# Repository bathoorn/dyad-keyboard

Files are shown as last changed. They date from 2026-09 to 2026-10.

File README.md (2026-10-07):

# Dyad

A split keyboard with a rotary encoder ring on each half — a round display
inside the left ring, a circular trackpad inside the right. Custom PCBs in
KiCad, a 3D-printed case, running QMK.

*Dyad: a pair. Two halves, two dials, two boards.*

Layout

69 keys, 32 left and 37 right, row-staggered. Bare RP2040 on each side.

---

## The idea that makes it work

"A display on top of a knob" normally means the display rotates, which needs a
slip ring or a wire loom that survives unlimited rotation.

Dyad inverts it. **The display and trackpad are static; the ring rotates around
them.** A fixed centre post rises through the bearing bore and cantilevers the
sensor above the moving parts, so no wire ever moves. Visually and
ergonomically it reads as a knob with a screen on top — electrically it's a
static part with a ring turning beneath it.

Both rings are 50 mm outside diameter, so the halves are a matched pair.

## Hardware

| | |
|---|---|
| MCU | Bare RP2040, one **shared controller module** used by both halves |
| Left pod | GC9A01 1.28" round LCD, 240×240, SPI |
| Right pod | Cirque Pinnacle TM040040, 40 mm |
| Encoders | EC11, driven by a ring gear from the rotating ring |
| Switches | MX hot-swap, Kailh sockets |
| Per-key RGB | SK6812MINI-E — footprints fitted, populated only if wanted |
| Split link | USB-C to USB-C, half-duplex serial |

Four board designs: one controller module (the only board needing an assembly
service), two asymmetric main PCBs, and two knob-module variants.

## Status

| Phase | State |
|---|---|
| 0 — Layout | **Done.** Validated against printed 1:1 mock-ups. |
| 1 — Bench bring-up | **Partial.** Toolchain, flashing, encoder and Cirque all pass. Display, ribbon-SPI, split and current tests await parts. |
| 2 — Knob mechanism | Not started. |
| 3 — KiCad | Main PCBs generated and placed; controller pin assignment and BOM settled. |
| 4 — Case | Not started. Board outlines and plate cutouts exported for it. |

The main PCBs are a **placement scaffold**, not a finished layout. DRC reports
195 violations on the left and 253 on the right, **none** electrical (shorts,
clearance, mask bridges). The 32 and 37 errors are all diode/switch courtyard
overlaps from the deliberate diode-under-switch placement; the rest is
silkscreen. Routing is incomplete, notably the angled thumb keys.

## Repository

```
docs/          PLAN.md, WORKFLOW.md, CONTROLLER.md, PHASE1.md, TOOLS.md,
               GIT.md, plus printable 1:1 mock-ups
hardware/
  interface.yaml   the contract between the PCB and case designs
  layout/          KLE source of truth, parser, pod-placement solver
  pcb-main-*/      the two main PCBs (generated)
  pcb-controller/  controller module, and the vendored RP2040 reference
  outlines/        board outlines, plate cutouts and STEP, for the case
firmware/      QMK external userspace
```

Nearly everything under `hardware/` is **generated** from the KLE layout.
Regenerate with `hardware/generate_main_pcbs.py`, `export_outlines.py` and
`export_plate.py` — see `docs/TOOLS.md` for the environment they need.

## Building the firmware

```bash
qmk config user.qmk_home=~/qmk_firmware
qmk config user.overlay_dir=$PWD/firmware
ln -sfn $PWD/firmware/keyboards/dyad ~/qmk_firmware/keyboards/dyad
qmk compile -kb dyad/split -km default
```

The symlink is required: QMK's external userspace holds keymaps and build
targets, but **not keyboards**.

`dyad/proto` and `dyad/split` are Phase 1 bring-up targets for dev boards, not
the shipping keyboard definition.

## Documentation

- **[PLAN.md](docs/PLAN.md)** — the full design, decisions and rationale
- **[WORKFLOW.md](docs/WORKFLOW.md)** — how the case and PCBs are co-designed
  without deadlocking
- **[CONTROLLER.md](docs/CONTROLLER.md)** — controller pin assignment, BOM and
  build steps
- **[PHASE1.md](docs/PHASE1.md)** — bench bring-up, with results
- **[TOOLS.md](docs/TOOLS.md)** — toolchain, and the traps found in it
- **[GIT.md](docs/GIT.md)** — feature branches, and why KiCad files change how
  git is used here

## Licence

MIT — see [LICENSE](LICENSE).

`hardware/pcb-controller/upstream/` vendors
[RP2040-designguide](https://github.com/calliah333/RP2040-designguide)
(MIT, © 2021 Sleepdealer) as a read-only reference. The key layout originates
from the *Hasukey* KLE layout.

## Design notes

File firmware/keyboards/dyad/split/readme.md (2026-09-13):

# Dyad — split proto

Phase 1 steps 7 and 8: two Pico_Mini boards over a TRS cable, Cirque on the
**slave** half.

```bash
qmk compile -kb dyad/split -km default
qmk flash   -kb dyad/split -km default   # flash BOTH boards with this same binary
```

One binary for both halves — `SPLIT_HAND_PIN` decides which is which.

## Wiring

| Pin | Left board | Right board |
|---|---|---|
| GP0 | TRS **tip** — serial data | TRS **tip** |
| GP12 | → **3V3** (this makes it the left/master) | → **GND** |
| GP2–GP5 | *(nothing)* | Cirque SPI0: SCK / SDI / SDO / CS |
| GP6–GP9 | 2×2 matrix | 2×2 matrix |
| GP10, GP11 | EC11 A / B | EC11 A / B |

**TRS cable:** tip = DATA (GP0 ↔ GP0), ring = **5V** (5V pin ↔ 5V pin),
sleeve = GND.

### Plug USB into the LEFT board only

Both halves are powered through the cable's 5 V conductor. QMK decides
master/slave by which side sees USB, so if you plug both in, **both believe
they are master** and the split will not work.

It also means the two USB 5 V rails would be tied together through the cable.
Not usually destructive, but there is no reason to risk it.

### If the link is flaky

Half-duplex serial wants the data line idling high. Add a **4.7 kΩ pull-up
from GP0 to 3V3** on one side. QMK's internal pull-up is often enough on a
short cable and often is not on a long one.

## What to check

| | Expect |
|---|---|
| Left matrix | `A` `B` `C` `D` |
| Right matrix | mouse 1, mouse 2, `E`, `F` |
| Left encoder | volume |
| Right encoder | page up/down |
| **Trackpad on the right half** | cursor moves — this is step 8, the real test |

The trackpad is the point. It proves pointing-device data crosses the split
from the slave, which is what PLAN.md §5 assumed when it put USB in the left
half and the display on the master.

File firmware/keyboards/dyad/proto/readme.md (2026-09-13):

# Dyad — proto

Phase 1 bring-up target. **Not** the shipping keyboard definition.

```bash
qmk compile -kb dyad/proto -km default
qmk flash   -kb dyad/proto -km default   # hold BOOTSEL while plugging in
```

## Wiring — WinWin Pico_Mini RP2040

| Pins | Peripheral | Notes |
|---|---|---|
| GP2 / GP3 / GP4 / GP5 | Cirque TM040040 | SPI0 SCK / SDI / SDO / CS. DR unwired, so the driver polls. |
| GP6, GP7 / GP8, GP9 | 2×2 matrix | cols / rows, COL2ROW. Nothing need be wired. |
| GP10, GP11 | EC11 A / B | Encoder common (middle pin) → GND. QMK enables internal pull-ups. |

### EC11

Three pins on one side: **A — common — B**. Wire A to GP10, B to GP11, and the
middle pin to GND. The two pins on the opposite side are the push switch.

**Knock off step 2 for free:** the push switch is just a normally-open switch,
so wire it into the matrix as position `[0][0]` — one leg to col `GP6`, the
other through a 1N4148 (band toward the row) to row `GP8`. Pressing the knob
then sends `MS_BTN1` and proves the matrix scan at the same time.

## What it does

| Input | Result |
|---|---|
| Trackpad | Cursor movement |
| Encoder rotation | Volume down / up |
| Matrix `[0][0]` / `[0][1]` | Mouse button 1 / 2 |
| Matrix `[1][0]` / `[1][1]` | `A` / `B` |

## If the encoder misbehaves

Two detents per click, or one click per two detents, is a **resolution**
mismatch, not a wiring fault. Add `"resolution": 2` (or `4`) to the rotary
entry in `keyboard.json`. Direction reversed: swap `pin_a` and `pin_b`.

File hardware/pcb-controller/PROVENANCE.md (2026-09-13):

# Upstream reference: RP2040-designguide

Vendored from **https://github.com/calliah333/RP2040-designguide**
at commit `2023-02-13` ("Merge branch 'main'"), MIT licensed,
**Copyright (c) 2021 Sleepdealer** — see `LICENSE`, retained unmodified as MIT
requires.

This is a **read-only reference**, not the Dyad controller. Do not edit it in
place; the Dyad board is `../dyad-controller.kicad_pcb`.

## Why this one

- MIT, so it can be used and adapted in an MIT project with attribution.
- **2-layer**, independently confirming the layer-count decision in PLAN.md §4.
- Carries a vetted RP2040 QFN-56 footprint *and* a STEP model, which the stock
  KiCad libraries do not provide together.
- Decoupling matches what the minimal design example calls for: 10 × 100 nF,
  1 µF and 10 µF bulk, 2 × 22 pF crystal loads.

## What was left behind

`Pico-Resources/` (41 MB) — the RP2040 datasheet, the Pico schematic and
*Hardware design with RP2040*. Freely available from Raspberry Pi, and too
large to justify vendoring. Download them directly when running the §4
schematic diff.

## Age

Last real commit February 2023, KiCad 6 file format (`version 20211014`).
KiCad 10.0.6 loads it without complaint — verified: 36 footprints, 59 nets,
2 copper layers. Expect a format-upgrade prompt on first save.

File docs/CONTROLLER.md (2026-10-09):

# Controller module

One design, used on **both** halves. The only board in the project that needs
an assembly service, and the one Phase 4.5 orders first and alone.

Envelope: **50 × 35 mm, ≤10 mm above the PCB**, 2-layer, 1.6 mm.
Tallest parts are now the tactile buttons (~5 mm); the USB-C receptacles are ~3.2 mm. Dropping the 3.5 mm jack freed real height.
Fixed by decree (`interface.yaml`) — the case guarantees the volume, the board
fits inside it, neither renegotiates. See `docs/WORKFLOW.md` §2.

---

## 1. Pin assignment

30 GPIO available (GP0–GP29). USB and QSPI are on dedicated pins and cost
nothing from this budget.

| GPIO | Function | Constrained? |
|---|---|---|
| GP0 | HANDEDNESS — from the main PCB | no |
| GP1–GP8 | MATRIX_COL7–0 (GP1 = COL7 … GP8 = COL0) | no |
| GP9–GP13 | MATRIX_ROW0–4 | no |
| GP14 | RGB_DATA — WS2812/SK6812, PIO | no |
| GP15 | SPLIT_SERIAL — half-duplex, PIO | no |
| GP16 | **KNOB_D0** — SPI0 RX *or* I²C0 SDA | **yes** |
| GP17 | **KNOB_D1** — SPI0 CSn *or* I²C0 SCL | **yes** |
| GP18 | KNOB_SCK — SPI0 SCK | **yes** |
| GP19 | KNOB_MOSI — SPI0 TX | **yes** |
| GP20 | KNOB_CS — display chip select (software CS) | no |
| GP21 | KNOB_DC — display data/command | no |
| GP22 | KNOB_RST — display reset | no |
| GP23 | KNOB_BL — display backlight (PWM) | no |
| GP24 | KNOB_DR — Cirque data-ready | no |
| GP25 | ENC_A | no |
| GP26 | ENC_B | no |
| GP27, GP28, GP29 | **spare** | all three ADC-capable |

**Reassigned 2026-10-07** for routing -- see *Why this assignment* below. The
first assignment (knob on GP0–10, matrix on GP12–26) predates any placement
and is in git history. The schematic carries this table: U3's labels name the
physical pin, and only the connector-side labels moved.

**27 used, 3 spare.**

Only four pins are actually pinned down by silicon. Everything else — chip
selects, DC/RST/BL, the encoder, the matrix, the split link, RGB — is free
choice, because RP2040 drives software CS on any pin and PIO reaches any pin.

### GP16/GP17 settle the Cirque bus question by not answering it

`docs/PHASE1.md` §5a left one decision open: the plan puts the Cirque on I²C,
but the bench module is SPI-strapped and works. That decision does **not** need
making before this board is laid out.

RP2040's function map overlaps exactly where it helps:

| Pin | As SPI | As I²C |
|---|---|---|
| GP16 | SPI0 RX (MISO) | I²C0 SDA |
| GP17 | SPI0 CSn | I²C0 SCL |

So both lines go to the knob connector as **KNOB_D0/KNOB_D1**, and the choice
is made in firmware plus how the *knob module* wires its two pads. The
controller is identical either way, and the same 14-pin connector serves both
knob variants. Neither costs an extra pin.

### Why this assignment: routing (2026-10-07)

The first assignment was chosen before any placement existed, and it put the
knob bus on the side of the RP2040 that faces *away* from the knob FFC. The
table above replaces it, derived from geometry as §2 asks. **Applied to the
schematic 2026-10-07.**

**Placement it assumes** (decided 2026-10-07): parts on **B.Cu**, as upstream;
board **35 wide x 50 deep** (lengthened to **57 mm** on 2026-10-09 -- see §6
results), so the side edges are the long ones. U3 keeps
its upstream orientation (B, 180 deg), which is the only one that points its
USB/QSPI face at the rear edge and J1. All directions below are KiCad's top
view, front = +y.

| RP2040 face | Pins | Faces | Carries |
|---|---|---|---|
| USB/QSPI | 43-56 | rear | J1, flash -- unchanged |
| GP12-17, XIN/XOUT, SWD, RUN | 15-28 | front | crystal, SWD, RUN; knob from GP16 leftward |
| GP18-29 | 29-42 | left | knob (GP18-26), spares |
| GP0-11 | 1-14 | right | matrix bus |

**Connector pin 1, on B.Cu** (measured on main-right's J1, which uses the same
footprint family: the cable enters on the mounting-pad side):

- J8, front edge, opens +y: pin 1 on the **right**, pins run right to left.
- J7, right edge, opens +x: pad 1 at the **rear**, pad 20 at the front.
- J6, left edge, opens -x: pad 1 at the **front**, pad 20 at the rear.

**The knob keeps the dual-function trick.** GP16/GP17 overlap exactly as
GP0/GP1 do -- SPI0 RX/CSn *and* I²C0 SDA/SCL -- with SPI0 SCK/TX on GP18/GP19.
The whole knob group is now one contiguous run of 11 pins wrapping the
front-left corner, fanning straight into J8 with no crossings.

**J8 changes in one place.** Arriving right to left, the chip presents
D0, D1, SCK, MOSI, CS, DC, RST, BL, DR, ENC_A, ENC_B. So the §2 table's
pins 3-6 were reordered to **3 D0, 4 D1, 5 SCK, 6 MOSI** (they were SCK,
MOSI, D0, D1); pins 7-13 are unchanged. The knob module does not exist yet,
so this cost nothing.

**The matrix leaves the chip as one ordered bundle to the right.** GP0-15,
read rear to front around the front-right corner, run HAND, COL7..COL0,
ROW0..ROW4, LEDIN, SPLIT. That is J7's pad order exactly (rear to front:
1 HAND, 3-10 COL7..COL0, 11-15 ROW0..ROW4, 17 LEDIN), so J7 is crossing-free,
with SPLIT outermost, toward J9 if J9 sits in front of J7.

**J6 is reached by wrapping the rear of the chip, and that wrap is free.** J6
presents the same nets in the *opposite* front-to-rear order, because it is
J7 rotated 180 degrees. A bundle that turns three corners around the rear of the
chip reverses its order once on the way, which is exactly the reversal J6
needs. So the §2 worry that an identical assignment "must cross all 20 nets"
does not hold here, and J6/J7 can keep the same net-to-pad table.

**What it still costs:** one layer change per net. On a single layer, at most
two nets can each reach both side edges past a chip in the middle, so this is
inherent, not a pin-order problem. Where each net splits into its J7 branch
and its J6 branch, one branch has to hop under its neighbours. Keep the long
wrap bundle on **B.Cu** (component side, in a part-free band behind the chip
and flash) and make only the short hops on F.Cu, so the F.Cu ground plane is
slotted briefly, not cut across. USB D+/D- also cross that band, as a short
F.Cu hop of their own. The power pads interleaved with the signals (3V3 at
pad 2, GND at 16/18) take a via each.

**Placement this implies:** J1, ESD, F1 and D1 along the rear; a component-free
band of ~7 mm behind U3+U1 for the wrap; J6/J7 on the side edges level with
U3, J9/J10 in front of them; crystal and SWD in front of U3, to the right of
the knob bundle, with J8 at front-left.

**As built (2026-10-09), the side edges are the other way round:** split
USB-C J10/J9 on top (y 29 from the rear edge), main FFC J6/J7 below them
(y 41.8), on the 57 mm board. The 20-pin FFCs need far more routing room
than the three-net USB-C ports, and the lower half of the board has it --
moving them there is what finally kept the matrix bundle from crossing
under the USB and QSPI routing (§6 results). The SWD header no longer
exists (§4).

**Open before applying:**

- `interface.yaml` has no `positions_controller` yet, and the cable type A/B
  question in §2 still stands. Everything here assumes a straight, unfolded
  ribbon.
- The ground-pour layer moves with the parts. With parts on B.Cu, **F.Cu** is
  the continuous plane that PLAN.md asks for, not B.Cu as §2 says.
- Firmware is unaffected for now: `dyad/proto` and `dyad/split` use the
  bench rig's wiring, not the controller's.

---

## 2. Connector pinouts

**Knob FFC, 14-pin 0.5 mm** — 11 signals + power. **In the schematic as J8
since 2026-09-18.**

**The `#` column below is the CONTROLLER's pin numbering**, which is how J8
is wired. The knob module does not exist yet, so it will be designed to
match: for a facing, straight, unfolded ribbon its pads are the reverse,
`knob pad m = controller pin (15 - m)` — the same relation as the main FFC,
for the same reason. Do not wire the knob module off this table directly.

| # | Signal | Display variant | Cirque variant |
|---|---|---|---|
| 1 | 3V3 | ✓ | ✓ |
| 2 | GND | ✓ | ✓ |
| 3 | KNOB_D0 | — | MISO *or* SDA |
| 4 | KNOB_D1 | — | CS *or* SCL |
| 5 | KNOB_SCK | SCK | SCK *(SPI mode)* |
| 6 | KNOB_MOSI | SDI | SDI *(SPI mode)* |
| 7 | KNOB_CS | display CS | — |
| 8 | KNOB_DC | D/C | — |
| 9 | KNOB_RST | RST | — |
| 10 | KNOB_BL | backlight | — |
| 11 | KNOB_DR | — | data-ready |
| 12 | ENC_A | ✓ | ✓ |
| 13 | ENC_B | ✓ | ✓ |
| 14 | GND | ✓ | ✓ |

**Main FFC, 20-pin 0.5 mm:** 13 matrix + handedness + RGB_DATA + 3V3 + 2× 5V
+ 2× GND. The doubled 5 V and GND are the per-key RGB return path; a 0.5 mm
FFC conductor is good for roughly half an amp. See PLAN.md §5.

**This table is the MAIN PCB's pin numbering, not the controller's.** The
controller's pads are the reverse of it -- see *Facing connectors reverse*
below. Wiring the controller straight off this table is the single easiest
way to get the whole link backwards.

Pin assignment on **both main PCBs**, fixed by main-right and matched by
main-left:

| Pin | Net | | Pin | Net |
|---|---|---|---|---|
| 1 | VCC (5 V) | | 11 | COL0 |
| 2 | VCC (5 V) | | 12 | COL1 |
| 3 | GND | | 13 | COL2 |
| 4 | LEDIN | | 14 | COL3 |
| 5 | GND | | 15 | COL4 |
| 6 | ROW4 | | 16 | COL5 |
| 7 | ROW3 | | 17 | COL6 |
| 8 | ROW2 | | 18 | COL7 *(idle on left)* |
| 9 | ROW1 | | 19 | +3V3 |
| 10 | ROW0 | | 20 | HAND |

Rows descend where columns ascend -- ascending rows made the five row traces
cross on their way to the connector. LEDIN sits between the two GNDs because
it is the only fast edge on the cable.

### Facing connectors reverse: controller pad n carries main pin 21-n

The main PCB's connector and the controller's face each other across the
ribbon. Two identical right-angle parts opening toward one another are
rotated 180 degrees about z relative to each other, so the topmost conductor
in the ribbon lands on pin 1 at one end and pin 20 at the other:

    main pin n  <->  controller pad (21 - n)

**This reversal is identical on both halves, which is why it costs nothing.**
Right half: main-right opens inward (-x), the controller's right-edge part
opens +x -- 180 degrees apart. Left half: main-left opens inward (+x), the
controller's left-edge part opens -x -- also 180 degrees apart. Check it on
the topmost conductor: on the right it joins controller pad 20 to main pin 1;
on the left it joins controller pad 1 to main pin 20. Same `21-n` relation.

So **both controller footprints take the same net-to-pad assignment**, and
both mains keep the same pinout. The reversal is absorbed once, here.

Written out -- **corrected 2026-09-18**, the first transcription of this
table was wrong and is why it carried a "not verified" warning. It repeated
COL0-6 in both halves and omitted ROW3, ROW4, both GNDs, LEDIN and both
VCCs. Derived here pad by pad as `pad m = main pin (21 - m)`, and the
right-hand column gives the controller's own net name:

| Pad | Signal | Net | | Pad | Signal | Net |
|---|---|---|---|---|---|---|
| 1 | HAND | GPIO0 | | 11 | ROW0 | GPIO9 |
| 2 | +3V3 | +3V3 | | 12 | ROW1 | GPIO10 |
| 3 | COL7 | GPIO1 | | 13 | ROW2 | GPIO11 |
| 4 | COL6 | GPIO2 | | 14 | ROW3 | GPIO12 |
| 5 | COL5 | GPIO3 | | 15 | ROW4 | GPIO13 |
| 6 | COL4 | GPIO4 | | 16 | GND | GND |
| 7 | COL3 | GPIO5 | | 17 | LEDIN | GPIO14 |
| 8 | COL2 | GPIO6 | | 18 | GND | GND |
| 9 | COL1 | GPIO7 | | 19 | VCC 5 V | **+5V** |
| 10 | COL0 | GPIO8 | | 20 | VCC 5 V | **+5V** |

Count check: HAND 1, +3V3 1, COL0-7 8, ROW0-4 5, GND 2, LEDIN 1, VCC 2 = 20.

**The 5 V pins land on `+5V`, not `VBUS`.** `VBUS -> F1 -> +5V`, so `+5V` is
the *fused* rail, and §3 already notes the fuse is deliberately in the LED
path -- which is the whole reason it needs upsizing if RGB is populated.
Taking the FFC's 5 V from VBUS instead would put the LED current outside the
fuse and quietly defeat that.

### The two footprints need not share an assignment -- and probably should not

The footprints are separate copper. Nothing forces them to carry the same
net-to-pad order, and **that is the mechanism for reversing one half's
pinout without touching the other.** If main-left wants its pins reversed to
ease routing, the controller's left-edge footprint absorbs it and the MCU
never knows. No firmware asymmetry: this **supersedes** the
`MATRIX_ROW_PINS_RIGHT` escape hatch named in MANUAL_TASKS.md, which cost a
permanent left/right difference in the build.

There is a second, independent reason to expect the reversal, and it is
about the *controller's own* routing. Number pad positions by height `y`,
with both footprints opening outward on opposite edges so they sit 180
degrees apart:

    identical assignment   net j at y = 21-j  (right)   y = K-j  (left)
                           -> the two run in OPPOSITE directions, so a
                              centre-mounted MCU must cross all 20 nets to
                              reach the left connector

    reversed on the left   left pad m = net m, right pad m = net 21-m
                           -> net j at y = 21-j and y = K-j, both falling
                              at the same rate: a PARALLEL fan-out, no
                              crossings

The controller is **2 layers**, and B.Cu is the ground pour that PLAN.md
requires to stay continuous under the MCU. Twenty crossings would be twenty
via pairs punched through exactly that copper. So the reversal plausibly
buys clean routing here as well as on main-left.

**Not proven.** This is a topology argument about a layout that does not
exist -- the controller outline is still the 45.31 x 93.52 mm reference
shape, not the 50 x 35 envelope. It assumes both footprints sit on the same
side of the board, on opposite edges, opening outward. Put one on the
opposite copper layer and they are mirrored rather than rotated, and the
ordering changes. Confirm it against the real placement before relying on
it, and **derive both pad tables from geometry at schematic time rather than
transcribing them.**

**Caveat, and it is the live one.** All of the above assumes the boards are
effectively coplanar and the ribbon runs **straight and unfolded**. If the
controller ends up stacked under the main PCB with a folded ribbon, the
mapping changes -- a fold reverses conductor order *and* flips the contact
face.

So treat **(controller pad assignment, cable type A/B)** as a pair with one
degree of freedom: a type-B cable flips the reversal straight back. Fix one
and the other follows. Neither can be finalised until
`positions_controller` and the ribbon path are settled -- both still TODO in
`interface.yaml`. The main pinout is the only part that is genuinely frozen.

### The 5 V OR-ing network (added 2026-09-18)

PLAN.md §5 rule 3 asks for a fused split VBUS and an OR-ing Schottky. Where
the Schottky goes is not free choice — it is what decides whether one half
can power the other:

```
  host VBUS ──F1──► VBUS_FUSED ──►|D1──┬──► +5V  (LDO, ESD, LED rail via J6/J7)
                                        │
                     split VBUS ──F2────┘        (J9/J10, to the other half)
```

`+5V` is the **shared node**: it feeds this half and reaches the other half
through F2 and the cable. Each half's own VBUS enters through its own D1,
so two hosts can never be connected VBUS-to-VBUS — which is the actual
hazard rule 3 names. One port still powers both halves, because the shared
node crosses the link.

**Why not the obvious alternatives.** A diode on *each* input into +5V
(host and split) blocks cross-half power entirely — neither half can feed
the other. A diode only on the split *input* is worse: the receiving half
gets power but no half can ever send it. The Schottky has to sit in the
**host** path for the shared node to work.

**Consequence worth pricing in: `+5V` is now ~4.6 V, not 5.0 V.** SS34 drops
about 0.4 V at 1 A. Everything downstream still has margin — XC6206 needs
~3.55 V in for 3.3 V out, and SK6812MINI-E is specified from 3.7 V — but
**PLAN.md §5's per-key RGB brightness budget assumes a 5 V rail** and should
be re-checked against 4.6 V before the LED ceiling is treated as final.

SS34 was chosen over the 1 A B5819W (C8598, also Basic) for headroom: with
one port feeding both halves at capped RGB brightness the diode carries the
whole board, and 3 A leaves room. F2 reuses F1's part and footprint.

### Port placement: host to the rear, split duplicated on the side edges

**Decided 2026-09-18.** The host USB-C (J1) stays a **single** footprint on
the **rear** edge. The split USB-C is **duplicated** on the left and right
edges as J9/J10, one populated per half — whichever faces the other half.

The single controller orientation that the two-FFC decision buys means a
rear-edge port lands identically in both halves, so the host needs no
duplicating. The split port is duplicated for **usability, not geometry**:
§5 of PLAN.md warns that "two identical USB-C ports per half invite the
wrong cable. Distinguish them by case position and labelling." Two ports
side by side on the rear are *not* distinguishable by position — and on the
slave half, where no host cable is plugged in, there is nothing to compare
against. Putting the split port on the inboard edge makes it structurally
unmistakable: the cable that goes to the other half comes out of the side
that faces it.

Each side edge therefore carries one main FFC and one split USB-C, and
exactly one of each pair is populated, on **opposite** edges:

| Edge | Left half populates | Right half populates |
|---|---|---|
| left | J6 main FFC | J10 split USB-C |
| right | J9 split USB-C | J7 main FFC |
| rear | J1 host USB-C (always) | J1 host USB-C (always) |
| front | J8 knob FFC (always) | J8 knob FFC (always) |

Edge budget: each side edge carries 13 mm of FFC + ~9 mm of USB-C = 22 mm,
against 35 mm if the board is oriented 50 wide by 35 deep. Tight but
workable; if it binds, orienting the board the other way gives the side
edges 50 mm. **As built:** turned (2026-10-07) and lengthened to 57 mm
(2026-10-09), so each side edge is 57 mm, carrying the split USB-C
(courtyard 10.7 mm) above the main FFC (14.5 mm), with the BOOTSEL / RESET
button and a corner mounting hole above them.

**Stubs are not a concern here.** RP2040 is USB 1.1 **Full Speed, 12 Mbps**
(PLAN.md §Routing), so the unpopulated footprint's stub is electrically
irrelevant. That is why duplicating a USB-C costs only board area.

**D+/D- is deliberately left unconnected on the split ports.** The split
link is not USB — it carries half-duplex serial on SBU. Wiring D+/D- there
would mean a C-to-C split cable shorting the two halves' RP2040 USB data
lines together, with both device PHYs driving. CC1/CC2 and both D pairs
carry explicit no-connect flags on J9 and J10.

### Two main-FFC footprints, one populated (decided 2026-09-18)

**The controller carries the 20-pin footprint on two edges, wired to the
same nets, and only the one facing that half's main PCB is fitted.**

Each half's J1 sits on its *inner* board edge, so the two cable approaches
are mirror images. A mirror is not a rotation: turning the controller 180
degrees swaps left/right *and* top/bottom, putting the main FFC on the right
edge but USB-C on the wrong one. Only flipping the board over truly mirrors
it, and that faces every component at the case floor and inverts the USB-C.

With two footprints, each one's orientation is chosen independently, so the
mirror is absorbed here in copper -- on the board WORKFLOW.md §2 names as
having "enormous slack" and costing ~$15 to respin, rather than on the mains
which have none and one of which is already routed. Both halves then share
one cable type, one logical pinout and one firmware build.

Consequences for layout:

- Budget about **13 mm of edge twice** for the 20-pin parts, plus ~9 mm for
  the knob FFC and ~9 mm each for the two USB-C -- roughly **53 mm of the
  ~170 mm perimeter**.
- The unpopulated footprint leaves a **stub on all 20 nets**. Irrelevant for
  matrix and power; keep the LEDIN stub short, since it is the only line
  with fast edges.
- `interface.yaml` must eventually say **which** edge is populated per half,
  since the case has to admit the ribbon from the correct side.
- Cable type A vs B is now settleable: both connector orientations are fixed
  by this decision plus main-left's placement.

---

## 3. BOM

**Inherited from the reference, LCSC codes already populated** (31 parts, 14
distinct codes — nothing to look up):

| Ref | Part | LCSC | |
|---|---|---|---|
| U3 | RP2040, QFN-56 | **C2040** |
| U1 | W25Q128JVS, 16 MB SOIC-8 | **C131025** |
| Y1 | Abracon ABM8-272-T3, 12 MHz, CL 10 pF, 3225 4-pin | **C20625731** | ← **swapped 2026-10-07**, see below |
| U2 | USBLC6-2SC6 ESD, SOT-23-6 | **C2827654** |
| U4 | XC6206 LDO 3.3 V / 200 mA, SOT-23 | **C5446** |
| J1 | USB-C receptacle, HRO TYPE-C-31-M-12 | **C165948** |
| F1 | 500 mA fuse, 1206 | **C70076** | ← **upsize if RGB is populated**: it is in the LED path
| C1–C17 | 10× 100 nF, 4× 1 µF, 1× 10 µF, 2× 15 pF (C2/C3), all 0402 | C1525 / C52923 / C15525 / **C1548** |
| R1,R2,R7 | 1 kΩ 0402 | C11702 |
| R3,R4 | 5k1 CC 0402 | C25905 |
| R5,R6 | 27 Ω 0603 | C25190 |

**The inherited crystal did not match its load caps.** The reference design
carried LCSC C9002 (YXC X322512MSB4SI): CL **20 pF**, ESR **80 Ω**, with
22 pF load caps. Those give ~11 + 3 pF stray = ~14 pF against the 20 pF it
needs, so it would run fast -- and its 80 Ω ESR is above the 50 Ω that
*Hardware design with RP2040* §2.3 relies on when sizing the 1 kΩ XOUT
series resistor, so start-up margin was unknown. The guide says any other
crystal circuit "will require extensive testing". Swapped to the guide's own
circuit unchanged: ABM8-272-T3 (CL 10 pF, ESR ≤ 50 Ω), two 15 pF caps
(7.5 pF + ~3 pF stray = 10.5 pF), 1 kΩ (R7). Same 3.2 × 2.5 mm 4-pad
package and pin-out, so the footprint and routing are unchanged. Found by
the §6 checklist, item 3.

Passives are 0402. That is finer than the "0805, hand-solderable" assumption in
PLAN.md §10, but these are on the *assembly* BOM — JLCPCB places them, so it
does not matter.

**Still to add — none of these exist on a bare dev board.** Now **in the
schematic** and footprinted: J6 (main FFC, left), J7 (main FFC, right),
J8 (knob FFC), J9/J10 (split USB-C, one per side edge), F2 (split-VBUS
fuse), D1 (OR-ing Schottky), and SW1/SW2 (BOOTSEL and RESET). Still absent:
the DNP 74AHCT125 level shifter, and conditionally the LDO swap — which is
the only remaining item from §4, and is gated on a Phase 1 measurement.

| Block | Part | LCSC | Note |
|---|---|---|---|
| Split | **USB-C receptacle** (**two** placements) | **C165948** | Same part as J1 — no new line on the BOM. CC1/CC2 **unconnected**; serial on SBU1+SBU2 tied; fuse its VBUS. **In the schematic as J9 and J10 since 2026-09-18**, one per side edge, **one populated per half**. |
| Knob FFC | HC-FPC-0.5-**14P**-FH20 | **C19273929** | 0.5 mm, flip-top, right-angle, bottom contact. **In the schematic as J8 since 2026-09-18**, footprint `dyad:FPC-SMD_14P-P0.50_HC-FPC-0.5-14P-FH20`. |
| Main FFC | HC-FPC-0.5-**20P**-FH20 | **C19273932** | 20-position sibling. Confirmed 2026-09-18: JLCPCB Extended, 1,893 in stock, $0.076/1-99. **Two footprints** -- see §2. **In the schematic as J6 (left) and J7 (right) since 2026-09-18**; population per board still open. |
| Level shift | 74AHCT125 | *verify* | **DNP**, 0 Ω bypass. RGB only. |
| Power OR | **SS34** Schottky, SMA | **C8678** | Stops one half back-feeding the other. JLCPCB **Basic**, 3 A / 40 V. **In the schematic as D1 since 2026-09-18.** |
| Buttons | **TS-1187A-B-A-B**, 5.1×5.1 mm SMD | **C318884** | SW1 (BOOTSEL) + SW2 (RESET). JLCPCB **Basic**, 679k stock. KiCad ships the matching footprint, `Button_Switch_SMD:SW_Push_1P1T_XKB_TS-1187A`, whose pads are numbered 1,1,2,2 so the 2-pin `SW_Push` symbol fits directly. **In the schematic since 2026-09-18.** |
| LDO *(conditional)* | AP2112K-3.3, SOT-23-**5** | *verify* | Only if Phase 1 measures above ~120 mA. Not a drop-in — see §4. |

LCSC codes marked *verify* should be pulled with `easyeda2kicad` at schematic
time so the design-side footprint matches the assembly-side part exactly
(see `docs/TOOLS.md`).

### FFC connector choice

Staying at **0.5 mm pitch**. 1.0 mm parts (e.g. Amphenol F516) are easier to
hand-solder and carry more current, but neither helps here: JLCPCB places
these, and the doubled 5 V/GND conductors already give ~1 A against ~0.4 A per
half for RGB at capped brightness. What 1.0 mm does cost is board edge — a
20-position part is ~23 mm wide instead of ~13 mm, on a 50 mm board whose other
long edge already carries USB-C and the jack.

**Right-angle, not vertical.** The same family's `LH20` variant (C49166895) is
a vertical slide-lock part: the ribbon exits perpendicular to the board and
must then bend, which wants headroom the 10 mm envelope does not have to spare.
`FH20` is right-angle, so the ribbon lies flat.

**Cable type is a real trap.** These are *bottom contact*. FFC cables come as
type A (contacts the same side at both ends) and type B (opposite sides). Which
one is correct depends on how both connectors end up oriented in layout, and
the wrong type silently reverses the pinout end to end. Settle it once the
layout fixes the orientations, not before.

---

## 4. Starting point: the RP2040 design guide

The MCU subsystem is not being drawn from scratch. `hardware/pcb-controller/upstream/`
vendors **calliah333/RP2040-designguide** (MIT, © 2021 Sleepdealer) as a
read-only reference — see its `PROVENANCE.md`. It is 2-layer, carries a vetted
QFN-56 footprint with a STEP model, and its decoupling already matches the
minimal design example.

Verified to load in KiCad 10.0.6 despite being KiCad 6 format: 36 footprints,
59 nets, 2 copper layers.

### What transfers unchanged

RP2040 + QFN-56 footprint, W25Q128JVS (exactly our 16 MB flash), the 12 MHz
crystal's footprint and 1 kΩ series resistor (the crystal itself and its load
caps did **not** transfer -- see §3), USBLC6-2SC6 ESD, USB-C with 27 Ω series and 5k1 CC resistors,
the full decoupling network, and a 500 mA VBUS fuse. Its SWD header (J2) was
carried over and then **removed 2026-10-07**: the 13.8 x 3.6 mm through-hole
socket was the largest single part on the board, and dropping it let the
RP2040 block move 4 mm forward so USB could be routed cleanly (see §6
results). Flashing is over USB with BOOTSEL; SWCLK/SWDIO (U3 pins 24/25) are
left unconnected. If SWD is ever wanted back, three small SMD test pads
(SWCLK, SWDIO, GND) would cost almost no board area.

### What must change

Item 1 is conditional on a measurement; 2–6 are unconditional.

| # | Change | Why |
|---|---|---|
| 1 | **LDO: XC6206 → AP2112K-3.3** *(only if measured >~120 mA)* | XC6206 is **200 mA**. Load is ~70–130 mA — RP2040 ~30, flash ~5, Cirque ~3, and the GC9A01 backlight 20–60. At the top of that range there is no margin left. **Not a drop-in:** SOT-23 3-pin → SOT-23-**5**, and EN must be tied to Vin or the rail never comes up. LEDs do **not** load this rail. Confirm against the Phase 1 measurement. |
| 2 | ~~**Add a RESET button**~~ **DONE 2026-09-18** | The guide has none. PLAN.md §4 treats it as non-optional. Added as SW2, `~{RESET}` to GND. |
| 3 | ~~**Replace SW1**~~ **DONE 2026-09-18** | Its BOOTSEL "switch" was a `PinSocket_1x02` header, not a button. Now a real tactile switch, same part as SW2. |
| 4 | ~~**Delete J3/J4/J5**~~ **DONE 2026-09-18** | Three 1×11 pin sockets — it is a Pico-style breakout. We want FFC connectors instead. Removed with their 33 stubs, 30 labels and 3 now-orphaned GND symbols. |
| 5 | **Add** a 2nd USB-C (split link), 20-pin + 14-pin FFC, 74AHCT125 (DNP), power OR-ing diode, split-VBUS fuse | None are in a bare dev board. The 2nd USB-C reuses J1's part and footprint. |
| 6 | **Reshape to 50 × 35 mm** | The guide's board is 45.3 × 93.5 mm. |

Items 1–3 are the ones that would ship a broken or unflashable board if missed.

## 5. Step by step

### Before you start

`upstream/` is a **read-only reference**. Nothing below edits it — after step 1,
`git status` should show no changes under `hardware/pcb-controller/upstream/`.
If it does, you saved into the wrong place.

Close KiCad before running any generator script in this repo. KiCad writes on
exit and will happily undo a regeneration.

### 1. Make the working copy

The upstream project carries its own project-local `fp-lib-table` and
`sym-lib-table`, and they point at `Libraries/` by **relative** path. Save-As
does not bring those along, so copy them first or the RP2040 symbol and
footprint go missing:

```bash
cd hardware/pcb-controller
cp -r upstream/Libraries upstream/fp-lib-table upstream/sym-lib-table .
```

Then in KiCad: open `upstream/RP2040-Guide.kicad_pro` → **File → Save As** →
into `hardware/pcb-controller/`, filename **`dyad-controller`**. Accept the
KiCad 6 → 10 format upgrade when prompted.

Commit at this point, before editing anything. It gives you a clean "unmodified
upstream, renamed" baseline to diff every later change against.

### 2. Schematic (Eeschema) — always before the PCB

Work the deltas from §4 in this order; it minimises rework.

1. ~~**Delete J3, J4, J5**~~ — **done 2026-09-18**, along with the 33 wire
   stubs, 30 labels and 3 GND symbols that fed only them.

   This left 15 ERC errors, which were the map of what was still missing:
   each removed header had been the second connection on its GPIO net.
   **The knob FFC (J8) cleared 11 of them**, leaving **4**: `GPIO11`, which
   clears with the second USB-C, and `GPIO27-29`, the three genuine spares,
   which want no-connect flags once that is confirmed final.
   Nothing else regressed: `endpoint_off_grid` fell 136 -> 94 and
   `lib_symbol_mismatch` 52 -> 49, because the headers took their own
   off-grid pins with them.
2. **Swap the LDO.** Replace U4 (XC6206) with AP2112K-3.3. This is a footprint
   change, not a value change: **SOT-23 3-pin → SOT-23-5**. Tie **EN to Vin** —
   left floating, the regulator never turns on and the board has no 3V3, which
   presents as a dead board rather than as a missing jumper. Dropout is not a
   factor either way: from 5 V there is 1.7 V of headroom.
3. ~~**Fix the buttons.**~~ **done 2026-09-18.** SW1's footprint was a
   `PinSocket_1x02`; it is now `Button_Switch_SMD:SW_Push_1P1T_XKB_TS-1187A`.
   SW2 added from `~{RESET}` (the RP2040's `RUN`, U3 pin 26) to `GND`, same
   part.

   Note when wiring to `~{RESET}`: it is a **global** label on this sheet, and
   `batch_connect_to_net` only writes local ones — which raises
   `same_local_global_label`. Use a global label there.
4. **Add the new parts:** PJ-320A jack, 20-pin and 14-pin FFC connectors,
   74AHCT125 (mark **DNP**, with a 0 Ω bypass), and the Schottky between VBUS
   and the jack's 5 V.
5. **Wire to the pin assignment in §1.** GP18/GP19 must be SPI0 SCK/MOSI and
   GP16/GP17 the dual-function pair — those four are fixed by silicon. The rest
   is free.
6. **Annotate**, then run **ERC** and get it clean.

### 3. PCB (Pcbnew)

7. **Tools → Update PCB from Schematic** (F8). Everything new lands in a heap
   off-board; that is expected.
8. **Replace the outline.** Delete all existing `Edge.Cuts` — the guide's board
   is 45.3 × 93.5 mm. Then **File → Import → Graphics**, choose
   `../outlines/dyad-controller-outline.dxf`, place it on **Edge.Cuts** at
   **scale 1.0**. It is 50 × 35 mm, normalised to the origin.
9. **Place the edge parts first**, because they are the real constraint:
   **both** USB-C receptacles on one long edge, both FFC connectors on the other.
   Separate the two USB-C ports as far as the edge allows and silkscreen them
   clearly — they are physically identical.
   Everything else fits around them.
10. **Then the MCU block** — keep RP2040, crystal and decoupling together and
    as the guide has them. Do not redistribute the decoupling.
11. **Route**, pour ground both sides, stitch the RP2040 centre pad with ~9
    vias, and run **DRC**.

### 4. Before ordering

12. Run the §6 checklist below, diffing block by block against *Hardware design
    with RP2040* Chapter 2.
13. **Add LCSC part numbers** to a symbol field named `LCSC` for every
    assembled part — that is what JLCPCB reads. Pull footprints with
    `easyeda2kicad` so the design-side part matches the assembly-side one.
14. Export gerbers, BOM and CPL (`kicad-cli pcb export gerbers` / `drill`, and
    the BOM/position files from Eeschema and Pcbnew).

## 6. Before ordering

Run the §4 checklist in `PLAN.md` — schematic diffed block-by-block against
Raspberry Pi's *Hardware design with RP2040* Chapter 2 minimal design example.
Boards that fail to enumerate are almost always boards that deviated from it.

The two that bite hardest:

- **BOOTSEL button is not optional.** Without it an unflashed board is a brick
  until you short pads with tweezers.
- **Ground pour continuity.** Easier here than it would have been on the main
  PCBs, because no matrix crosses this board. Stitch the centre pad with ~9
  vias and check the *poured* result, not the schematic intent.

**Correction to the last point:** the matrix *does* cross this board. J6 and
J7 carry the same 15 nets on opposite side edges, so the bundle has to get
past the RP2040's USB connections or its knob bus, and it does so on F.Cu --
the layer that would otherwise be the continuous ground. That is the root of
the ground-coverage numbers below.

### Checklist results (2026-10-07)

Run against *Hardware design with RP2040* (RP-008279-DS-2), Chapter 2.

| # | Item | Result |
|---|---|---|
| 1 | Schematic vs minimal design | ✅ after the crystal swap. Small deviations: one fewer 100 nF than 3V3 pins (the guide shares one between pins 48/49 too); no footprint for the guide's optional DNF 10 kΩ QSPI_SS pull-up, which it says the W25Q128JVS does not need. |
| 2 | Flash on QSPI pins; BOOTSEL 1 kΩ | ✅ R1 1 kΩ, near the flash's CS pin as the guide asks. |
| 3 | Crystal load from the part's CL | ❌ → ✅ Was CL 20 pF / ESR 80 Ω on 22 pF caps; now the guide's ABM8-272-T3 with 15 pF (§3). |
| 4 | Decoupling, centre-pad vias, ground under the MCU | ⚠️ Every supply pin decoupled; centre pad 9 vias, solid zone connection. The F.Cu ground fill now covers 65% of the board in one 1,149 mm^2 main piece, but is still not unbroken directly under U3's body. |
| 5 | USB short, coupled, matched, over ground | ✅ (mostly) D+ 15.9 mm / D- 16.1 mm, entirely on B.Cu, no vias (was 18 / 26 mm with 6 vias); 82% of its length over GND fill on F.Cu (was 9%, then 28%). Full-speed USB tolerates the rest; the guide's 90 Ω target needs a 1 mm board anyway. R5/R6 sit ~7 mm from the chip. |
| 6 | LDO rated above Phase 1 peak | ⏳ Open -- the Phase 1 current measurement is still pending. |
| 7 | BOOTSEL/RESET reachable in the case | ⏳ Open -- no case yet; which face mounts up is undecided. |
| 8 | Power OR-ing, either half plugged in | ✅ Each half's VBUS enters the shared +5V through its own D1, so two hosts never meet. F2 (500 mA) caps what one half can send the other. |

Measured ground share under the fast nets (GND fill on the opposite layer,
along each track), across the three routings:

| | 35 x 50, hand reroute | 35 x 57, FFCs above USB-C | **35 x 57, FFCs below USB-C (as built)** |
|---|---|---|---|
| USB | 28% | 35% | **82%** |
| QSPI | 1% | 0% | **65%** |
| Crystal | 50% | 81% | 54% (46% before a hand pass) |
| F.Cu fill | 58%, main piece 987 mm^2 | 56%, 1,091 mm^2 | **65%, 1,146 mm^2** |
| B.Cu fill | 51%, 9 pieces | 53%, 7 pieces | **54%, 6 pieces, main piece 1,018 mm^2** |
| Routed | yes | GPIO3 unroutable | **yes** |

What moved the numbers was where the main FFCs sit, not the board length on
its own: with J6/J7 on the lower half of the side edges the matrix bundle
no longer has to cross under the USB and QSPI routing on F.Cu. A hand pass
in KiCad afterwards (2026-10-09; GPIO2/4/5/7/9/12/15, +3V3, XTAL_IN) lifted
the crystal from 46% to 54% and joined the B.Cu fill into fewer pieces;
the crystal is still the weakest of the three -- short, and on the
oscillator's own pins, so a lower priority than QSPI was. The routing
workflow and its traps are recorded in docs/TOOLS.md and
hardware/route_tools.py.

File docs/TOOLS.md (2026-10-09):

# Tools

## KiCad

- KiCad **10.0.6** (installed) — schematic + PCB, per PLAN.md §3/§5

- AI tooling

  **Where each one installs, and when.** Two of these go into Claude and two go into KiCad. None are needed before Phase 3 — Phase 1 is a breadboard and QMK, which needs no tooling beyond a shell.

  | Tool | Installs into | Install at |
  |---|---|---|
  | kicad-happy | **Claude Code** (plugin) | Phase 3, before the first review |
  | kicad-mcp | **Claude Code** (MCP server) | Phase 3, and only once a board exists — it bridges a *running* KiCad session, so it is inert before then |
  | marbastlib | KiCad (PCM) | Phase 3 |
  | kicad-kbplacer | KiCad (plugin) | Phase 3 |

  Hold the MCP server until it is actually useful: an MCP server's tool schemas sit in context permanently, whereas a plugin costs nothing until invoked.

  - **kicad-happy** skill — file-based review/audit: DRC/ERC cross-checks, schematic-vs-PCB net tracing, BOM extraction, EMC pre-compliance. No running KiCad session needed. Verified: it is packaged as a Claude Code plugin — `/plugin marketplace add aklofas/kicad-happy` then `/plugin install kicad-happy@kicad-happy`, both from an interactive terminal session. (Also ships as standalone zero-dependency Python 3.10+ scripts and a GitHub Action, if a non-agent path is ever wanted.) Use it as the automated pass for the §4 "MCU-section review checklist" (schematic diff against the minimal design example, decoupling coverage, ground-pour continuity) before ordering the controller module in Phase 4.5. https://github.com/aklofas/kicad-happy
  - **kicad-mcp** (Seeed-Studio) — live MCP bridge into an open KiCad 9+ session: inspect schematics/PCBs, trace nets, drive edits interactively. Complements kicad-happy rather than replacing it — this is for hands-on layout sessions, kicad-happy is the checklist gate. https://github.com/Seeed-Studio/kicad-mcp-server

- Placement/routing
  - **kicad-kbplacer** — KLE → footprint placement + routing. Actively maintained, CLI mode, and `schematic_builder` now handles stabilizers and rotary encoders directly (relevant: one EC11 per half). Confirmed pick in PLAN.md §0. **Gap:** it only understands KLE key units, so it won't place the solved knob-pod geometry in `hardware/layout/pods.json` — plan a small custom placement script layered on top for those. https://github.com/adamws/kicad-kbplacer
  - **kle2netlist** — netlist generation from the KLE source, paired with kbplacer per PLAN.md §0.
  - **Freerouting** 2.4.1 — autorouter, installed as the KiCad PCM plugin `app.freerouting.kicad-plugin`, which brings the jar at `~/.local/share/kicad/10.0/3rdparty/plugins/app_freerouting_kicad-plugin/jar/`. Routed the controller (2026-10-07). Needs Java 25+; see the routing traps below.

- Component libraries
  - **marbastlib** (ebastler) — the keyboard parts library. Replaces kicad-keyboard-parts.pretty, which was the same author's older, narrower library. 13 `.pretty` footprint libs and 6 `.kicad_sym` symbol libs. https://github.com/ebastler/marbastlib
    - Install via **KiCad PCM**, not a manual clone — it ships version-matched packages and this machine runs KiCad 10.0.6. Add this repository under PCM → Manage, then install marbastlib from it: `https://raw.githubusercontent.com/ebastler/ebastler-KiCad-repository/main/repository.json`. There is no `kicad-cli pcm` subcommand, so this step is GUI-only.
    - **Verified present:** MX/Choc hotswap sockets (`SW_MX_HS_CPG151101S11_*`, Kailh CPG151101S11), stabilizers (`STAB_MX_*`), USB-C receptacles (GCT USB4505/USB4510, HRO TYPE-C-31-M-*), WS2812_2020 both standalone and switch-integrated (`LED_MX_WS2812_2020`, which places the LED in the switch cutout for you).
    - **Gap — rotary encoder.** Has only the switch-integrated `ROT_Alps_EC11E-Switch.kicad_mod` + 3D model, and **no schematic symbol** for it in any of the 6 symbol libs. The no-switch `EC11N` variant — the one PLAN.md §2 actually wants — is a 3D STEP model only, no footprint. See open questions.
    - **Gap — per-key RGB.** Same shape of problem: `LED_SK6812MINI-E.step` exists as a 3D model, but there is **no SK6812MINI-E footprint** — only WS2812_2020, which is a 2.0 × 2.0 mm part against SK6812MINI-E's 3.5 × 3.5 mm reverse-mount. PLAN.md §3 currently specs SK6812MINI-E. Either source that footprint elsewhere, or switch the plan to WS2812_2020 and get the switch-integrated footprint for free. Decide before the Phase 3 main-PCB layout, since this is the reservation that cannot be retrofitted.
    - **Gap — no GC9A01 coverage** (see below).
  - Official Raspberry Pi Pico KiCad files, or **ncarandini/KiCad-RP-Pico** — RP2040 symbol/footprint reference, per PLAN.md §4.
  - **easyeda2kicad.py** / **JLC2KiCad_lib** — pull footprint + 3D model straight from the LCSC part number for the JLCPCB-PCBA'd parts (W25Q128JVSIQ, AP2112K-3.3, USBLC6-2SC6, the RP2040 itself) so the design-side footprint matches the assembly-side part exactly, rather than trusting a hand-picked generic footprint.
  - Install marbastlib and kicad-kbplacer through **KiCad PCM** rather than manual vendoring, where possible (marbastlib repository URL above).

### Environment gotchas found in practice (2026-09-13, 2026-09-14)

- **`pcbnew` imports only under `/usr/bin/python3`.** `python3` is mise-shimmed and cannot see it. The project venv is created with `--system-site-packages` from the system interpreter for this reason. (2026-10-07: mise is not installed on the current machine and `python3` is the system interpreter, so the trap is dormant -- keep using `/usr/bin/python3` explicitly anyway.)
- **`requirements.txt` at the repo root pins the venv's contents** (kbplacer, kicad-skip, easyeda2kicad, sexpdata). `.venv-kicad/` is gitignored, so that file is the only record of what belongs in it. Recreate with `/usr/bin/python3 -m venv --system-site-packages .venv-kicad && .venv-kicad/bin/pip install -r requirements.txt` — the `--system-site-packages` flag is not optional, per the point above.
- **KiCad 10.0.6's own `pcbnew.py` is broken on Python 3.14.** Container `__iter__` methods call `it.next()`, a Python-2 idiom, while this SWIG build exposes only `__next__`. Any `GetTracks()` / `GetDrawings()` / `GetFootprints()` iteration raises `AttributeError`. `hardware/kicad_compat.py` patches it; import that before `pcbnew` in every script.
- **kbplacer needs the `[schematic]` extra** (`kicad-skip`) or `--create-sch-file` fails with "Requires optional schematic dependencies".
- **kbplacer takes absolute `.pretty` paths**, not library nicknames, so no fp-lib-table registration is needed *to run it* — but the board it writes references the library by bare nickname (`marbastlib-mx`), and that nickname has to resolve afterwards or every switch footprint reports `lib_footprint_issues` in DRC and `footprint_link_issues` in ERC. Corrected 2026-09-14: PCM **did** register marbastlib globally, under the prefixed nicknames `PCM_marbastlib-mx`, `PCM_marbastlib-xp-mx` and so on in `~/.config/kicad/10.0/fp-lib-table` — so this was never a missing library, only a nickname mismatch. Fixed by giving each main project its own `fp-lib-table` mapping the bare `marbastlib-mx` to `${KICAD10_3RD_PARTY}/footprints/com_github_ebastler_marbastlib/marbastlib-mx.pretty`, matching the global table's own path convention so the entry stays portable. That cleared 140 warnings across the two main boards.
- **Width templates must match the library's own spelling.** marbastlib names widths `1u`, `1.25u`; a plain `{}` renders 1.0 as `1.0u` and fails to load. Use `{:g}`.
- **`--additional-elements` REPLACES the default** rather than adding to it. Omitting `ST{}` silently leaves stabilizers stranded at the origin.
- **`--create-led-pcb-elements` does not position anything.** It creates and nets the LEDs and capacitors but leaves every one stacked at (0,0) unless they are also named in `--additional-elements`.
- **marbastlib hotswap switch footprints must be placed on the BACK.** Their socket pads are on `F.Cu` and the pin holes are drawn mirrored, i.e. the footprint is drawn as seen from underneath. Placed on the front (kbplacer's default) the socket ends up on the same side as the switch. Pass `-s "SW{} 0 BACK"`. Verify by the pin1->pin2 vector, which must be `(-6.35, 2.54)` to match KiCad's stock `SW_Cherry_MX_1.00u_PCB` — absolute pad coordinates are not comparable between libraries because the origins differ (marbastlib uses the switch centre, KiCad stock uses pin 1).
- **Switch orientation must be checked against the centre post, not the pin vector.** A 180 deg rotation with swapped pin numbering leaves the pin1->pin2 vector unchanged, so that test passes on a board that is rotated wrong. KiCad's stock `SW_Cherry_MX_1.00u_PCB` puts pins NORTH of the switch centre: `(+2.54,-5.08)` and `(-3.81,-2.54)`. Compare absolute positions relative to the centre-post NPTH.
- **`--additional-elements` / `-d` offsets are in the switch's ROTATED frame.** With `SW{} 180 BACK`, an offset of `+5.08` lands at `-5.08` on the board. Invert the signs.
- **kbplacer leaves duplicate-numbered pads unnetted.** marbastlib's hotswap footprint has pad "1" three times (one PTH, two SMD); only one gets a net, and DRC then reports the switch shorting itself. `generate_main_pcbs.py` post-processes this.
- **Saving a board rewrites its project file.** Any `.kicad_pro` rule change must be applied *after* the last `board.Save()`, or it is silently reverted.
- **`GetBoardEdgesBoundingBox()` counts footprint-internal `Edge.Cuts`.** The reverse-mount SK6812MINI-E footprint cuts its own hole, so 640 of them inflate the reported board size. Measure the outline from board-level drawings only.
- **A KiCad 6 schematic keeps per-instance value and footprint in the sheet-level `symbol_instances` block**, not in each symbol's own property fields, which sit empty. Anything reading symbol properties — Konnect's `bom_health` audit included — then reports those parts as having no value and no footprint. `dyad-controller.kicad_sch` was `version 20211123`, inherited wholesale from `upstream/RP2040-Guide.kicad_sch` (same sheet UUID), and R2 looked valueless for exactly this reason while `symbol_instances` carried `1k` all along. The same gap blocks writes: Konnect refuses `add_schematic_component` with `stale_target`, because there are no per-symbol `(instances)` blocks for it to preserve. **`kicad-cli sch upgrade` does not fix it** — it converts the format but *drops* the instance data instead of migrating it. The only thing that works is opening the schematic in KiCad once and saving; that also writes the project name and real sheet UUID into `.kicad_pro`, which were empty and all-zeros. Upgrade before trusting any BOM or library audit on a vendored schematic. Checked across the repo 2026-09-14: only the controller was affected. Both main PCBs are `version 20250114` with per-symbol instances intact (65/65, 74/74, plus the LED-chain sheets), so they need no upgrade — though their schematics report generator `9.0` against boards at `10.0`, which is why `get_project_info` returns a null compatibility `kicad_version` for them.
- **Konnect's live-IPC tools split on whether they call `GetOpenDocuments`, which KiCad 10 does not implement.** `query_traces` uses it as a board-identity pre-check, so it fails *permanently* on this build with `KiCad IPC error: no handler available for request of type kiapi.common.commands.GetOpenDocuments (AS_UNHANDLED)` — even with the board open and IPC perfectly healthy. The tell is `AS_UNHANDLED` rather than a connection error: at the same moment `check_kicad_ui` reports `ipc_responsive: true` and `get_nets_list` reads all 91 nets off the live board. Tools that take a UUID or raw coordinates instead (`modify_trace`, `route_trace`) work fine, which is how the COL6 clearance fix was applied. Do not read the failure as "the board is not open", and do not fall back to editing the `.kicad_pcb` behind a running KiCad — Konnect's own PreToolUse guard forbids it. Note also that IPC edits live in KiCad's memory only: the file on disk is unchanged until you save in the GUI, so verify with `kicad-cli` *after* Ctrl+S, not before. (2026-10-07: on Konnect 0.13.0, `open_project` listed the open board without error, so this may be fixed; `query_traces` was not retested.)
- **kbplacer bundles multi-sheet projects `flat` on KiCad 10**, tying the sheets together only through the `sheets` list in `.kicad_pro` rather than with hierarchical sheet symbols — so a root `.kicad_sch` with zero `(sheet` blocks is correct here, not broken. The catch is that the tooling around it disagrees: `kicad-cli pcb drc --schematic-parity` reads a single `.kicad_sch` and reports every *other* sheet's footprints as `Extra footprint` (64 phantom findings on main-left, 74 on main-right), and Konnect's `--schematic-scope hierarchy` audits follow hierarchical sheet symbols, of which a flat project has none, so `check_bom_health` counted 65 of ~195 components. Verify the real structure by matching each `.kicad_sch`'s own `(uuid …)` against the `.kicad_pro` `sheets` entries before believing an orphan report. `generate_main_pcbs.py` now passes `--bundle-strategy hierarchical` to opt out, so those checks mean something; the cost is diverging from kbplacer's KiCad 10 default.
- **marbastlib's hotswap switch footprints stop at 1.75u**, so kbplacer falls back to 1.0u for anything wider and logs `Requested width 2.25u not available for SW_MX_HS_CPG151101S11, using 1.0u fallback`. That warning is harmless. Diffing `SW_MX_HS_CPG151101S11_1u` against `_1.75u` leaves exactly one substantive difference: the keycap rectangle on **`Dwgs.User`**, a documentation layer that is neither fabricated nor DRC-checked. Pads, drills, silkscreen, `F.Fab` and both courtyards are identical — the courtyard is a fixed +/-7 mm modelling the switch body, not the cap — so the fallback costs a drawing-layer outline and nothing electrical or mechanical. The part that does matter is correct: stabilisers go up to 10u, and the 2.25u key on the left half carries `STAB_MX_2.25u` centred on its switch. Measured 2026-09-14: D21 clears ST21's nearest hole by 1.53 mm.
- **kbplacer never links the board to the schematic**, so every footprint lands with an empty `(path)`. KiCad matches symbols to footprints by that path, so with it blank *Update PCB from Schematic* treats every symbol as new and re-adds the whole board — which makes any schematic-side edit impossible to push through. `generate_main_pcbs.py` now writes the link itself, in KiCad's format `<sheet path without the root uuid>/<symbol uuid>`; a root-level symbol on a flat sheet carries `/<symbol uuid>` alone. Beware when parsing these sheets: **kbplacer writes them unindented and KiCad rewrites them tab-indented on first save**, so a whitespace-keyed parser silently works on one and finds nothing in the other. Match brackets instead. Recovery note: `<project>/.history/` is a real git repo KiCad maintains, gitignored but fully usable — `git log` and `git show` in it recovered a hand-laid LED chain that a regeneration had overwritten, from its `SCH Save` commit.
- **A root `.kicad_sch` whose own uuid disagrees with the project makes `kicad-cli --schematic-parity` useless.** `kicad-cli` resolves each footprint's `(path)` through the root sheet uuid; the KiCad GUI resolves through the project structure instead. When the two disagree the CLI cannot match a single footprint to its symbol and reports every pad on an unlabelled net as `net_conflict` / "No corresponding pin found in schematic" — 199 of them on main-right, covering every diode, every switch and LED1-LED26 — while the GUI sees nothing wrong and rewrites the board byte-identically. Three places must agree: the root `.kicad_sch`'s own `(uuid ...)`, the first component of every child sheet's symbol instance paths, and the Root entry in the `.kicad_pro` `sheets` list. Introduced here by restoring a root sheet from `.history` while the project had moved to a new root uuid. **Diagnostic:** compare against the other half. main-left has identical footprints, symbols and libraries and showed zero such findings, which ruled out the footprints long before the cause was found — reach for that control early when one board looks structurally wrong and the other does not.

### Controller layout and routing traps (2026-10-07)

Found while syncing, placing and routing the controller board. Grouped by tool.

**Setup**

- **A fresh machine is missing more than KiCad.** On top of the KiCad package itself: `kicad-library` and `kicad-library-3d` (stock footprints, symbols, 3D models -- the boards use `Capacitor_SMD`, `Diode_SMD`, `Connector_USB` and so on, and `generate_main_pcbs.py` reads `/usr/share/kicad/footprints` directly), marbastlib through PCM, the `.venv-kicad` venv, the `qmk` CLI plus `qmk setup`, a git identity, and Java for Freerouting. Install `qmk` with `pipx`, **not** into `.venv-kicad` -- it then only works with that venv activated and its dependencies fall outside `requirements.txt`.
- **Freerouting 2.4.1 needs Java 25 or newer.** On Java 21 it dies with `UnsupportedClassVersionError ... class file version 69.0`. On Arch, `jre-openjdk-headless` (the unversioned package) is current; make it the default with `sudo archlinux-java set java-<n>-openjdk`.
- **Konnect needs the KiCad API socket configured, not just enabled.** Enable *Preferences → Plugins → Enable KiCad API*, then put `ipc:///tmp/kicad/api.sock` into `ipc_socket_path` in the Konnect plugin's `settings.json`. A running Konnect server reads that file only at startup; its own `reload_server` tool picks it up without restarting the AI client.

**KiCad: closed or open**

- **Check for a running KiCad immediately before writing any board or project file, and stop if one is there.** Look for `~<name>.kicad_pcb.lck` beside the board. KiCad holds its own copy in memory and writes it back on save, silently undoing file-level edits -- and the project file is rewritten on every board save (see above), which also reverts netclass edits made to `.kicad_pro`. Read the check's result *before* the write, not in the same command.
- **File-based work therefore needs KiCad closed; live work goes through the API.** `kicad-python` (`pip install kicad-python`, imported as `kipy`) talks to the same socket as Konnect and does bulk edits in one undo step (`begin_commit` / `push_commit`), which Konnect's one-item tools cannot -- e.g. deleting 465 tracks and vias at once. `board.revert()` reloads the board from disk, and `board.save()` saves.
- **`kipy`: never update the same footprint twice inside one commit.** It produced a *second* copy of each such footprint with the *same* KIID -- one moved, one left behind -- and saving wrote both to the file. Same-ID duplicates cannot be removed by ID; the only recovery was restoring the board from git and reloading. Set position and rotation in a single `update_items` call per footprint.
- **A footprint's position is its origin, which is not always its centre.** A pin header's origin is pin 1, so "centring" a 1x05 at a point put pin 5 past the board edge. Place from pad positions, not from the origin.

**Konnect**

- **`update_pcb_from_schematic` treats bare pads as routed copper.** It refused three pad net changes (`routed_pad_net_change`) on a board with no tracks at all, because it reads routing from the *saved* file rather than the live board. Saving did not help; pre-assigning the three pad nets live, to exactly what the sync would set, did.
- **`update_pcb_from_schematic` does not swap footprints that changed in the schematic.** A footprint whose library ID changed is either a `footprint_id_changed` conflict or, as with SW1 (pin header → tactile switch), silently left as the old part. It also never deletes board-only footprints. Use KiCad's own *Update PCB from Schematic* with "replace footprints" for those.
- **`place_component` drops the library footprint's attributes.** Mounting holes placed with it lost `exclude_from_bom` and `exclude_from_pos_files` and would have gone onto the JLCPCB BOM as parts. Re-check attributes after placing.
- **`export_specctra_dsn` accepts only front-side parts and a straight-line outline.** The controller has every part on B.Cu and rounded corners, so it is out. Use KiCad's own `pcbnew.ExportSpecctraDSN(board, path)` and `pcbnew.ImportSpecctraSES(board, path)` on the file, with KiCad closed.

**KiCad itself**

- **The stock USB-C symbol and footprint disagree on the shield pin.** `Connector:USB_C_Receptacle_USB2.0` names it `S1`; KiCad 10's `USB_C_Receptacle_HRO_TYPE-C-31-M-12` names the four shell pads `SH`. A KiCad 6 copy of the footprint still says `S1`, which hides the mismatch until a fresh one is placed. Fixed with `dyad:USB_C_Receptacle_HRO_TYPE-C-31-M-12`, shell pads renumbered `S1`.
- **Change Footprint nets only one pad of each duplicate-numbered pair.** The TS-1187A button has pads 1,1,2,2; after the swap two of the four had no net. It also carried the old part's value and BOM exclusion over. Same family as kbplacer's duplicate-pad trap above.
- **`min_copper_edge_clearance` defaulted to 0** in the controller project, so DRC never flagged a pad hanging off the board. It is now 0.3 mm. Check this setting on any new or vendored project.
- **Thermal-relief spokes do not fit on fine-pitch GND pads.** DRC reports `starved_thermal` on the RP2040 exposed pad, 0.5 mm-pitch FFC GND pins, SOIC GND and USB-C shell pads. These are already connected by tracks; give those pads a solid zone connection (`pad.SetLocalZoneConnection(ZONE_CONNECTION_FULL)`) -- for the QFN exposed pad that is the right choice anyway.
- **`pcbnew` from Python is fragile for bulk edits.** Removing all tracks from a loaded board in a loop crashed the interpreter before it saved; on a scratch copy it was simpler to strip the top-level `(segment` / `(via` / `(zone` blocks by bracket matching. A freshly created `ZONE` also reported the wrong layer through `GetLayerName()` -- trust the saved file. And `PCB_TRACK` objects are unhashable: key sets on `m_Uuid.AsString()`.

**Freerouting**

- **The optimizer can take longer than the routing, and the output is written only at the very end.** On the controller, routing took ~5 minutes and one optimizer pass 14; a 25-minute timeout then killed the run and saved nothing. Pass `--router.optimizer.enabled=false` and tidy by hand in KiCad. Headless: `java -jar freerouting-2.4.1.jar -de in.dsn -do out.ses -mp 100 --gui.enabled=false`.
- **Per-layer costs go in an `(autoroute_settings ...)` block inside the DSN's `(structure ...)`, after both `(layer ...)` definitions.** Placed before them, Freerouting reports "layer not found" and crashes with a `NullPointerException`. Syntax: `(layer_rule F.Cu (active on) (preferred_direction vertical) (preferred_direction_trace_costs 4.0) (against_preferred_direction_trace_costs 6.0))`, plus `(via_costs n)`. The command line has no per-layer option.
- **Freerouting ignores KiCad's hole-to-hole rule and its custom `.kicad_dru` rules, and necks tracks down where it is tight.** Expect 6-24 vias 0.44-0.496 mm apart against a 0.5 mm rule, tracks at 0.15 mm, and clearance misses at fine-pitch connectors after every run. Fix vias with a search for the smallest move that clears every hole and all other-net copper on both layers (moving straight away from the neighbour pushed five vias into tracks).
- **Prevent the hole-to-hole misses instead (2026-10-09): add a via-to-via clearance to the DSN.** With 0.6 mm vias on 0.3 mm drills, Freerouting's general 0.15 mm clearance puts holes ~0.45 mm apart. Adding `(clearance 250 (type via_via))` next to the `smd_smd` clearance in the DSN's structure `(rule ...)` keeps holes >= 0.55 mm apart; every run with it came back with zero via-to-via misses. Connector peg holes (NPTH pads) are not covered -- expect the odd one there. `hardware/route_tools.py dsn` exports with the rule already in.
- **Don't try to fix a stuck via by removing it if it is a junction.** A matrix line's via can join three branches (U3, J6, J7); removing it and reconnecting one branch left the net split. Rip only the segments *between* a pad and its first via.
- **The scratchpad is not durable.** A new session day wiped every helper script mid-reroute, and a pipeline that silently skipped the missing USB step then deleted Freerouting's USB tracks. The helpers now live in `hardware/route_tools.py`, and its `usb` and `restoreusb` steps stop with an error rather than carry on.
- **Do not rerun Freerouting to finish one unrouted net.** On an already-routed DSN its fanout stage tore up existing routing: it started from 40 unrouted nets and ended at 14. Rerun the whole board with a different strategy instead -- `-is random` routed 100% where the default order left one net.
- **Layer costs move copper between layers more than they improve the board.** Making F.Cu 4x-15x as expensive mostly swapped which layer kept a continuous GND fill. Measure what matters -- the share of each fast net's length with GND fill on the opposite layer -- rather than whole-board coverage. On the controller, moving the flash next to the RP2040 halved the QSPI wiring, which no cost setting achieved.

## Case CAD

Parametric, driven by the same key-position data as the PCB (`hardware/layout/`), per PLAN.md §4/§6 Phase 4.

- **build123d** (pick) — Python, OCCT kernel (same as FreeCAD). Fillets/lofts/booleans handle the bearing race, ring-gear teeth (mechanism Option A, PLAN.md §2), and pod pockets much better than pure CSG.
- **FreeCAD** — same OCCT kernel, full GUI + sketcher + assembly workbench. Better for hand-iterating dimensions and consuming the STEP files KiCad exports (PLAN.md §3). Heavier than scripting alone; worth having installed regardless for STEP inspection.
- **OpenSCAD** — simplest scripting model, but CSG-only — the round bearing seat and ring-gear geometry get awkward without OCCT-style fillets. Probably not the pick here.

## Firmware (QMK)

- **QMK CLI** + **external userspace** — keymap lives outside the `qmk_firmware` tree, per PLAN.md §6 Phase 6.
- **Vial** (pick over VIA for this board) — the layout JSON compiles into firmware itself; no need to merge a keyboard definition into VIA's upstream repo or side-load unsigned JSON each session. Better fit while this board isn't upstreamed.
- **VIA** — reconsider only if the QMK keyboard definition actually gets upstreamed (PLAN.md §6 Phase 7 holds this as optional).
- **keymap-drawer** (+ `vial-to-keymap-drawer`) — renders the keymap for the build guide, Phase 7.

## Open questions

- GC9A01 breakout: no footprint in marbastlib (checked the library contents directly, not just the README). It's a generic round-LCD module with no standard KiCad library entry anywhere — plan to hand-draw a pin-header footprint once you've picked the exact module you're buying (pitch/pin-count vary by vendor).
- EC11 no-switch variant (EC11N — what PLAN.md §2 actually calls for, since the encoder's own click is deliberately unused): no footprint in either library, only an orphaned 3D model. Simplest path is probably to reuse the EC11E-Switch footprint body and just leave its switch pads unpopulated, rather than drawing a separate footprint — same mechanical part either way. Confirm that assumption once a specific supplier/datasheet is picked, since "E"/"N" suffixes aren't a reliably-documented standard across vendors.
- Pick one of the kicad-mcp implementations after a short hands-on trial (Seeed-Studio vs. mixelpixx vs. lamaalrajih) rather than committing from descriptions alone.
- Design the custom pod-placement script (kbplacer gap, above) before Phase 3 layout starts.

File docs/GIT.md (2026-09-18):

# Working on features with git

Most of this repository is KiCad files, and **KiCad files cannot be merged.**
That single fact sets the whole workflow. Everything below follows from it.

---

## 1. The rule: one feature, one branch, off `main`

```bash
git switch main
git pull
git switch -c feature/ffc-connector
```

**Naming: `feature/<description>`**, description in lower-case kebab-case —
what the feature *is*, not which files it touches.

| Good | Poor | |
|---|---|---|
| `feature/ffc-connector` | `feature/J1` | a reference designator means nothing in six months |
| `feature/led-serpentine` | `feature/fix-leds` | "fix" says nothing about what changed |
| `feature/knob-pcb` | `feature/kicad-changes` | every branch here changes KiCad |
| `feature/split-usb-power` | `feature/new-stuff` | |

Keep it to two or three words. The branch is a label on a conversation, not a
summary of the diff.

The same discipline applies whatever prefix a branch carries — nothing below
is specific to `feature/`.

---

## 2. Why branches matter more here than in a software repo

A `.kicad_pcb` or `.kicad_sch` is a serialized object graph: UUIDs,
cross-references, and order-sensitive structure that happens to be stored as
text. Git will cheerfully three-way-merge it. The result frequently still
*parses*, which is the dangerous part — you get duplicate UUIDs, orphaned
references and silently detached nets rather than an error.

**So never let two branches touch the same board.** Not "try to avoid" —
never. If two pieces of work both need `pcb-main-right`, they are one branch
or they are sequential.

Two safe consequences of the same rule:

- **Rebase onto `main`, never merge `main` in.** Rebasing replays your
  commits one at a time, so a conflict is between one of your commits and
  `main` — a small, comprehensible thing.
- **If a KiCad file ever conflicts, do not resolve it by hand.** Take one
  side whole (`git checkout --ours` / `--theirs`) and redo the other side's
  work in KiCad. Hand-editing conflict markers in an s-expression graph is
  how you lose an afternoon of routing and not notice for a week.

`.gitattributes` enforces this rather than leaving it to discipline: the
KiCad file types are marked `-merge`, so git refuses to invent a result. On
conflict it leaves your version in the worktree and marks the path
conflicted, without writing markers into the file. You still have to resolve
it — but the failure is now loud instead of silent.

Library tables (`fp-lib-table`, `sym-lib-table`) are deliberately *not*
marked: they are line-oriented and merge sanely.

---

## 3. Close KiCad before switching branches

KiCad holds the whole board in memory. Switch branches underneath it and the
next save writes the *old* board over the new branch's file, with no warning
and no conflict.

```bash
# close KiCad first, then:
git switch feature/whatever
```

Leftover `~*.kicad_*.lck` files mean an editor is still open or died badly.
They are gitignored, but a stale one makes KiCad claim the project is already
open — delete it once you are sure nothing is running.

`.history/` inside each project is KiCad's own version-history repo. It is
gitignored but real, and `git log` / `git show` work inside it. It is the
reason a hand-laid LED chain was recoverable once after being regenerated
away. It is a safety net, not a substitute for committing.

---

## 4. Commit as you go

Small, logical commits, each one a thing you could explain on its own. The
existing history is the reference: a descriptive sentence as the subject, then
a body that says **why**, not what the diff already shows.

Split by intent rather than by file. A typical feature here lands as
something like:

```
Add a project footprint library carrying the main FFC connector
Add the 20-pin FFC connector to the right half's schematic
Route the FFC connector on the right main PCB
Confirm the FFC part number and record the J1 pinout
```

Order them so each builds on the last — a library before the schematic that
references it, a schematic before the board updated from it.

End with the co-author trailer when Claude did the work:

```
Co-Authored-By: Claude Opus 5 <noreply@anthropic.com>
```

---

## 5. Hardware commits carry their numbers

A hardware change is not self-evident from its diff — 2,800 changed lines in a
`.kicad_sch` can be one connector. **Put the measurements in the message**, as
a before → after:

| Check | Command |
|---|---|
| ERC | `kicad-cli sch erc <root>.kicad_sch` |
| DRC, unconnected and parity | `kicad-cli pcb drc --schematic-parity <board>.kicad_pcb` |

Report the delta against `MANUAL_TASKS.md` §Current state, and **say plainly
which findings are expected.** A commit that moves parity from 0 to 1 is fine
if the message explains that it is a field-text mismatch clearing on the next
Update PCB from Schematic; it is alarming if the message is silent.

Never commit a board with unconnected items without saying so. That number is
the one everything else is checked against.

---

## 6. Finishing a feature

```bash
git switch main
git pull
git switch feature/ffc-connector
git rebase main          # resolve per §2 if KiCad files conflict
git switch main
git merge --ff-only feature/ffc-connector
git push
git branch -d feature/ffc-connector
```

`--ff-only` is deliberate: after a rebase it should fast-forward, and if it
refuses, something moved on `main` that you have not rebased onto. Find out
what before forcing it.

Update `MANUAL_TASKS.md` before merging, not after. It is the file the next
session reads first, and a stale baseline there is worse than no baseline —
it makes a real anomaly look like the expected state.

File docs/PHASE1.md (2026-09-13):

# Phase 1 — electrical bring-up on dev boards

No custom PCB. The goal is to prove every peripheral works *before* any of it
is committed to copper, and to produce the handful of measured numbers that
later phases depend on.

This phase de-risks most of the project for about $40 of parts.

---

## Gate status

| | |
|---|---|
| **G0 — key layout** | Passed. Paper mockup checked by hand. |
| **G1 — mechanism** | Not required. Phase 1 is electrical; Phase 2 runs in parallel. |
| **G2 — contract** | Not required, but Phase 1 *closes one of its TODOs* (see §4). |

**One caveat.** The mockup you validated had the left pod at (8.70, 4.20) with
a 45 mm ring. It is now (8.85, 4.20) with a 50 mm ring. Key positions did not
change, so G0 stands — but reprint the left sheet and re-check the pod when
convenient. It does not block anything here.

---

## 1. Kit

| Item | Qty | Notes |
|---|---|---|
| **Raspberry Pi Pico** | 2 | **Not Pico 2.** That is RP2350, which QMK does not support. Original RP2040 Pico only. 26 GPIO, and it is the reference design we are cloning anyway. |
| GC9A01 1.28" round display | 1 | **Measure its outside diameter when it arrives** — see §4. |
| Cirque TM040040 | 1 | Owned. Check which bus it is strapped for — §5. |
| Cirque FPC breakout / pigtail | 1 | The 12-pin 0.5 mm flex cannot be soldered directly. |
| EC11 encoder, detented | 2 | |
| TRRS jacks + cable | 2 + 1 | Use a real cable, not jumpers. The cable *is* part of what's being tested. |
| 0.5 mm FFC, 14-pin + 2 breakouts | 1 | For §3 step 5. Qualifying SPI on breadboard jumpers proves nothing about a ribbon. |
| MX switches + 1N4148 diodes | 4 + 4 | 2×2 matrix. |
| Breadboard, jumpers | — | |
| **USB inline power meter** | 1 | ~$10. This phase's single most important output is a current number; a meter in series with a multimeter is far more painful. |
| WS2812 strip, 32 + 37 LEDs | 1 | Current proxy for per-key RGB — see §4a. |
| 5 V bench supply or powered hub | 1 | For the LED strip. Do not pull 2 A through the dev board. |

### Still to order, highest value first

1. **14-pin 0.5 mm FFC + 2 breakouts.** Gates step 5, the one remaining test that can change the design. Cheap and slow to ship — order first.
2. ~~GC9A01~~ **ordered** — Waveshare SKU 19192. 37.5 mm round PCB, 40.4 mm with the header tab, 32.4 mm active glass, BL pin present, 4-wire SPI. Verify with calipers on arrival, but the datasheet was enough to close `module_od`.
3. **Second WinWin Pico_Mini RP2040**, same model. Plus 2× TRRS jacks and a cable.
4. WS2812 strips, 5 V supply, USB power meter.

---

## 1a. Bench rig on hand

**Board: WinWin Pico_Mini RP2040** (`hardware/devboard/rp2040-mini.avif`). Exposes GP0–GP23 and GP25–GP29 — 29 GPIO, comfortably more than the 27 the final design needs, so the pin budget can be confirmed for real on this board.

Note the flash-size variants silkscreened on it (2M/4M/8M/16M). **Check which you have** — Quantum Painter assets live in flash, and the final design specs 16 MB.

**Cirque, already wired — and it is on SPI, not I²C:**

| Pad | RP2040 function | Cirque |
|---|---|---|
| GP2 | SPI0 SCK | SCK |
| GP3 | SPI0 TX | SDI / MOSI |
| GP4 | SPI0 RX | SDO / MISO |
| GP5 | SPI0 CSn | CS |
| GND, 3V3 | — | power |

Four signals plus power is an SPI Cirque. I²C would be two signals; the only I²C reading of GP2–GP5 puts them on *two different buses*, which nobody wires on purpose. **DR is not connected**, so QMK polls rather than using the interrupt — acceptable on the bench.

Build step 6 to match the wiring:

```make
# rules.mk
POINTING_DEVICE_ENABLE = yes
POINTING_DEVICE_DRIVER = cirque_pinnacle_spi
```
```c
// config.h
#define SPI_DRIVER  SPID0
#define SPI_SCK_PIN  GP2
#define SPI_MOSI_PIN GP3
#define SPI_MISO_PIN GP4
#define CIRQUE_PINNACLE_SPI_CS_PIN GP5
#define CIRQUE_PINNACLE_SPI_DIVISOR 8
#define CIRQUE_PINNACLE_DIAMETER_MM 40   // NOT the default 35
```

**This has a design consequence — see §5a.**

---

## 2. Toolchain — done

Working as of 2026-09-13. Recorded here because three things were not obvious.

```bash
qmk config user.qmk_home=~/qmk_firmware
qmk config user.overlay_dir=/home/b/workspace/dyad-keyboard/firmware
qmk compile -kb dyad/proto -km default
```

State on this machine: `qmk` 1.2.0 (uv-installed), and `arm-none-eabi-gcc`
15.2.0 with newlib already present under `~/.local/share/qmk` from qmk's own
toolchain build — not on `PATH`, which is fine because the CLI prepends it at
build time. `qmk_firmware` is a shallow clone at `~/qmk_firmware`, 1.4 GB.

**Gotcha 1 — external userspace does not hold keyboards.** It holds keymaps,
modules and build targets only. `qmk.path.is_keyboard()` checks exactly one
place:

```python
keyboard_json = QMK_FIRMWARE / 'keyboards' / keyboard_name / 'keyboard.json'
```

So `qmk compile -kb dyad/proto` fails with "invalid keyboard_folder_or_all"
however valid the userspace is. Fix: symlink, keeping this repo as the source
of truth.

```bash
ln -sfn ~/workspace/dyad-keyboard/firmware/keyboards/dyad ~/qmk_firmware/keyboards/dyad
```

**Gotcha 2 — SPI needs enabling at the ChibiOS HAL level**, or the build dies
with `"SPI driver activated but no SPI peripheral assigned"`. Setting the pins
in `config.h` is not enough. Needs `halconf.h` (`HAL_USE_SPI TRUE`) and
`mcuconf.h` (`RP_SPI_USE_SPI0 TRUE`), both using `#include_next`.

**Gotcha 3 — mouse keycodes are `MS_BTN1`, not `KC_BTN1`.** Renamed in current
QMK; older guides and forum posts still show the old names.

---

## 3. Bring-up order

Each step is independent and fails cheaply. Do not skip ahead — the point of
the ordering is that when something breaks you know what caused it.

| # | Step | Pass criterion |
|---|---|---|
| 0 | Toolchain | **PASS** 2026-09-13 — `dyad/proto` compiles to UF2 |
| 1 | Pico enumerates, QMK flashes | **PASS** 2026-09-13 |
| 2 | 2×2 matrix on one board | Four distinct keycodes |
| 3 | EC11 in `encoder_map` | **PASS** 2026-09-13 |
| 4 | GC9A01 under Quantum Painter, **direct wiring** | Renders text and an image |
| 5 | GC9A01 **over the 14-pin FFC** | Renders stably. **Record the highest stable SPI clock.** |
| 6 | Cirque standalone (SPI, per the bench wiring) | **PASS** 2026-09-13 — cursor tracks |
| 7 | Split over TRRS, both halves | Both matrices work, `SPLIT_HAND_PIN` distinguishes them |
| 8 | Cirque on the **slave** half | `SPLIT_POINTING_ENABLE` + `POINTING_DEVICE_RIGHT`, USB in the left, cursor still moves |
| 9 | Everything simultaneously | One binary, both halves, all peripherals live |
| 10 | Current measurement | See §4 |

Step 5 and step 8 are the two that can actually change the design. Step 5
tests the known ribbon-SPI risk. Step 8 tests the master/slave choice that
put the display on the left.

---

## 4. Numbers to record

These are the deliverable, as much as the working firmware is. Each one feeds
a decision that is expensive to revisit.

| Measurement | Feeds |
|---|---|
| Peak current, display backlight at full | **LDO sizing** (PLAN.md §4). Do not size the regulator from a datasheet guess. |
| Idle current | Sanity baseline |
| Max stable SPI clock over the FFC | Quantum Painter config, and whether the ribbon risk is real |
| ~~GC9A01 module outside diameter~~ | **CLOSED** from the Waveshare datasheet: 37.5 mm round, 40.4 mm with the tab. Confirm with calipers on arrival. |
| GPIO actually consumed | Confirms the 27-of-30 budget before layout |
| Current per WS2812 at your chosen brightness | The real per-key RGB ceiling |

Write them into `hardware/interface.yaml`, bump its version, and note them in
the changelog.

---

## 5. Gotchas

- **Do not buy a Pico 2.** RP2350 has no QMK support. This is the single
  easiest way to lose a week.
- **Check the Cirque's bus strapping.** Pinnacle modules select I²C or SPI
  with a solder jumper on the module. Ours needs **I²C**. Verify before
  concluding the trackpad is dead.
- **`CIRQUE_PINNACLE_DIAMETER_MM 40`.** QMK defaults to 35. Wrong value does
  not fail loudly — it silently mis-scales every cursor delta.
- **Test the Cirque through its real overlay thickness.** Capacitive
  sensitivity depends on it; a bare sensor on a bench behaves differently
  from one under 1.5 mm of plastic.
- **The Pico has no reset button.** Add one to `RUN`, or plan on unplugging.
- **Test the display on the FFC, not on jumpers.** Jumpers will pass and tell
  you nothing.

---

## 4a. The two current measurements are not the same measurement

They size different things and must not be combined.

| Measure | Sizes | Notes |
|---|---|---|
| RP2040 + display at full backlight + Cirque | The **3V3 LDO** | The only load the regulator actually carries |
| LED strips, 32 and 37 | The **USB / TRRS budget** and the firmware brightness cap | LEDs hang off VBUS, never the LDO (PLAN.md §4) |

Combining them oversizes the regulator for current it never sees.

**On using strips as the proxy.** Valid, with caveats. A 5050 WS2812B is ~60 mA at full white; SK6812MINI-E is smaller-die and draws less, WS2812_2020 less again — so a strip **overestimates**, which is the safe direction for budgeting but not an exact figure. Do not run 69 LEDs at full white from the dev board: that is ~2 A and will brown out USB. Power the strip from 5 V with a common ground, and measure at **the brightness you intend to ship**, because the cap is the number that matters.

**Free bonus test.** The strip answers the `74AHCT125` question from PLAN.md §4 — whether RP2040's 3.3 V data reliably drives 5 V LEDs. Try it *without* a level shifter first. If it is solid over a representative run length, the shifter footprint stays unpopulated.

## 7a. Half-duplex is the shipping choice, not just a bench compromise

The jack on hand (LCSC C26230, PJ325) has **5 pins — a 4-pole TRRS jack plus a
switched insertion contact** — so the jack never limited anything. Only the
cable did, and a TRS cable has three conductors: VCC, GND, and one data line.

**Nothing is lost.** Every split sync feature works half-duplex — pointing
device, layer state, mods, WPM, display state, RGB. QMK's split transport is
request/response, so it is logically half-duplex even over a full-duplex link;
the second wire buys signal margin, not capability.

**And there is a positive reason to keep it.** In a 4-pole jack a TRS plug's
sleeve bridges the ring-2 and sleeve contacts. Leave ring-2 unused and *either*
cable works. Put full-duplex RX there and the wrong cable from the drawer ties
RX to ground. Cable tolerance is worth more here than headroom we do not need.

So: no need to hunt for a TRRS cable. PLAN.md §3 and §5 now specify a 4-pole
jack, half-duplex, ring-2 unconnected.

If the bench link is flaky, the usual cause is the data line not idling high:
4.7 kΩ pull-up from the serial pin to 3V3 on one side.

## 5a. Decision: does the shipping design follow the bench rig?

PLAN.md §5 puts the Cirque on **I²C**, which is what let us drop MISO from the knob connector. Step 6 passing over **SPI** settles the factual half: the module is genuinely SPI-strapped, not merely SPI-wired.

| | Consequence |
|---|---|
| Reflow the module's jumper to I²C | Design unchanged. 14-pin knob FFC, 27 GPIO, no MISO. Costs a fiddly rework on a flex module, and re-tests something already proven working. |
| **Keep SPI — recommended** | MISO returns and takes the knob FFC's **already-specced spare pin**. Still 14 pins, no connector change. GPIO 27 → 28 of 30, two spare. |

**Recommendation: keep SPI.** It is working on real hardware, it costs a pin we had already reserved, and it avoids reworking a flex module to re-reach a state we are already in. The original reason for choosing I²C — fewer wires, and open-drain edges surviving a ribbon better — still holds in the abstract, but not enough to pay rework for.

Still to confirm at step 5/9: that SPI stays reliable **over the 14-pin FFC**, since the bench rig is currently short jumpers. If the ribbon degrades it, revisit.

## 6. Exit criteria

One firmware binary driving a two-board split with the display on the master,
the Cirque on the slave, an encoder on each half, and both matrices scanning —
with the §4 numbers recorded in `interface.yaml`.

That unlocks Phase 3 layout with the pin budget and the LDO sizing confirmed
by measurement rather than assumption.

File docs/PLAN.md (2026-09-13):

# Dyad — split keyboard project plan

**Started:** 2026-09-05
**Deliverables:** KiCad PCB design · 3D-printed case · QMK firmware
**Name:** Dyad — a pair. Two halves, two dials, two boards. QMK keyboard directory `dyad`.
**Headline feature:** each half has a rotary encoder ring; the left ring surrounds a round display, the right ring surrounds a round Cirque trackpad.

---

## 0. Layout of record

**[Hasukey both](https://www.keyboard-layout-editor.com/#/gists/79b213f0ee5e06abae0b7c78ffe1bd76)**, KLE gist `79b213f0ee5e06abae0b7c78ffe1bd76`. Sources vendored in `hardware/layout/`; rendered to scale in `docs/layout.svg`.

| | |
|---|---|
| Total keys | 69 — **32 left, 37 right** |
| Style | Row-staggered, 60%-derived, with arrow cluster on the right |
| Matrix | 5×7 left (35 positions for 32 keys), 5×8 right (40 for 37) |
| Thumb keys | 4 angled: Del +15°, Space −45° (1.5u), Enter +45° (1.5u), Bspc −15° |
| Unlabeled keys | 3, at (7.00, 1.50), (10.50, 3.50), (1.75, 4.50) — **real switches**, legends assigned later in the keymap |
| Knob pods | Inner edge of each half, in the alpha/thumb pocket — see below |

Two consequences ripple through the rest of this plan:

- **No reversible PCB** (§5). The halves are asymmetric; nothing mirrors. Silver lining: two distinct boards let handedness be hardwired rather than jumpered.
- **Ergogen is the wrong tool.** It targets column-staggered ergo boards. With a KLE file as the source of truth, the toolchain is KLE → `adamws/kicad-kbplacer` to place switch footprints from the layout, with `kle2netlist` for the netlist. Evaluate both in Phase 0.

### Knob pods

The stock layout reserves no circular area, so each half grows a pod on its **inner edge**, tucked into the pocket between the last alpha key and the angled thumb key. All 69 keys survive. Positions were solved rather than eyeballed — point-to-rotated-rect clearance against that half's own keys only, minimum 5 mm, closest valid centre to the pocket:

| | Centre (u) | Sensor | Ring OD | Clearances |
|---|---|---|---|---|
| Left — GC9A01 display | **(8.85, 4.20)** | 33 mm | **50 mm** (2.6u) | Space 5.2 mm · B 5.7 mm |
| Right — Cirque TM040040 | **(8.40, 4.20)** | 40 mm | **50 mm** (2.6u) | thumb Enter 5.2 mm · unlabeled key 5.7 mm |

Both pods share a 50 mm outside diameter so the two halves look like a matched pair. The left grew from 45 mm to match, which cost it 2.5 mm of radius and pushed its clearance under the 5 mm floor — so it moved **2.9 mm outboard**, from (8.70, 4.20). The right did not move; it was already a 50 mm ring. The two halves now come out identically spaced from their neighbours.

Both land against exactly the keys they were meant to: B and Space on the left, thumb Enter and the unlabeled key left of N on the right.

### The sensor sits above the mechanism, not inside it

This is the geometry that makes the whole pod work, so it is worth stating explicitly.

The bearing does **not** encircle the sensor. It sits in a plane *below* it. A static centre post rises through the bearing bore and cantilevers the display or trackpad above the moving parts; the ring rotates on the bearing's outer race, underneath. So the bore only has to pass the post and its cable — roughly 12 mm — and never has to clear 40 mm of Cirque.

That leaves a wide choice of ordinary bearings. With a 50 mm ring and a ~2.25 mm wall, anything up to **45.5 mm OD** fits:

| Bearing | Bore × OD × W | |
|---|---|---|
| **6806-2RS** | 30 × 42 × 7 | **pick** — generous bore for post and FFC, 3.5 mm of radial room for the carrier |
| 6805-2RS | 25 × 37 × 7 | more ring wall, smaller bore |
| 6905-2RS | 25 × 42 × 9 | taller section |

The 5.0 mm annulus is therefore a **grip** dimension, not a bearing one. It reads as a 5 mm halo of ring visible around the sensor cap, with the full cylindrical outer wall exposed below it — which is what your fingers actually turn.

Three consequences to carry into Phase 2:

- **Z grows.** Stacking the sensor above the bearing is taller than a coplanar arrangement. The knob stack, not the switches, sets case height — see `hardware/interface.yaml`.
- **The post is a cantilever.** You press on the Cirque with a thumb; deflection there means poor tracking and a cheap feel. Make the post stiff and seat it in a wide boss through the bore, rather than a thin pillar.
- **The bearing is now steel directly beneath the Cirque.** This is *worse* than the coplanar arrangement for capacitive keep-out, not better. Bench-measure it in Phase 2 before committing; a POM or full-complement plastic bearing is the fallback if it detunes.

Two notes on reading the drawing. The two centres have almost the same x, which would be a collision on one board — but these are **two separate PCBs** (§5) that sit apart in use, so each pod extends into space the other never occupies. That inboard freedom is the whole reason the pods aren't outboard where they'd be a pinky reach. And 5 mm is deliberately tight: you grip the ring from its **open outer side**, so the key-side gap only has to clear the keycap, not a fingertip. Confirm that on the Phase 0 mockup before it goes into copper.

Reproduce with `hardware/layout/place.py` (solver) and `hardware/layout/svg2.py` (drawing). Note `docs/layout.svg` is a **diagram, not to scale** — for anything you measure against, use the 1:1 sheets below.

---

## 1. The one idea that makes this buildable

The requirement says "display/trackpad **on top of** the rotary encoder knob." Taken literally that means the display rotates with the knob, which needs a slip ring or a hollow shaft plus a wire loom that survives infinite rotation. Don't do that.

**Invert it: the centre is static, the *ring* rotates around it.**

The display and trackpad are fixed to the case. A knurled ring on the outside spins around them. Visually and ergonomically identical to a knob with a screen on top; electrically trivial, because no wire ever moves.

Every mechanism option below is a way of sensing that ring's rotation.

```
        ┌──── rotating ring (finger contact) ────┐
        │   ┌──── static bezel / keep-out ────┐  │
        │   │   ┌──── display or Cirque ───┐  │  │
        │   │   │      (never moves)       │  │  │
        │   │   └──────────────────────────┘  │  │
        │   └─────────────────────────────────┘  │
        └────────────────────────────────────────┘
```

---

## 2. Ring-encoder mechanism — options and the pick

| | Mechanism | Sensor | QMK support | Cost | Risk |
|---|---|---|---|---|---|
| **A ✅** | Printed internal ring gear drives a pinion on a standard EC11 mounted off-axis | EC11 | Stock quadrature driver | ~$1 | Print tolerance / backlash |
| B | Multipole ring magnet on the rotating ring, sensor read off-axis | AS5304/AS5306 (outputs A/B quadrature) | Stock quadrature driver | ~$25/side | Custom ring magnet sourcing |
| C | COTS hollow-shaft / bore encoder, ring bonded to the shaft | Encoder | Stock quadrature driver | $30–90 | Finding a bore wide enough for the FFC, in budget |
| D | Fallback: static bezel, no encoder on the right; use Cirque circular-scroll gesture | — | `CIRQUE_PINNACLE_CIRCULAR_SCROLL_ENABLE` | $0 | Loses a stated requirement |

**Pick: Option A for v1**, with D held as the right-half escape hatch. Rationale: it needs no exotic BOM, no new firmware driver, and the EC11 supplies real mechanical detents so the ring *feels* like a knob. Gear ratio is a tuning knob — a 3:1 ring:pinion ratio turns the EC11's 20 detents/rev into 60 detents per ring revolution.

An on-axis magnetic sensor (AS5600, MT6701) is the obvious-looking choice and is **wrong here** — it needs a diametric magnet centred on the axis, which is exactly where the display is.

Ring rides on a thin-section ball bearing (6806-2RS class) or a printed race. **Cirque caveat:** the Pinnacle is capacitive. Keep the steel bearing and any metal outside Cirque's keep-out, and verify sensitivity on the bench (Phase 2) before committing the case geometry.

---

## 3. Component decisions

| Slot | Part | Notes |
|---|---|---|
| MCU | **Bare RP2040 (QFN-56) on a shared controller module** | One module design, used on *both* halves — see §4 and §5. 30 GPIO, one assembled design, one board to respin. |
| Round display | **GC9A01 1.28" 240×240 SPI** | Confirmed in QMK Quantum Painter (`qp_gc9a01_make_spi_device`). Note: it's a round *LCD*, not an OLED — genuine round OLEDs have no QMK driver. If you insist on OLED, that becomes a driver-writing subproject. |
| Trackpad | **Cirque Pinnacle TM040040** (40 mm) | Owned already. QMK **`cirque_pinnacle_i2c`** — 3 wires, and open-drain edges tolerate a ribbon better than fast SPI. Set `#define CIRQUE_PINNACLE_DIAMETER_MM 40`; QMK's default is 35 and getting this wrong scales every cursor delta. |
| Encoder | EC11 with detents, off-axis | Plus a separate ring push? Deferred — pressing a ring is mechanically awkward; put the encoder switch on a dedicated key instead. |
| Switches | MX-compatible, Kailh hot-swap sockets | |
| Diodes | 1N4148W SOD-123, one per key, column→row | |
| Per-key RGB | **SK6812MINI-E, reserved not committed** | Footprints on the mains from day one, populated later or never. Data pin, 5 V rail and ground return reserved on the main FFC — see §5. |
| Split link | **USB-C to USB-C, half-duplex** | 3 A instead of the 0.5 A a 3.5 mm jack allows — the jack, not the source, was capping per-key RGB. Hazards are handled by three specific rules in §5. |
| USB | **Two USB-C per half**: host and split link | Same receptacle part for both placements |

**Firmware stack:** QMK, data-driven `keyboard.json`, RP2040 split over PIO full-duplex serial (`SERIAL_DRIVER = vendor`), Quantum Painter for the display, Pointing Device + split pointing sync for the Cirque.

---

## 4. RP2040 subsystem (the controller module)

**RP2040, not RP2350.** QMK's compatible-microcontrollers list still names RP2040 as the only supported Raspberry Pi part. RP2350 would mean pioneering a platform port inside a keyboard project — a bad trade.

**Copy, don't invent.** Raspberry Pi's *Hardware design with RP2040*, Chapter 2 "Minimal Design Example", is the reference schematic. Boards that fail to enumerate are almost always boards that deviated from it.

| Block | Part | Notes |
|---|---|---|
| MCU | RP2040, QFN-56, 0.4 mm pitch, 7×7 mm, centre ground pad | Not hand-solderable without stencil + hot air |
| Flash | W25Q128JVSIQ (16 MB) SOIC-8 | Headroom for Quantum Painter assets. QMK's default flash driver assumes W25Q-compatible; the `RP2040_FLASH_*` defines (`W25X10CL`, `IS25LP080`, `GD25Q64CS`, `AT25SF128A`, `GENERIC_03H`) exist only if you substitute something else. |
| Crystal | 12 MHz fundamental, ≤30 ppm | Load caps per the crystal's own CL spec, 1 kΩ series resistor on XOUT, as on the Pico |
| 3V3 rail | AP2112K-3.3 (600 mA), or a 1 A part | Size it from the **Phase 1 current measurement** — the GC9A01 backlight is the swing factor. Copper pour for thermals: dissipation is (5 − 3.3) × I. |
| Decoupling | Per the minimal design example | ~10× 100 nF plus bulk. Don't economise here. |
| USB | 27 Ω series on D+/D−, tightly coupled and length-matched pair | RP2040 is USB 1.1 **Full Speed, 12 Mbps**. Strict 90 Ω impedance control is not required at that rate. Keep the pair short and symmetric and it will work. |
| ESD | USBLC6-2SC6 on D+/D−, and again on the TRRS lines | |
| BOOTSEL | Momentary to QSPI_SS through 1 kΩ | **Non-optional.** Without it an unflashed board is a brick until you short pads with tweezers. |
| RESET | Momentary shorting RUN to GND | Pair with `RP2040_BOOTLOADER_DOUBLE_TAP_RESET` |
| Power OR-ing | Schottky or ideal-diode between USB VBUS and the TRRS 5 V line | Both halves have USB-C; stop one half back-feeding the other |
| Connectors | 16-pin FFC to the main PCB, 14-pin FFC to the knob module | See §5 for the pinouts |
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

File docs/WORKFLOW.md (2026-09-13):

# Case / PCB co-design workflow

The case and the boards constrain each other, so neither can simply be
"designed first". This is how the two proceed without deadlocking or
silently drifting apart.

---

## 1. It is not one loop — it is three couplings, and only one is circular

| Coupling | Direction | Why |
|---|---|---|
| Layout → main PCB outline, **and** layout → plate/case outline | **one-way, layout wins** | Key positions are frozen (PLAN.md §0). The main PCB edge and the case plate are both offsets of the *same* polygon. Neither can push back on the other. |
| Knob mechanism → knob PCB **and** → pod cavity | **one-way, mechanism wins** | Bearing, ring and sensor stack are physical facts discovered in Phase 2. Board and cavity are both consequences of them. |
| Controller PCB ↔ case cavity | **genuinely two-way** | The only real loop in the project. |

Two of the three apparent circular dependencies dissolve once you notice the
arrows point the same way. Resolve those by *ordering*, and spend the real
effort on the one loop that remains.

---

## 2. The rule: push the uncertainty into the part with the most slack

- **Main PCBs: zero slack.** Key positions fix the outline completely.
- **Knob modules: little slack.** The mechanism fixes them.
- **Controller: enormous slack.** Small, singular, nearly any rectangle will
  do, and ~$15 to respin.

So the controller absorbs the coupling. **Fix its envelope by decree, early
and generously, and design inward.** Do not let the case negotiate with it.

Current envelope: **50 × 35 mm, ≤ 10 mm above the PCB** (`interface.yaml`).
The case guarantees that volume; the controller fits inside it. Neither side
may reshape it without a version bump and a re-fit.

---
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

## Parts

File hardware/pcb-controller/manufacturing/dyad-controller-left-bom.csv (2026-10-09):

Comment | Designator | Footprint | LCSC Part #
100nF | C1,C5,C6,C9,C10,C11,C12,C13,C14,C15 | C_0402_1005Metric | C1525
15pF | C2,C3 | C_0402_1005Metric | C1548
1uF | C4,C8,C16,C17 | C_0402_1005Metric | C52923
10uF | C7 | C_0402_1005Metric | C15525
SS34 | D1 | D_SMA | C8678
500mA | F1,F2 | Fuse_1206_3216Metric | C70076
USB_C_Receptacle_USB2.0 | J1 | USB_C_Receptacle_HRO_TYPE-C-31-M-12 | C165948
HC-FPC-0.5-20P-FH20 | J6 | FPC-SMD_20P-P0.50_HC-FPC-0.5-20P-FH20 | C19273932
HC-FPC-0.5-14P-FH20 | J8 | FPC-SMD_14P-P0.50_HC-FPC-0.5-14P-FH20 | C19273929
USB-C split link | J9 | USB_C_Receptacle_HRO_TYPE-C-31-M-12 | C165948
1k | R1,R2,R7 | R_0402_1005Metric | C11702
5k1 | R3,R4 | R_0402_1005Metric | C25905
27R | R5,R6 | R_0603_1608Metric | C25190
BOOTSEL | SW1 | SW_Push_1P1T_XKB_TS-1187A | C318884
RESET | SW2 | SW_Push_1P1T_XKB_TS-1187A | C318884
W25Q128JVS | U1 | SOIC-8_5.23x5.23mm_P1.27mm | C131025
USBLC6-2SC6 | U2 | SOT-23-6 | C2827654
RP2040 | U3 | RP2040-QFN-56 | C2040
XC6206PxxxMR-Regulator_Linear | U4 | SOT-23 | C5446
12MHz | Y1 | Crystal_SMD_3225-4Pin_3.2x2.5mm | C20625731

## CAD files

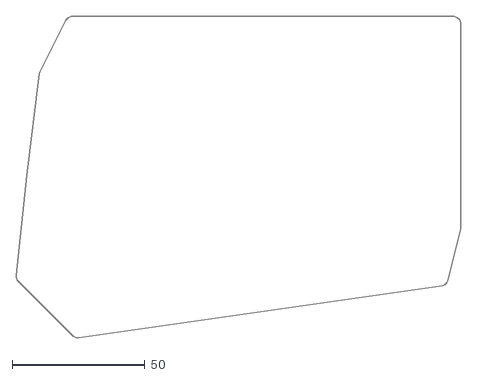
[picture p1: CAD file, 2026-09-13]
hardware/outlines/dyad-main-right-outline.dxf
167.2 x 120.7

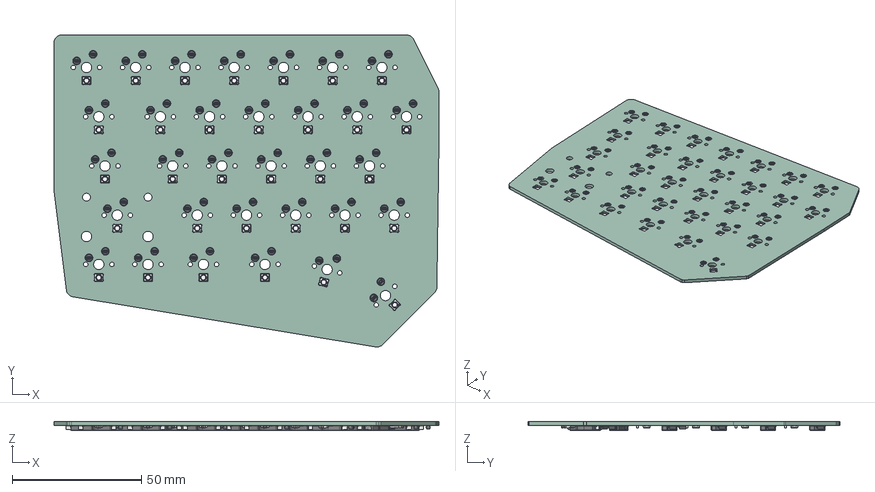
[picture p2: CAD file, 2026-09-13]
hardware/outlines/dyad-main-left.step
149.0 x 120.7 x 3.42 mm
C_0603_1608Metric x 32
Pin1 x 32
Pin2 x 32
Pin3 x 32
Pin4 x 32
D_SOD-123 x 32
Contact x 64
dyad-main-left_PCB

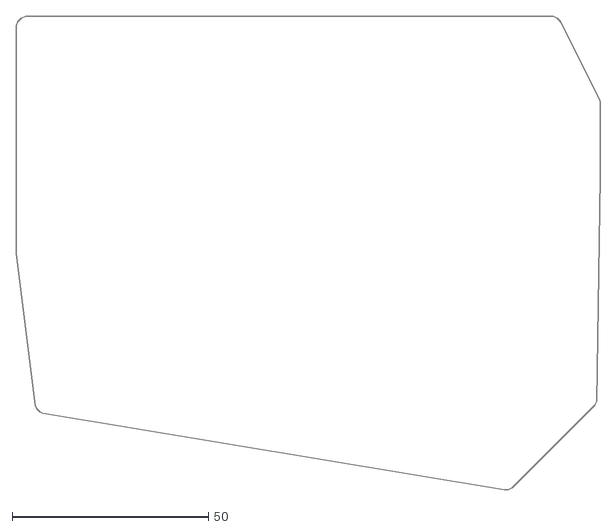
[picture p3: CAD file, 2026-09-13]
hardware/outlines/dyad-main-left-outline.dxf
149.0 x 120.7

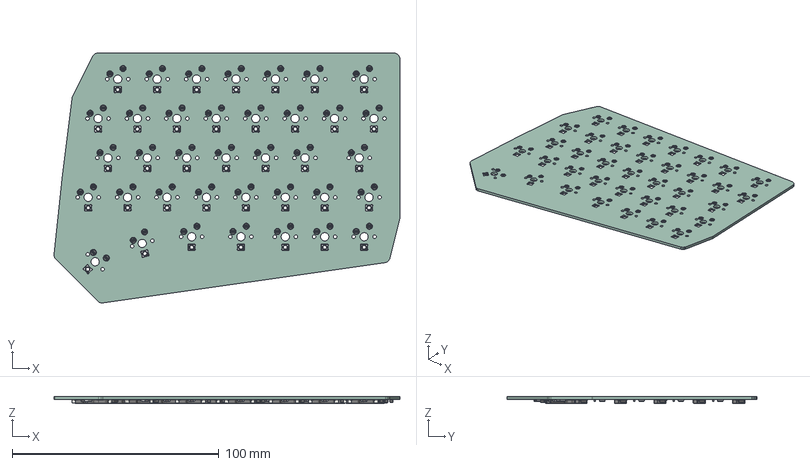
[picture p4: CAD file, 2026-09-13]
hardware/outlines/dyad-main-right.step
167.2 x 120.7 x 3.42 mm
C_0603_1608Metric x 37
Pin1 x 37
Pin2 x 37
Pin3 x 37
Pin4 x 37
Contact x 74
D_SOD-123 x 37
dyad-main-right_PCB

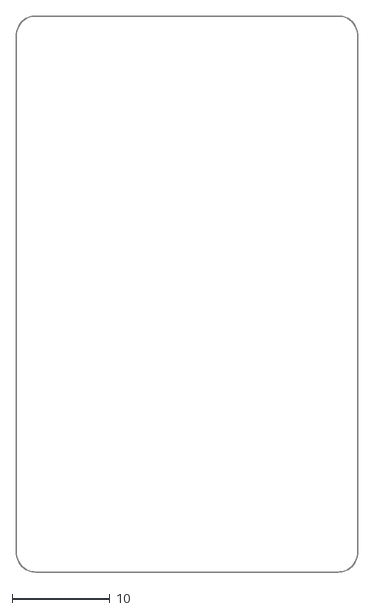
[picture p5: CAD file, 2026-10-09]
hardware/outlines/dyad-controller-outline.dxf
35.0 x 57.0

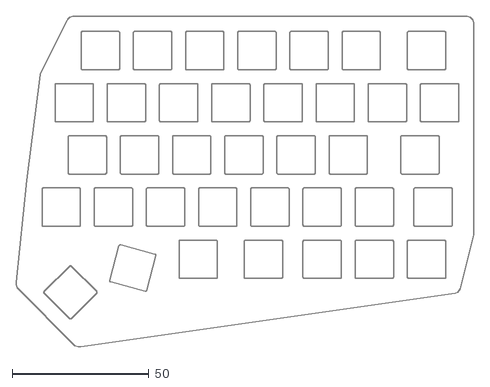
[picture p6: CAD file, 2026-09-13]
hardware/outlines/dyad-plate-right.dxf
167.2 x 120.7

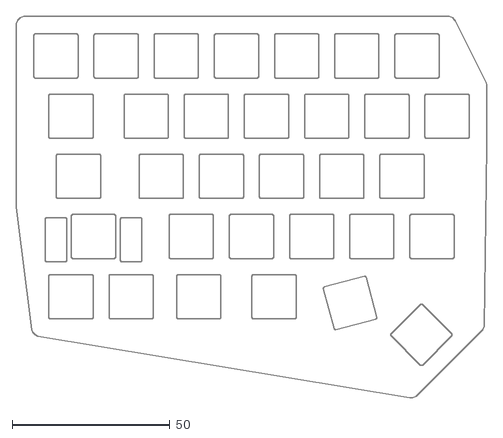
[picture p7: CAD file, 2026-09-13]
hardware/outlines/dyad-plate-left.dxf
149.0 x 120.7

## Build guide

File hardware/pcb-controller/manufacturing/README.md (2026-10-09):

# Controller module — manufacturing files

Exported from `dyad-controller.kicad_pcb` / `.kicad_sch` at commit **89c11e8**
(35 × 57 mm, 2-layer, 1.6 mm). At export: DRC 0 errors, 0 unconnected;
schematic parity 14 field-copy differences only; ERC 145 (inherited baseline).

These are generated files. Regenerate them after any board or schematic
change rather than editing them — the commands are at the end.

## Files

| File | For |
|---|---|
| `dyad-controller-gerbers.zip` | PCB order — upload this. Shared by both halves. |
| `fab/` | The same Gerber and drill files unzipped, so changes show up in diffs. |
| `dyad-controller-left-bom.csv` / `-left-cpl.csv` | Assembly, **left** half |
| `dyad-controller-right-bom.csv` / `-right-cpl.csv` | Assembly, **right** half |

**Two assembly variants, one bare board.** Each half fits a different main
FFC and split USB-C (`docs/CONTROLLER.md` §2):

| | Main FFC | Split USB-C |
|---|---|---|
| Left half | J6 | J9 |
| Right half | J7 | J10 |

Each BOM/CPL pair leaves out the other half's two connectors. Everything
else (38 parts per half) is common. All parts are on the **bottom** side.

## Ordering notes (JLCPCB)

- **Check part rotations in the placement preview.** KiCad's bottom-side
  rotations and JLCPCB's often disagree for some packages — diodes, SOT-23,
  the USB-C receptacles and the FFC connectors are the usual suspects.
- **Extended parts** carry a one-time loading fee each; expect the RP2040,
  flash, ABM8-272-T3 crystal, FFC connectors and TS-1187A buttons among them.
- Still open before ordering (`docs/CONTROLLER.md` §6): the LDO rating
  against the Phase 1 current measurement, button reachability in the case,
  and the FFC cable type (A or B).

## Regenerating

From the repository root, with KiCad 10:

```bash
cd hardware/pcb-controller
kicad-cli pcb export gerbers --layers F.Cu,B.Cu,F.Paste,B.Paste,F.Silkscreen,B.Silkscreen,F.Mask,B.Mask,Edge.Cuts --subtract-soldermask --check-zones -o manufacturing/fab/ dyad-controller.kicad_pcb
kicad-cli pcb export drill --format excellon --excellon-separate-th -o manufacturing/fab/ dyad-controller.kicad_pcb
(cd manufacturing/fab && zip -q -X ../dyad-controller-gerbers.zip *)
kicad-cli sch export bom --fields 'Value,Reference,Footprint,LCSC,${DNP}' --labels 'Comment,Designator,Footprint,LCSC Part #,DNP' --group-by 'Value,Footprint,LCSC' --ref-range-delimiter '' --exclude-dnp -o bom-all.csv dyad-controller.kicad_sch
kicad-cli pcb export pos --format csv --units mm --side both -o pos-all.csv dyad-controller.kicad_pcb
```

Then split `bom-all.csv` / `pos-all.csv` per half: drop J7 and J10 for the
left, J6 and J9 for the right; BOM columns Comment, Designator, Footprint,
LCSC Part #; CPL columns Designator, Mid X, Mid Y, Layer, Rotation.

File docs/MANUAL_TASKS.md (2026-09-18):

# Manual tasks

> **Do not run `hardware/generate_main_pcbs.py` against these boards.**
> It is retired as of 2026-09-15. It deletes and recreates every `.kicad_pcb`
> and `.kicad_sch` it owns, and those files now carry hand work it cannot
> reproduce. Running it once already destroyed a hand-laid serpentine LED
> chain, recovered only from KiCad's `.history` repo.

The generator did its job: placement, matrix nets, LED and capacitor creation,
kbplacer's first-pass routing, the LED-cutout nudge, the two power pours, and
the footprint-to-symbol links. **The board and schematic files are now the
source of truth.** Everything below is hand work in KiCad, and it accumulates
rather than being regenerated away.

Commit as you go. The one thing that saved the LED chain was
`hardware/pcb-main-right/.history` -- KiCad's own version-history git repo,
gitignored but real. `git log` and `git show` work in it.

## Current state

Measured 2026-09-18. **Check against this before starting work; anything
outside it is a real anomaly rather than a known gap.**

| | main-left | main-right | controller |
|---|---|---|---|
| ERC errors | **0** | **0** | 3 |
| ERC violations | 113 | 127 | 152 |
| Unconnected | **0** | **0** | **0** |
| Schematic parity | 1 | 1 | 22 |
| DRC violations | 195 | 253 | 51 |
| DRC errors | 32 | 37 | **0** |

**Every non-zero number above is explained. None is a defect.**

- **main-left parity 1** -- `Missing footprint J1`. The FFC connector is in
  the schematic but the board has not been updated from it yet. Clears with
  Update PCB from Schematic.
- **main-right parity 1** -- `footprint_symbol_field_mismatch` on J1's
  `Pinout` text: the schematic says `ROW4..ROW0` and the board still carries
  the old `ROW0-4` string. Documentation text only, no nets. Clears the same
  way.
- **controller ERC errors 3** -- `pin_not_driven` on GPIO27, GPIO28, GPIO29,
  the three genuine spares. They are unconnected because nothing uses them;
  they want no-connect flags once that is confirmed final.
- **controller parity 22** -- the whole controller schematic has been rebuilt
  (all five connectors, the OR-ing network, both buttons) and **none of it
  has been pushed to the board**, which is still the 45.3 x 93.5 mm reference
  layout. Breakdown: 8 `missing_footprint` (D1, F2, J6-J10, SW2), 3
  `extra_footprint` (J3/J4/J5, deleted from the schematic but still placed),
  and 11 field/net mismatches from SW1's footprint swap and the `VBUS_FUSED`
  rename. All clear when the controller board is rebuilt -- which it must be
  anyway, to reach the 50 x 35 envelope.
- **main DRC errors 32 / 37** -- see below.

Every error is `courtyards_overlap` on a D/SW pair -- the deliberate
diode-under-switch placement, not a defect. Everything else is silkscreen.
Check against this before starting work; anything outside it is a real
anomaly rather than a known gap.

## 0. Push schematic edits to the PCB

The generator writes each footprint's `(path)` link, so **Update PCB from
Schematic matches the existing footprints instead of re-adding all of them.**
Without that link KiCad treats every symbol as new and re-adds the whole
board, which is what once made schematic-side edits impossible to push.

When you update, leave **"Re-link footprints to schematic symbols based on
their reference designators"** unticked -- the paths are already correct and
that option would override them.

If `kicad-cli --schematic-parity` ever floods with `net_conflict` /
"No corresponding pin found in schematic" while the KiCad GUI sees nothing
wrong, suspect the root sheet uuid rather than the board: the root
`.kicad_sch`'s own `(uuid ...)`, the first component of the child sheets'
symbol instance paths, and the Root entry in the `.kicad_pro` `sheets` list
must all agree. See docs/TOOLS.md.

## 1. FFC connector to the controller -- BOTH SCHEMATICS DONE

**Right: schematic done (2026-09-16), routed (2026-09-18).** J1 in
`dyad-main-right-key-matrix.kicad_sch`, all 20 pins wired, handedness tied
to GND. ERC errors 3 -> 0. Footprint
`dyad:FPC-SMD_20P-P0.50_HC-FPC-0.5-20P-FH20` (LCSC C19273932). On the board,
routed, 0 unconnected.

**Left: schematic done (2026-09-18), not yet on the board.** J1 in
`dyad-main-left-key-matrix.kicad_sch`, same symbol, same footprint, same
pin assignment, with two differences the left half forces:

- **Handedness ties to +3V3, not GND.** Pins 19 and 20 are therefore the
  same net here, bussed together under one `+3V3` symbol. On the right they
  are two different nets.
- **Pin 18 (COL7) is idle.** The left half has only COL0-6, as PLAN.md
  specifies. The pin is still *labelled* `COL7` rather than no-connected, so
  the cable line is documented and an eighth column stays wireable. The cost
  is one `isolated_pin_label` warning, which is the same class of accepted
  warning as `LEDOUT` -- correct by spec, not a defect.

ERC errors on main-left 3 -> 0; violations 116 -> 113. The two remaining
`isolated_pin_label` warnings are `COL7` and `LEDOUT`, both expected. The
one `lib_symbol_issues` warning is pre-existing and unrelated.

The `dyad` footprint library is registered in main-left's `fp-lib-table`
with the same relative URI as main-right.

### Pin assignment -- fixed by the right half, match it everywhere

Nothing specified the order, so the right half set it. The left main PCB and
the controller must both follow this table or the cable is wrong:

| Pin | Net | | Pin | Net |
|---|---|---|---|---|
| 1 | VCC (5 V) | | 11 | COL0 |
| 2 | VCC (5 V) | | 12 | COL1 |
| 3 | GND | | 13 | COL2 |
| 4 | LEDIN | | 14 | COL3 |
| 5 | GND | | 15 | COL4 |
| 6 | **ROW4** | | 16 | COL5 |
| 7 | **ROW3** | | 17 | COL6 |
| 8 | **ROW2** | | 18 | COL7 |
| 9 | **ROW1** | | 19 | +3V3 |
| 10 | **ROW0** | | 20 | HAND |

**The rows run descending (ROW4 on pin 6 down to ROW0 on pin 10), changed
2026-09-18 during routing** because ascending forced the five row traces to
cross each other on the way to J1. Columns were not touched. Schematic and
board were both updated, and parity is 0 -- but this is now the order the
**controller and the left half must match**. The earlier ascending table is
wrong wherever it survives.

#### Resolved 2026-09-18: the left pinout is identical, and the controller absorbs the mirror

The left connector faces the other way. Its inner edge is the board's right
edge, and a right-angle part has a fixed ribbon exit, so it ends up rotated
180 degrees with pin 1 physically at the opposite end.

**That does not by itself mean the pin assignment should be mirrored**, and
it is currently *not* -- main-left is wired identically to main-right. Two
reasons:

- A physical flip reverses **all twenty** pins, not just the rows: VCC would
  land where HAND is. Reversing only the row block matches no physical
  reality.
- An end-to-end reversal is exactly what **FFC cable type A vs B** already
  provides. Absorbing the flip in the cable keeps one cable part number, one
  controller pinout and no firmware asymmetry. Mirroring it in copper
  instead would need two visually identical but non-interchangeable cables.

**Facing connectors reverse, and that is a separate thing from the mirror.**
The main PCB's connector and the controller's face each other, so
`main pin n <-> controller pad (21 - n)`. That reversal is **identical on
both halves**, so it is absorbed once in the controller's pad assignment and
changes neither main's pinout. Do not wire the controller off the main table
above -- see CONTROLLER.md §2, *Facing connectors reverse*.

**The decision: the controller gets two 20-pin FFC footprints, one on each
of two edges, wired to the same nets, and only the one facing that half's
main PCB is populated.** Each footprint's orientation is chosen
independently, so the mirror is absorbed in controller copper. Both halves
then keep one cable type, one logical pinout and one firmware, and the left
pinout above is final rather than provisional.

Why there, and not somewhere else:

- **A mirror is not a rotation.** Rotating the controller 180 degrees swaps
  left/right *and* top/bottom, so it would put the main FFC on the right
  edge but throw USB-C onto the wrong one. Only flipping the board over
  truly mirrors it, and that puts every component against the case floor and
  inverts the USB-C port.
- **WORKFLOW.md §2 says to push uncertainty into the part with the most
  slack**, and that is explicitly the controller -- small, singular, ~$15 to
  respin. The mains have zero slack; the right half is already routed.
- The project already uses this exact pattern twice: unpopulated SK6812
  footprints and the DNP 74AHCT125. Unpopulated footprints cost nothing at
  fab; adding them later is a respin.

Cost: about 13 mm of board edge for the unpopulated part, plus 20 short
stubs. Against a 170 mm perimeter that also needs two USB-C and the 14-pin
knob FFC -- roughly 53 mm of connector edge in total -- it fits.

Rejected: folding the cable on one half (cheapest in area, but
assembly-order dependent and the easiest to get silently wrong); relocating
both J1s so the halves are related by translation rather than reflection
(would mean redoing main-right's placement and routing); and flipping the
controller over.

**If main-left wants a reversed pinout for routing, the controller absorbs
it -- not the firmware.** The two controller footprints are separate copper
and need not share a net-to-pad order, so reversing main-left is paid for by
reversing the controller's left-edge footprint. The MCU never sees it.

That **supersedes** the `MATRIX_ROW_PINS_RIGHT` / `MATRIX_COL_PINS_RIGHT`
hatch named here previously, which would have cost a permanent left/right
difference in the firmware build. Same freedom, no asymmetry.

There is even a controller-side argument *for* the reversal: with both
footprints opening outward 180 degrees apart, an identical assignment makes
the 20 nets cross on their way to the second connector, while a reversed one
lets them fan out in parallel. On a 2-layer board whose B.Cu is the ground
pour, that is 20 via pairs saved through exactly the copper PLAN.md wants
continuous. See CONTROLLER.md §2 -- it is a topology argument about a layout
that does not exist yet, so confirm it before relying on it.

So the left pinout is still **decided at main-left's routing**, but the cost
of choosing either way is now known to be low, and the absorbing mechanism
is copper on the controller rather than a firmware fork.

Three choices in there are load-bearing:

- **LEDIN sits at pin 4, between the two GND conductors.** It is the only
  fast edge on the cable, and PLAN.md asks for ground returns between
  signals. The two GNDs are the RGB return anyway, so they cost nothing
  where they sit; splitting them around pin 4 is free shielding.
- **Rows descend, columns ascend.** Not an aesthetic slip -- it is what keeps
  the row traces from crossing on their run to the connector.
- **HAND is pin 20, next to +3V3 at pin 19.** On the *left* half that tie is
  then two adjacent pins. On the *right* half HAND goes to GND, which is a
  via into the existing GND pour, so the far pin costs nothing there either.

The mapping is also stored on J1 itself as a `Pinout` property, so it
survives without this file.

The pinout is already specified in **PLAN.md §Interfaces** and
**CONTROLLER.md §2**. It is exactly 20 lines with **no spare**:

| Lines | |
|---|---|
| 13 | matrix -- 5 rows + 8 columns (left uses 7 and leaves one idle) |
| 1 | handedness -- pulled to 3V3 on the left main PCB, to GND on the right |
| 1 | RGB data (reserved) |
| 1 | 3V3 -- handedness reference only, negligible current |
| 2 | **5 V, doubled** -- a 0.5 mm FFC conductor is good for ~0.5 A |
| 2 | **GND, doubled** -- the per-key RGB return path |

The doubling is not optional headroom: it is what gives ~1 A against ~0.4 A
per half for RGB at capped brightness. PLAN.md §5 works the budget through a
chain of 500 mA limits and lands on 3.5-6 mA per LED as the real ceiling.

### Two signals the boards do not have yet

**The right half now has both** (`GND` tie on J1 pin 20, `+3V3` power symbol
on pin 19, each with a `PWR_FLAG` so ERC knows the connector feeds the
board). **The left half still has neither.** Adding the connector there is
not just placing a part:

- **Handedness** needs a tie on each half -- to 3V3 on the left, to GND on the
  right. That is what makes the two controllers identical and is why it lives
  on the main PCB rather than the controller.
- **3V3** exists on the controller but not on either main PCB; today the mains
  carry only VCC (5 V, the LED rail) and GND. It is needed solely as the
  handedness reference.

Mapping the rest: ROW0-4 and COL0-7 are the 13 matrix lines; VCC is the 5 V
rail and takes two pins; GND takes two; LEDIN is RGB data. **LEDOUT does not
leave the board** -- it is the chain end, and the spec carries only one RGB
data line.

### Part

CONTROLLER.md §3 already chose **HC-FPC-0.5-20P-FH20**, 0.5 mm pitch,
flip-top, right-angle, bottom contact. The 14-pin knob sibling is LCSC
C19273929.

**The 20-pin code is now confirmed: `C19273932`** (Hong Cheng, 2026-09-18).
JLCPCB Extended Part, 1,893 in stock, $0.076 at 1-99. The family is
contiguous -- 8P C19273926, 10P ...927, 12P ...928, 14P ...929, 16P ...930,
18P ...931, **20P ...932**, 24P ...933 -- which is how it was found.

**Kinghelm `KH-FG0.5-H2.0-20PIN` (C2797211) is a real equivalent, but do not
use it.** Same 20P / 0.5 mm / right-angle / bottom-contact / flip-top / 2.0 mm,
and it is in JLCPCB's assembly library -- but **stock is 35 units** against
1,893, and it costs $0.106 vs $0.076. It also numbers **pin 1 at the opposite
end** from the HC part (see below), so it is not a drop-in substitute at
assembly time either.

Reasoning already settled there, do not re-litigate: 0.5 mm over 1.0 mm
because a 20-position 1.0 mm part is ~23 mm of board edge against ~13 mm, on a
50 mm board whose other long edge already carries USB-C and the jack.
Right-angle `FH20` over vertical `LH20` (C49166895) because a vertical part
makes the ribbon exit perpendicular and then bend, which wants headroom the
10 mm envelope does not have.

**Cable type is a live trap.** These are bottom-contact. Type A has contacts
on the same side at both ends, type B on opposite sides, and the wrong one
silently reverses the pinout end to end. Settle it once layout fixes both
connectors' orientations -- not before.

**Footprint: assigned 2026-09-18.** J1 carries
`dyad:FPC-SMD_20P-P0.50_HC-FPC-0.5-20P-FH20`, pulled from LCSC's own package
data for C19273932 with `easyeda2kicad`, so the design-side pads are the
assembly-side part's own. It lives in a **new shared library**,
`hardware/libraries/dyad.pretty`, registered in main-right's `fp-lib-table`
as nickname `dyad` with the relative URI `${KIPRJMOD}/../libraries/dyad.pretty`
so the left half can use the same entry verbatim. The 3D model is beside it
in `hardware/libraries/dyad.3dshapes` -- **`.wrl` only**; easyeda2kicad also
writes a 4 MB `.step`, which is deleted deliberately rather than carried in
git. Re-delete it after any future pull.

Three things had to be corrected after generation; **re-check them on any
future `easyeda2kicad` pull**, they are not one-offs:

1. It emitted the legacy KiCad 5 `(module ...)` format. Fixed with
   `kicad-cli fp upgrade --force`.
2. It set **`(attr through_hole)` on an all-SMD part.** That feeds the
   position files, so it would have corrupted the pick-and-place JLCPCB
   assembles from. Now `(attr smd)`. **Not universal:** the later 14-pin
   pull for C19273929 came out `smd` already, so check it every time rather
   than assuming it is wrong -- or that it is right.
3. It numbered the two hold-down tabs **21** and **22**. The symbol is a
   20-pin `Conn_01x20`, so those would have read as unmatched pads at parity
   time. Renamed to **`MP`**, which is what both KiCad stock and marbastlib
   use for mechanical pads. The 14-pin part numbered its tabs **15** and
   **16** -- same defect, numbers follow the position count.

Also every time: the `.step` is deleted (keep only `.wrl`), and the model
path is rewritten to `${KIPRJMOD}/../libraries/dyad.3dshapes/...` so it
resolves from any of the three projects.

Rejected alternatives, kept for the record -- both are a different vendor to
the chosen part, and neither is needed now:

- `PCM_marbastlib-various:XUNPU_FPC-05F-20PH20_1x20-1MP_P0.5mm_Horizontal`
- `Connector_FFC-FPC:Hirose_FH12-20S-0.5SH_1x20-1MP_P0.50mm_Horizontal`

**Land patterns, measured from the LCSC/EasyEDA package data (2026-09-18):**

| | signal pad | pitch / span | mech pad | pin 1 |
|---|---|---|---|---|
| HC C19273932 | 0.300 x 1.500 | 0.5 / 9.500 | 2.000 x 1.700 at x=±6.450, dy +2.601 | **left** |
| Kinghelm C2797211 | 0.300 x 1.800 | 0.5 / 9.500 | 2.000 x 1.500 at x=±6.450, dy +2.450 | **right** |
| marbastlib XUNPU | 0.300 x 1.350 | 0.5 / 9.500 | 2.000 x 2.500 at x=±6.440, dy +2.375 | **left** |

**Pin 1 sits at opposite ends on the HC and Kinghelm parts.** That is a second
instance of the same trap as cable type A/B: swapping vendors late silently
reverses all 20 lines. Fix the vendor and the footprint together.

The XUNPU footprint *is* usable for the HC part -- same pin-1 end, same pitch,
span and mech-pad x within 0.01 mm -- but its signal pads are 0.15 mm shorter
than HC's land pattern and its mech pads are 0.8 mm longer. It is a near
miss, not a match.

The shipped footprint was verified against the table above after generation:
20 pads numbered 1-20, 0.300 x 1.500 mm, pitch 0.5000, span 9.500, pin 1 on
the **left**, two `MP` pads 2.000 x 1.700 at x=±6.450 and dy +2.600, all SMD,
courtyard present. **Task 0 for main-right is no longer blocked.**

Symbol: `Connector_Generic:Conn_01x20`.

### Workflow

Both schematics carry J1 with the footprint assigned. Right half is routed.

Remaining, in order:

1. **Update PCB from Schematic** on main-left, then **place and route** its
   connector. 20 connections converging on one board edge, so decide where
   it lands *before* routing rather than after. Watch the B.Cu GND pour --
   on the right half, routing the connector split it into three islands, and
   the fix was putting horizontal LED links on one layer and vertical on the
   other. F.Cu is the VCC pour, so a fragmented GND cannot be stitched
   through the other layer.
2. **Settle the left pinout** -- see the provisional note above.
3. **Settle cable type A vs B**, now possible: both connector orientations
   are fixed once main-left is placed.

Cable type (A vs B) stays open until layout fixes both connectors'
orientations -- see the warning above.

## 2. Done -- VCC vias and matrix routing

Both halves are routed: 0 unconnected on each. main-left carries 330 segments
and 32 vias, main-right 413 segments and 37 vias. The VCC vias bridge the
F.Cu pour to the B.Cu-only pads, one per LED/capacitor pair.

Kept here because a regeneration would destroy all of it -- see the warning
at the top.

## 3. LED serpentine chain

Currently every row chains left-to-right, so each row transition is a
full-width flyback:

    LED7  -> LED8    130.0 mm
    LED15 -> LED16   130.0 mm
    LED22 -> LED23   132.3 mm
    LED30 -> LED31   139.1 mm

That is ~531 mm of return trace crossing the board four times. A serpentine
replaces each with a ~19 mm row-pitch hop, saving roughly 455 mm.

**kbplacer cannot do this.** It chains LEDs in matrix-label order, ascending
`(row, col)`. Making a row run right-to-left would need that row's labels
reversed — which directly undoes the column mapping that makes the COL traces
run straight down. One or the other, not both. Verified by testing a reordered
KLE: switch positions came out byte-identical, and the chain did not change.

So the chain has to be re-netted by hand in the board **and** the LED-chain
schematic, keeping the two in parity.

While doing it, flip the LED rotation on the left-to-right rows. At `rot=180`
the pad locals map to board coordinates as DIN on the right, DOUT on the left,
which suits a right-to-left row. For a left-to-right row that puts the pads
facing away from each other: hop is 19 + 5.45 = **24.45 mm** instead of
19 - 5.45 = **13.55 mm**. Rotating those rows to `rot=0` nearly halves every
inter-LED hop. Rows already running right-to-left keep `rot=180`.

An upstream feature request to kbplacer (`--led-chain-order serpentine`) would
remove this whole task; the project is actively maintained.

## 4. Cosmetic, optional

- `silk_over_copper` (96 left / 111 right) — reference designators over pad
  mask openings. Common on dense boards; only matters if you want clean silk.
- `silk_overlap`, `silk_edge_clearance` — designators colliding with each
  other and running past the board edge.

## Known-benign, do not "fix"

- **`courtyards_overlap` on every D/SW pair.** The diode sits inside the
  switch courtyard by design. Courtyard-only, no copper conflict. Either
  shrink the diode courtyard or downgrade the rule; do not move the diodes.
- **`Requested width 2.25u not available ... using 1.0u fallback`.** marbastlib
  has no hotswap switch footprint above 1.75u. The only difference between
  widths is the keycap rectangle on `Dwgs.User`, a documentation layer.
  Pads, drills, silkscreen and both courtyards are identical. The stabiliser
  is separate and correct.

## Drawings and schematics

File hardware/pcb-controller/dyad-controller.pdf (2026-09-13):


1 GPIO8 11 GPIO9 12 GPIO10 13 GPIO11 14 GPIO12 15 GPIO13 16 GPIO14 17 GPIO15 18 TESTEN 19 GPIO0 2 XTAL_IN 20 XTAL_OUT 21 SWCLK 24 SWDIO 25 ~{RUN} 26 GPIO16 27 GPIO17 28 GPIO18 29 GPIO1 3 GPIO19 30 GPIO20 31 GPIO21 32 GPIO22 34 GPIO23 35 GPIO24 36 GPIO25 37 GPIO26/ADC0 38 GPIO27/ADC1 39 GPIO2 4 GPIO28/ADC2 40 GPIO29/ADC3 41 ADC_AVDD 43 VREG_VIN 44 VREG_VOUT 45 D- 46 D+ 47 USB_VDD 48 GPIO3 5 DVDD 50 QSPI_SD3 51 QSPI_SCLK 52 QSPI_SD0 53 QSPI_SD2 54 QSPI_SD1 55 QSPI_SS_N 56 GND 57 GPIO4 6 GPIO5 7 GPIO6 8 GPIO7 9 U3 GND RP2040 +3.3V C6

File: RP2040-Guide.kicad_sch Sheet: / Sleepdealer

Id: 1/1 Title: RP2040 - Design Guide

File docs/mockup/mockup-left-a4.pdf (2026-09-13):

## Hasukey both · LEFT half — GC9A01 display pod (50 mm ring)

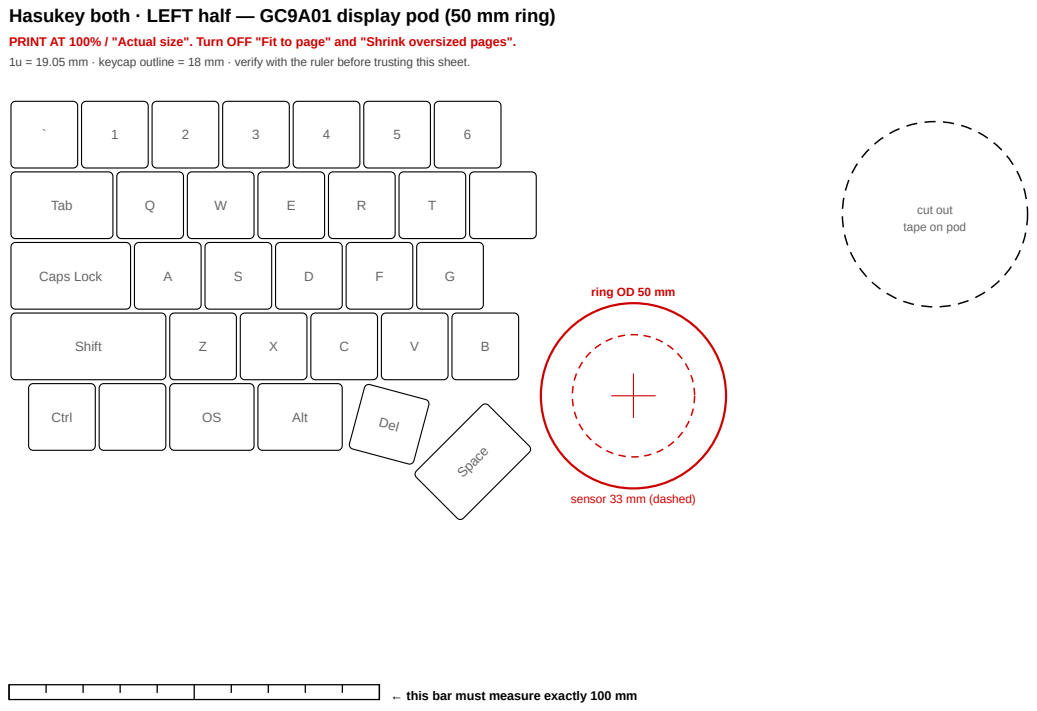
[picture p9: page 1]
Tab; Caps Lock; Shift; Ctrl; Alt; Del; Space

PRINT AT 100% / "Actual size". Turn OFF "Fit to page" and "Shrink oversized pages".
1u = 19.05 mm · keycap outline = 18 mm · verify with the ruler before trusting this sheet.

cut out
tape on pod

ring OD 50 mm

sensor 33 mm (dashed)

← this bar must measure exactly 100 mm

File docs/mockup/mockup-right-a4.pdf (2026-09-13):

## Hasukey both · RIGHT half — Cirque TM040040 pod (50 mm ring)

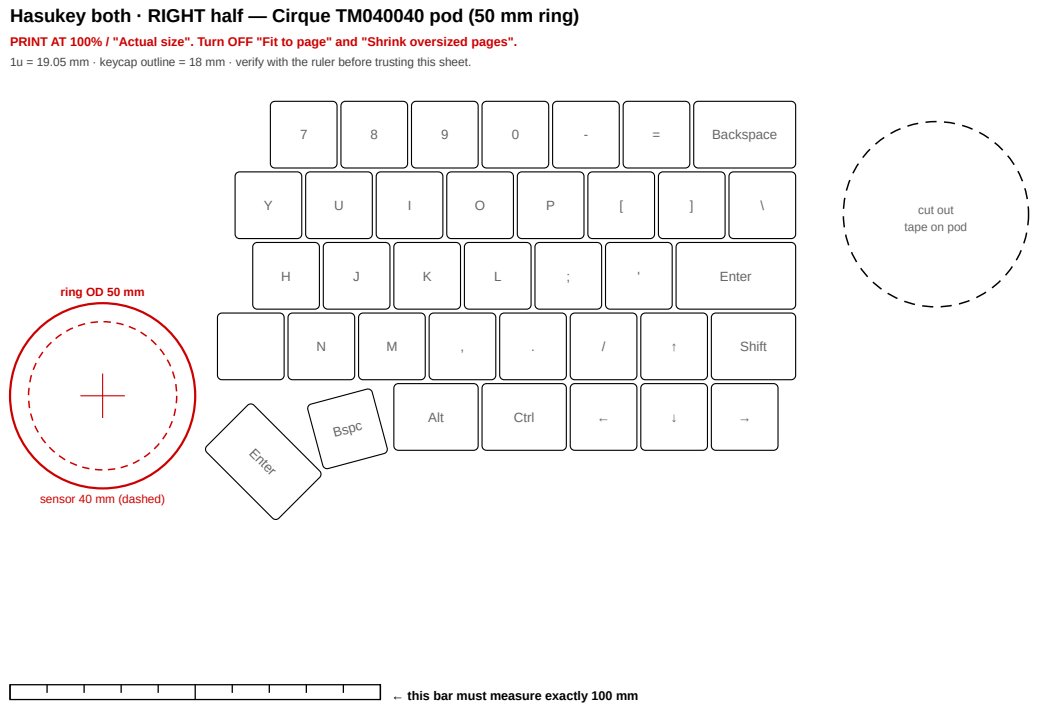
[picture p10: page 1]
Backspace; Enter; Shift; Alt; Ctrl; Bspc

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

cut out
tape on pod

ring OD 50 mm

sensor 40 mm (dashed)

← this bar must measure exactly 100 mm

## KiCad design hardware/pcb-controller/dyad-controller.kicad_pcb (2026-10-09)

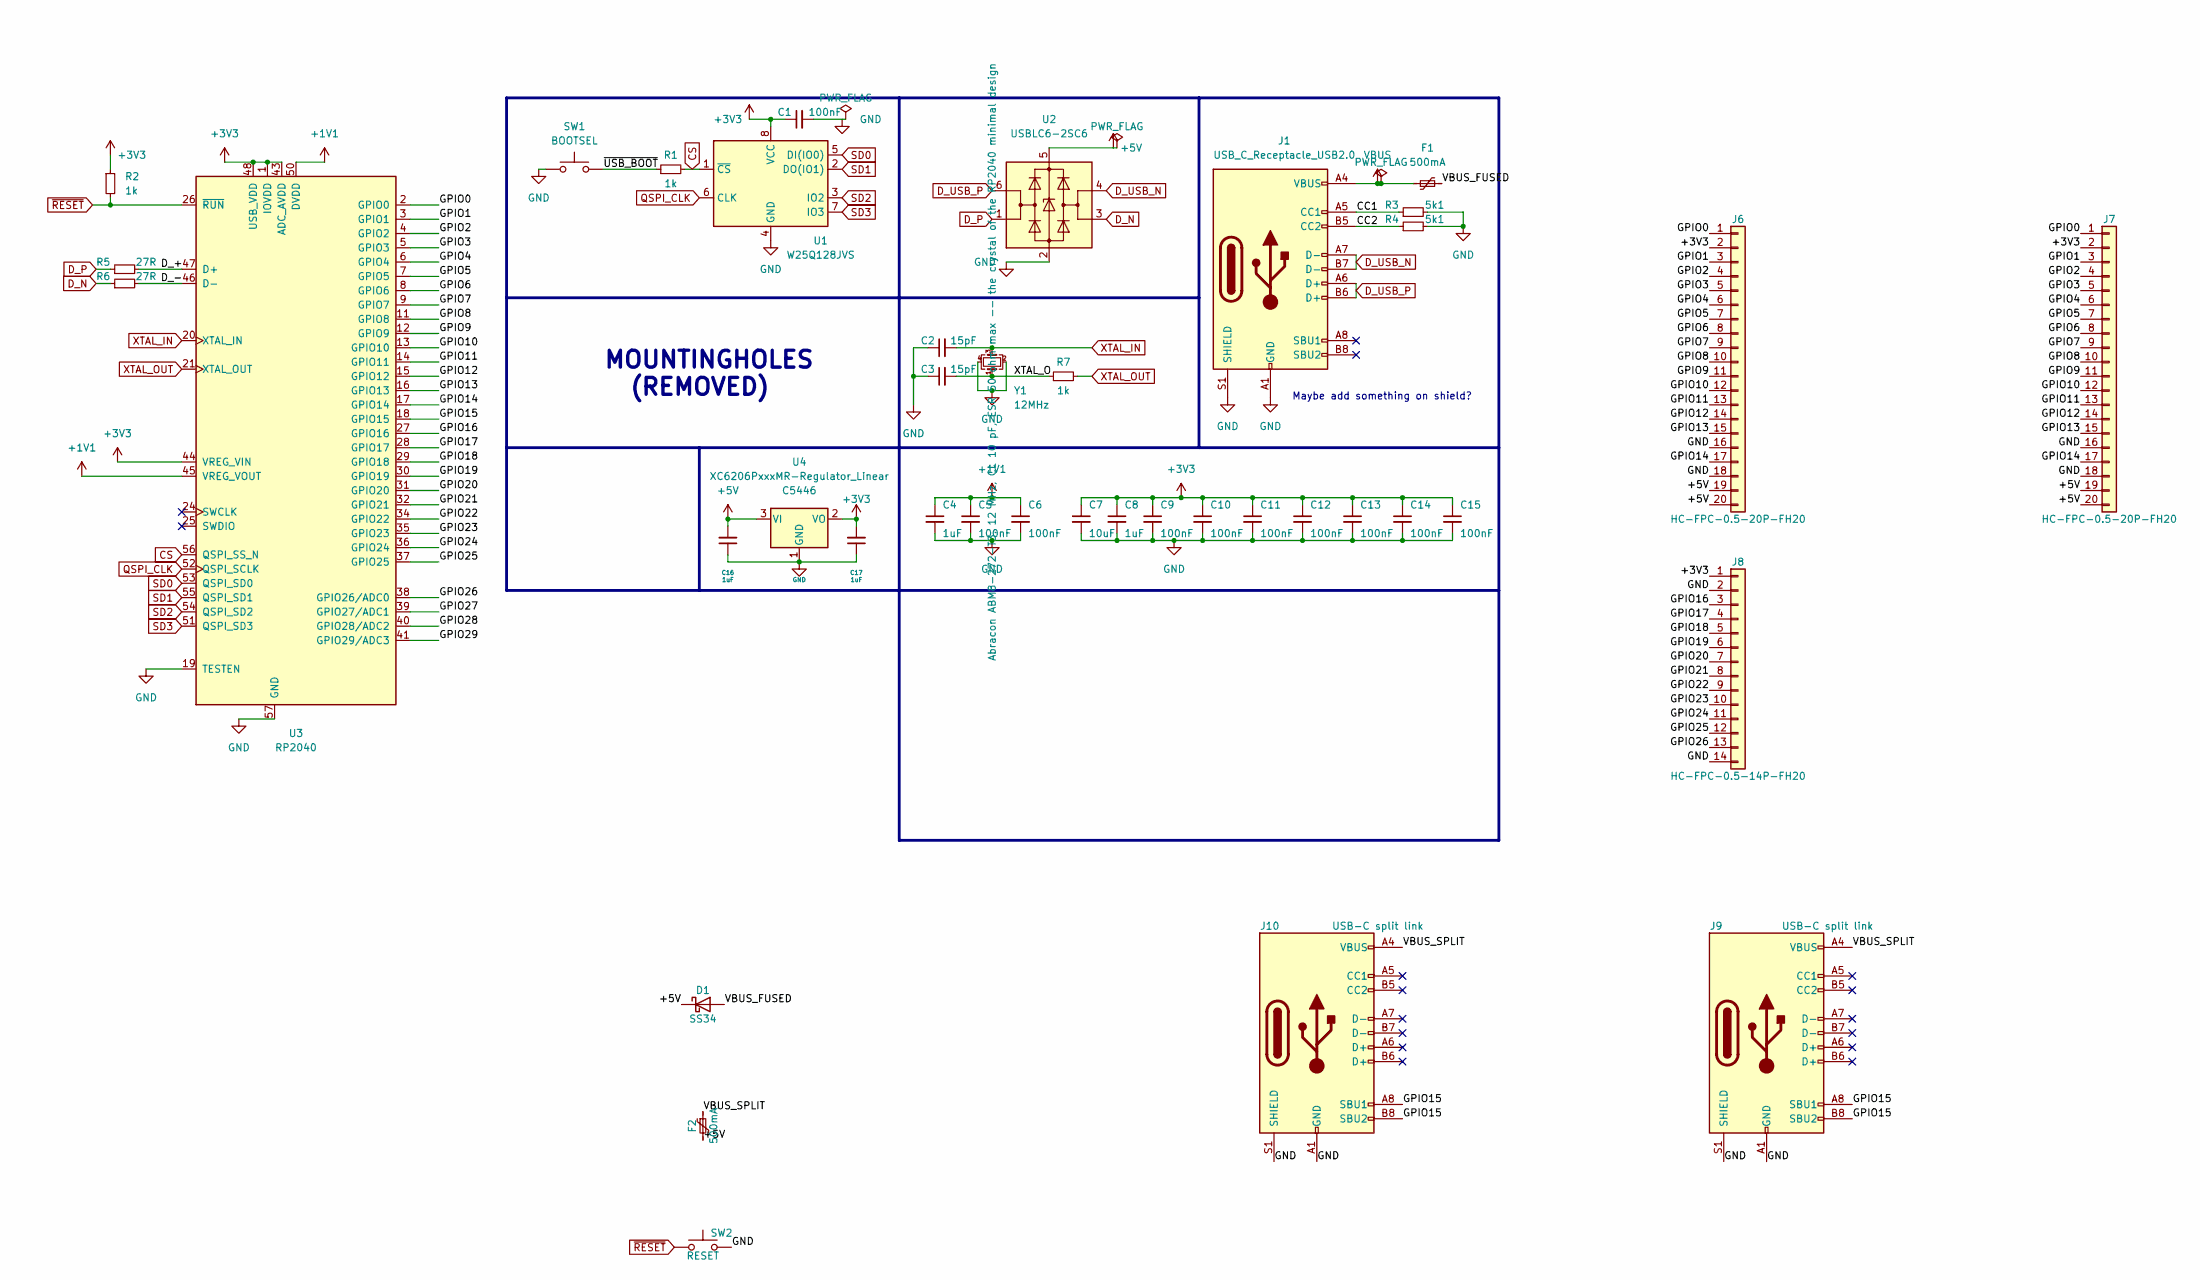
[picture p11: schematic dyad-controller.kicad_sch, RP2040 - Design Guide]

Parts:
C1, C5, C6, C9, C10, C11, C12, C13, C14, C15: 100nF; C_0402_1005Metric; LCSC C1525
C2, C3: 15pF; C_0402_1005Metric; LCSC C1548
C4, C8, C16, C17: 1uF; C_0402_1005Metric; LCSC C52923
C7: 10uF; C_0402_1005Metric; LCSC C15525
D1: SS34; D_SMA; LCSC C8678
F1, F2: 500mA; Fuse_1206_3216Metric; LCSC C70076
J1: USB_C_Receptacle_USB2.0; USB_C_Receptacle_HRO_TYPE-C-31-M-12; LCSC C165948
J6, J7: HC-FPC-0.5-20P-FH20; FPC-SMD_20P-P0.50_HC-FPC-0.5-20P-FH20; LCSC C19273932
J8: HC-FPC-0.5-14P-FH20; FPC-SMD_14P-P0.50_HC-FPC-0.5-14P-FH20; LCSC C19273929
J9, J10: USB-C split link; USB_C_Receptacle_HRO_TYPE-C-31-M-12; LCSC C165948
R1, R2, R7: 1k; R_0402_1005Metric; LCSC C11702
R3, R4: 5k1; R_0402_1005Metric; LCSC C25905
R5, R6: 27R; R_0603_1608Metric; LCSC C25190
SW1: BOOTSEL; SW_Push_1P1T_XKB_TS-1187A; LCSC C318884
SW2: RESET; SW_Push_1P1T_XKB_TS-1187A; LCSC C318884
U1: W25Q128JVS; SOIC-8_5.23x5.23mm_P1.27mm; LCSC C131025
U2: USBLC6-2SC6; SOT-23-6; LCSC C2827654
U3: RP2040; RP2040-QFN-56; LCSC C2040
U4: XC6206PxxxMR-Regulator_Linear; SOT-23; LCSC C5446
Y1: 12MHz; Crystal_SMD_3225-4Pin_3.2x2.5mm; LCSC C20625731

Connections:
+1V1: C4.1, C5.1, C6.1, U3.23 (DVDD), U3.45 (VREG_VOUT), U3.50 (DVDD)
+3V3: C1.1, C7.1, C8.1, C9.1, C10.1, C11.1, C12.1, C13.1, C14.1, C15.1, C17.2, J6.2, J7.2, J8.1, R2.1, U1.8 (VCC), U3.1 (IOVDD), U3.10 (IOVDD), U3.22 (IOVDD), U3.33 (IOVDD), U3.42 (IOVDD), U3.43 (ADC_AVDD), U3.44 (VREG_VIN), U3.48 (USB_VDD), U3.49 (IOVDD), U4.2 (VO)
+5V: C16.2, D1.1 (K), F2.2, J6.19, J6.20, J7.19, J7.20, U2.5 (VBUS), U4.3 (VI)
/CC1: J1.A5 (CC1), R3.1
/CC2: J1.B5 (CC2), R4.1
/D_+: R5.2, U3.47 (D+)
/D_-: R6.2, U3.46 (D-)
/GPIO0: J6.1, J7.1, U3.2 (GPIO0)
/GPIO1: J6.3, J7.3, U3.3 (GPIO1)
/GPIO2: J6.4, J7.4, U3.4 (GPIO2)
/GPIO3: J6.5, J7.5, U3.5 (GPIO3)
/GPIO4: J6.6, J7.6, U3.6 (GPIO4)
/GPIO5: J6.7, J7.7, U3.7 (GPIO5)
/GPIO6: J6.8, J7.8, U3.8 (GPIO6)
/GPIO7: J6.9, J7.9, U3.9 (GPIO7)
/GPIO8: J6.10, J7.10, U3.11 (GPIO8)
/GPIO9: J6.11, J7.11, U3.12 (GPIO9)
/GPIO10: J6.12, J7.12, U3.13 (GPIO10)
/GPIO11: J6.13, J7.13, U3.14 (GPIO11)
/GPIO12: J6.14, J7.14, U3.15 (GPIO12)
/GPIO13: J6.15, J7.15, U3.16 (GPIO13)
/GPIO14: J6.17, J7.17, U3.17 (GPIO14)
/GPIO15: J9.A8 (SBU1), J9.B8 (SBU2), J10.A8 (SBU1), J10.B8 (SBU2), U3.18 (GPIO15)
/GPIO16: J8.3, U3.27 (GPIO16)
/GPIO17: J8.4, U3.28 (GPIO17)
/GPIO18: J8.5, U3.29 (GPIO18)
/GPIO19: J8.6, U3.30 (GPIO19)
/GPIO20: J8.7, U3.31 (GPIO20)
/GPIO21: J8.8, U3.32 (GPIO21)
/GPIO22: J8.9, U3.34 (GPIO22)
/GPIO23: J8.10, U3.35 (GPIO23)
/GPIO24: J8.11, U3.36 (GPIO24)
/GPIO25: J8.12, U3.37 (GPIO25)
/GPIO26: J8.13, U3.38 (GPIO26/ADC0)
/GPIO27: U3.39 (GPIO27/ADC1)
/GPIO28: U3.40 (GPIO28/ADC2)
/GPIO29: U3.41 (GPIO29/ADC3)
/VBUS_FUSED: D1.2 (A), F1.2
/VBUS_SPLIT: F2.1, J9.A4 (VBUS), J9.A9 (VBUS), J9.B4 (VBUS), J9.B9 (VBUS), J10.A4 (VBUS), J10.A9 (VBUS), J10.B4 (VBUS), J10.B9 (VBUS)
/XTAL_O: C3.2, R7.1, Y1.1
/~USB_BOOT: R1.1, SW1.2
CS: R1.2, U1.1 (~CS), U3.56 (QSPI_SS_N)
D_N: R6.1, U2.3 (I/O2)
D_P: R5.1, U2.1 (I/O1)
D_USB_N: J1.A7 (D-), J1.B7 (D-), U2.4 (I/O2)
D_USB_P: J1.A6 (D+), J1.B6 (D+), U2.6 (I/O1)
GND: C1.2, C2.1, C3.1, C4.2, C5.2, C6.2, C7.2, C8.2, C9.2, C10.2, C11.2, C12.2, C13.2, C14.2, C15.2, C16.1, C17.1, J1.A1 (GND), J1.A12 (GND), J1.B1 (GND), J1.B12 (GND), J1.S1 (SHIELD), J6.16, J6.18, J7.16, J7.18, J8.2, J8.14, J9.A1 (GND), J9.A12 (GND), J9.B1 (GND), J9.B12 (GND), J9.S1 (SHIELD), J10.A1 (GND), J10.A12 (GND), J10.B1 (GND), J10.B12 (GND), J10.S1 (SHIELD), R3.2, R4.2, SW1.1, SW2.2, U1.4 (GND), U2.2 (GND), U3.19 (TESTEN), U3.57 (GND), U4.1 (GND), Y1.2, Y1.4; also elsewhere on the board
QSPI_CLK: U1.6 (CLK), U3.52 (QSPI_SCLK)
SD0: U1.5 (DI(IO0)), U3.53 (QSPI_SD0)
SD1: U1.2 (DO(IO1)), U3.55 (QSPI_SD1)
SD2: U1.3 (IO2), U3.54 (QSPI_SD2)
SD3: U1.7 (IO3), U3.51 (QSPI_SD3)
VBUS: F1.1, J1.A4 (VBUS), J1.A9 (VBUS), J1.B4 (VBUS), J1.B9 (VBUS)
XTAL_IN: C2.2, U3.20 (XTAL_IN), Y1.3
XTAL_OUT: R7.2, U3.21 (XTAL_OUT)
~RESET: R2.2, SW2.1, U3.26 (~RUN)

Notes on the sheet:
MOUNTINGHOLES (REMOVED)
Maybe add something on shield?

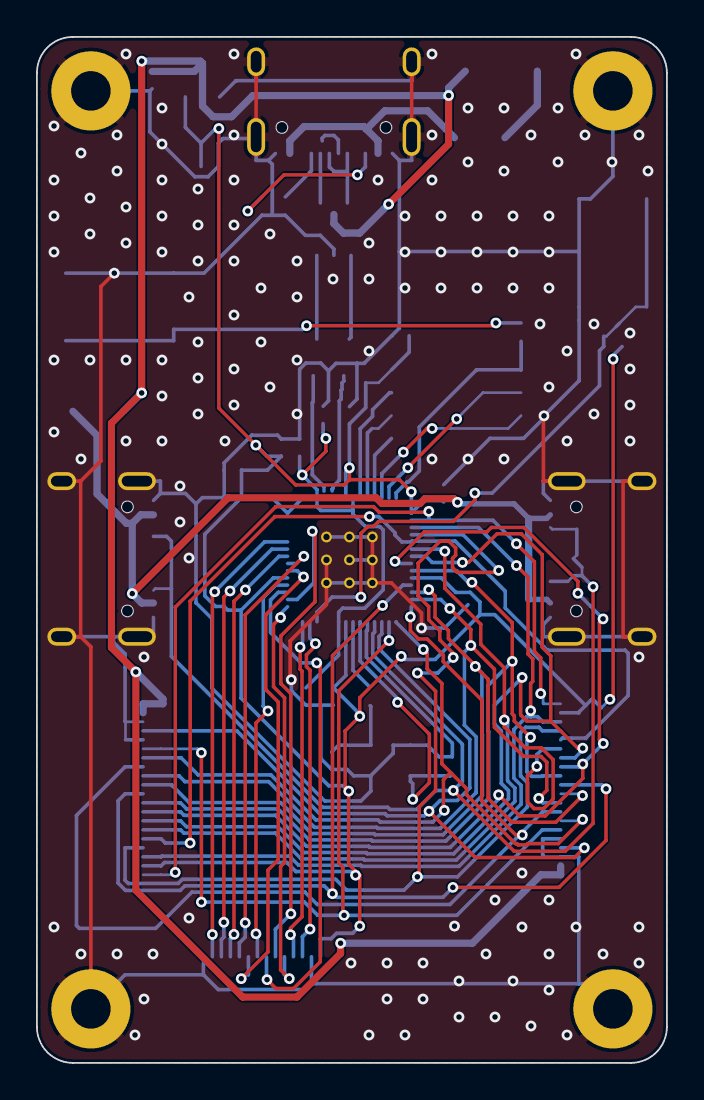
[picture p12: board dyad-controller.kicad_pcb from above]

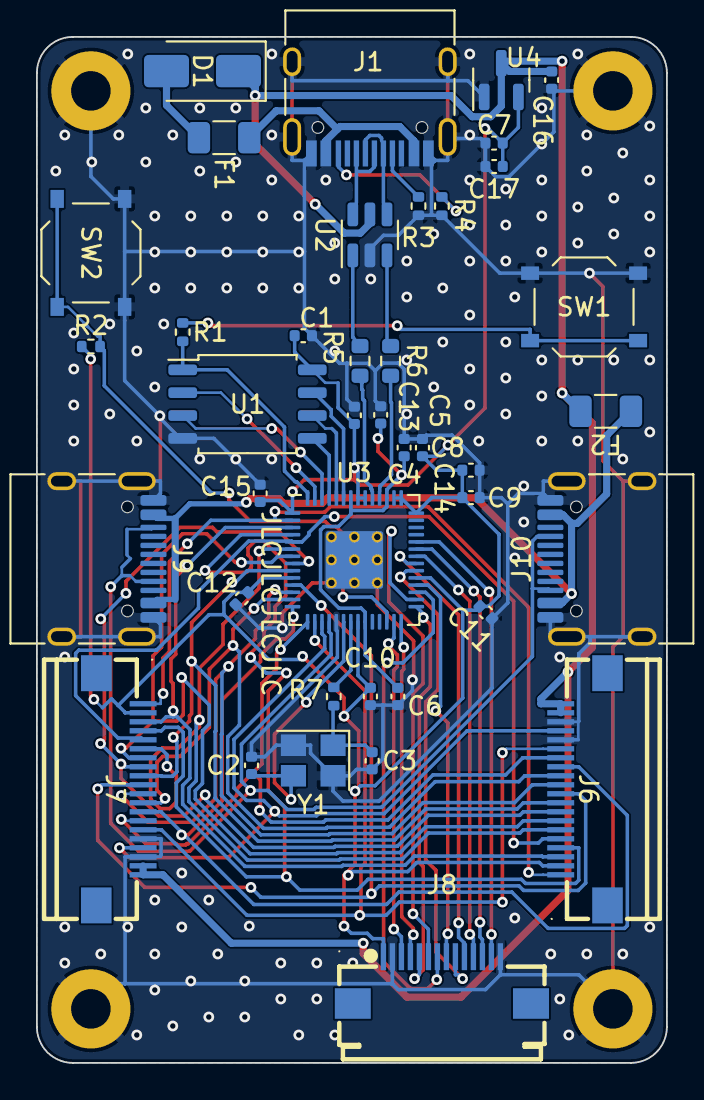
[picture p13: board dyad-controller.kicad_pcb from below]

Board: 2 copper layers, 35.0 x 57.0 mm, 44 parts (40 on the bottom side), 53 nets.

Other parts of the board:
H1, H2, H3, H4: MountingHole_2.2mm_M2_Pad

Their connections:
GND: H1.1, H2.1, H3.1, H4.1; also elsewhere on the board

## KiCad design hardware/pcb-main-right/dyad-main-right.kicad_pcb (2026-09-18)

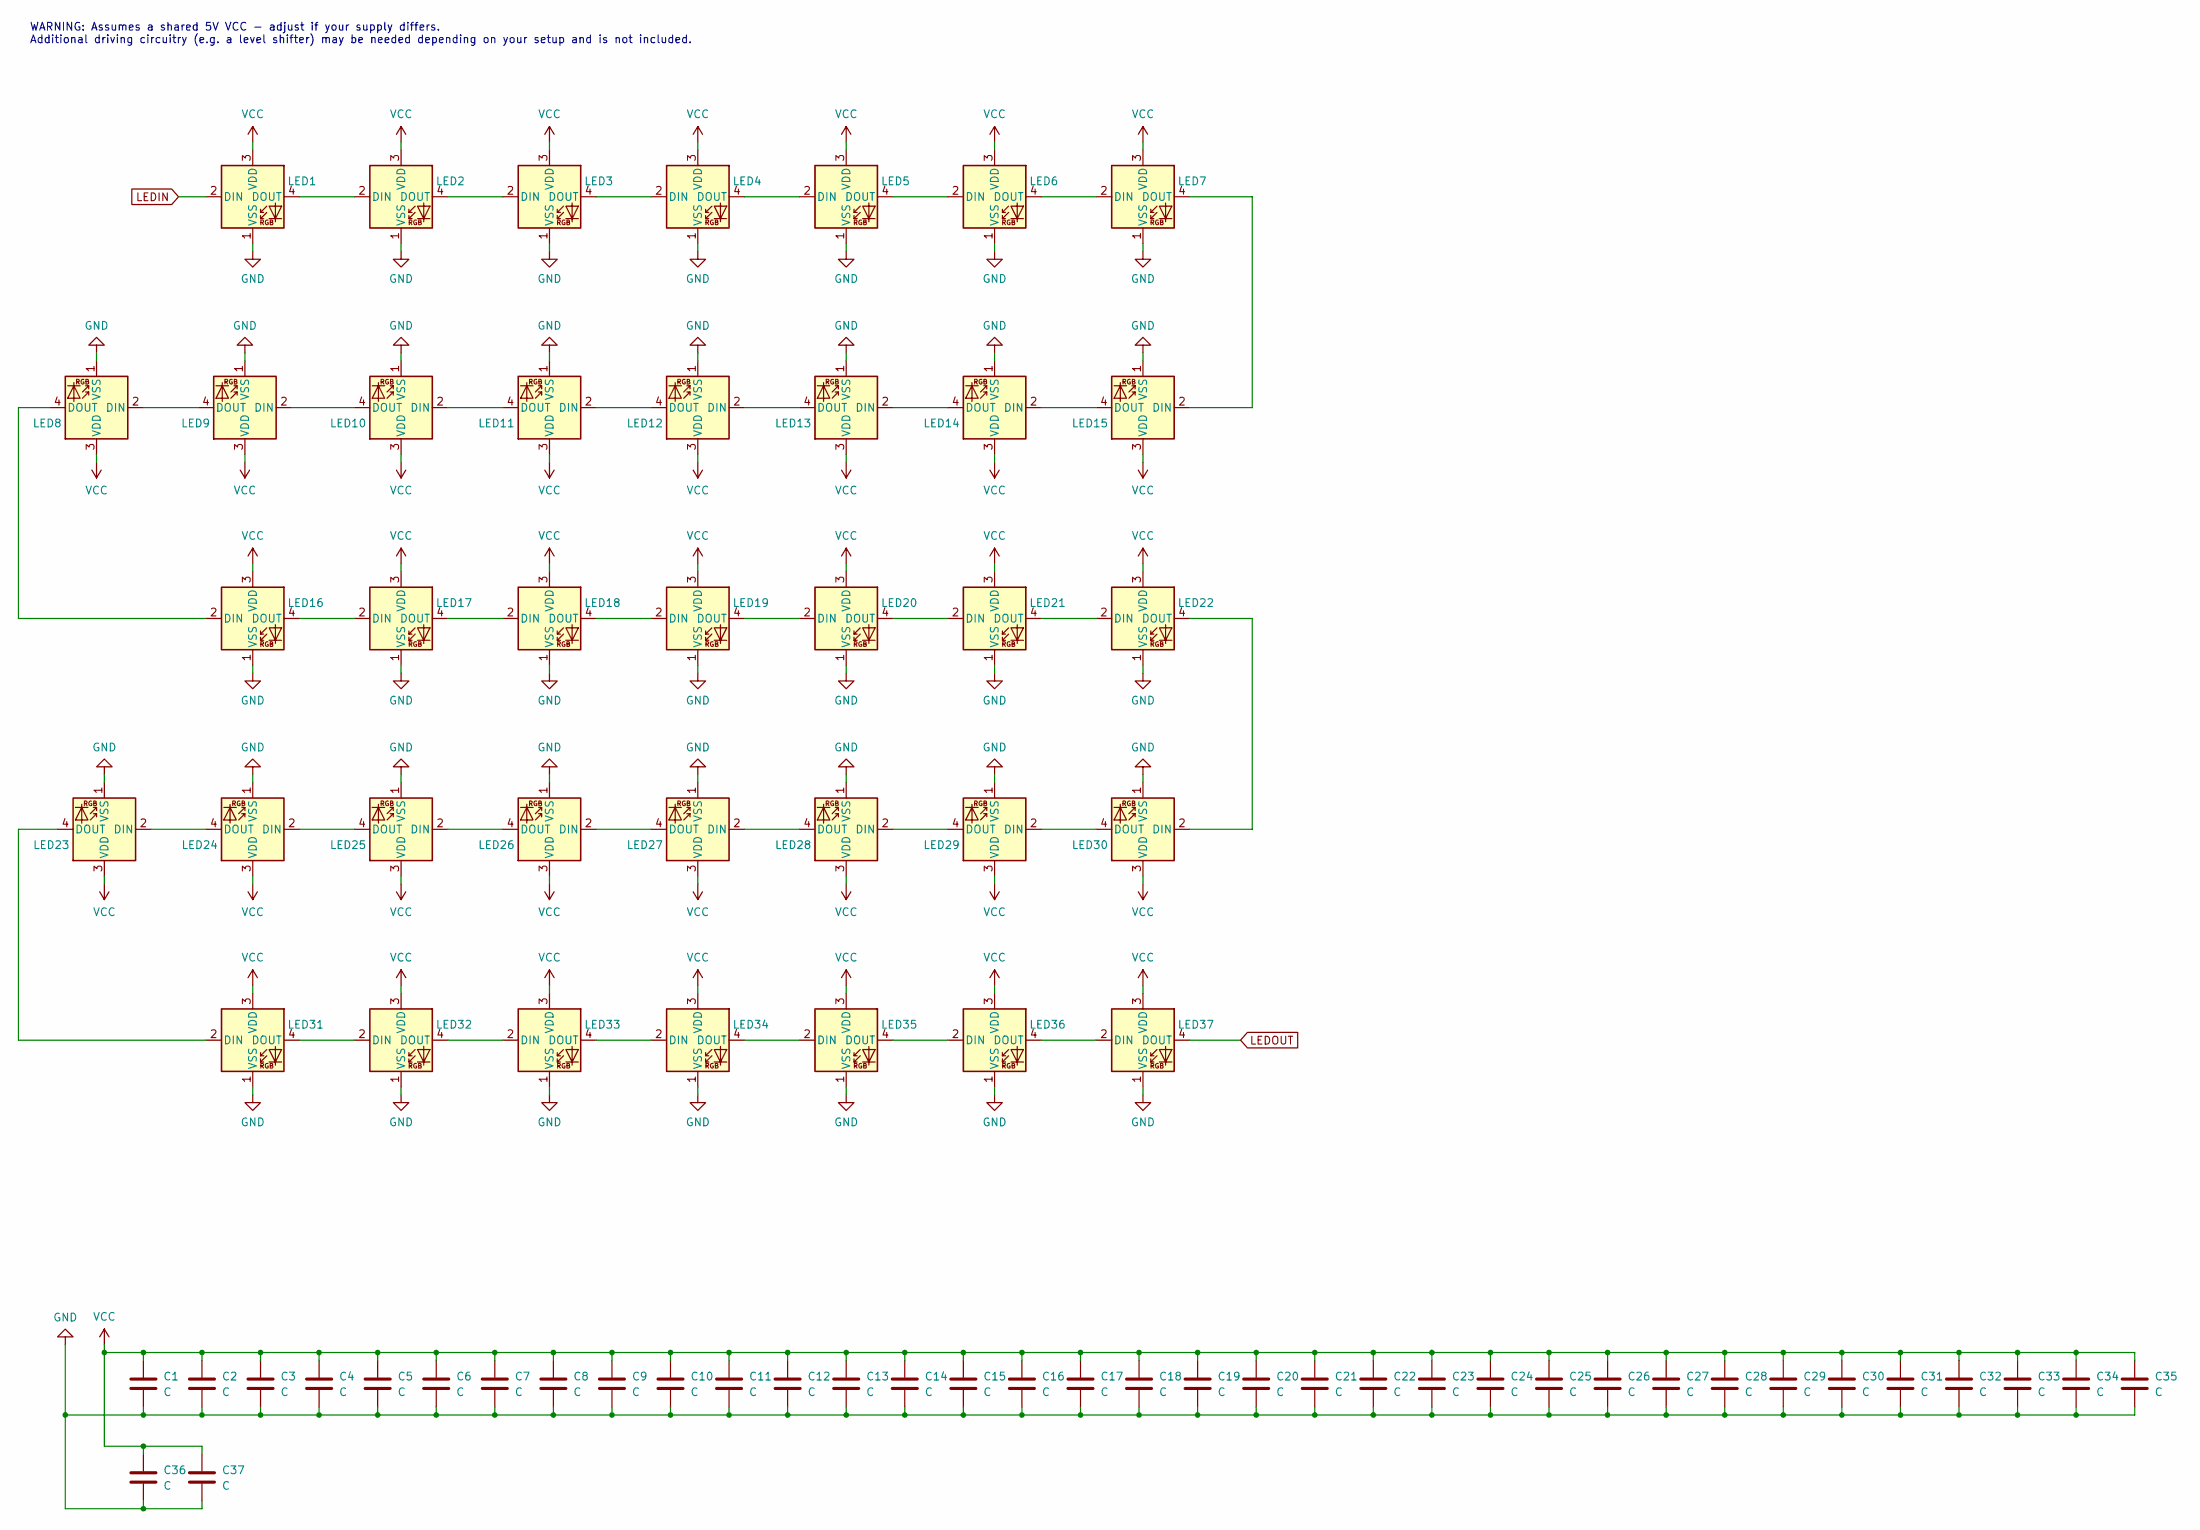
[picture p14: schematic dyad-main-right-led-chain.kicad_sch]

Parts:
C1, C2, C3, C4, C5, C6, C7, C8, C9, C10, C11, C12, C13, C14, C15, C16, C17, C18, C19, C20, C21, C22, C23, C24, C25, C26, C27, C28, C29, C30, C31, C32, C33, C34, C35, C36, C37: C; C_0603_1608Metric
LED1, LED2, LED3, LED4, LED5, LED6, LED7, LED8, LED9, LED10, LED11, LED12, LED13, LED14, LED15, LED16, LED17, LED18, LED19, LED20, LED21, LED22, LED23, LED24, LED25, LED26, LED27, LED28, LED29, LED30, LED31, LED32, LED33, LED34, LED35, LED36, LED37: SK6812MINI-E; LED_SK6812MINI-E_3.2x2.8mm_P1.5mm_ReverseMount

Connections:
GND: C1.2, C2.2, C3.2, C4.2, C5.2, C6.2, C7.2, C8.2, C9.2, C10.2, C11.2, C12.2, C13.2, C14.2, C15.2, C16.2, C17.2, C18.2, C19.2, C20.2, C21.2, C22.2, C23.2, C24.2, C25.2, C26.2, C27.2, C28.2, C29.2, C30.2, C31.2, C32.2, C33.2, C34.2, C35.2, C36.2, C37.2, LED1.1 (VSS), LED2.1 (VSS), LED3.1 (VSS), LED4.1 (VSS), LED5.1 (VSS), LED6.1 (VSS), LED7.1 (VSS), LED8.1 (VSS), LED9.1 (VSS), LED10.1 (VSS), LED11.1 (VSS), LED12.1 (VSS), LED13.1 (VSS), LED14.1 (VSS), LED15.1 (VSS), LED16.1 (VSS), LED17.1 (VSS), LED18.1 (VSS), LED19.1 (VSS), LED20.1 (VSS), LED21.1 (VSS), LED22.1 (VSS), LED23.1 (VSS), LED24.1 (VSS), LED25.1 (VSS), LED26.1 (VSS), LED27.1 (VSS), LED28.1 (VSS), LED29.1 (VSS), LED30.1 (VSS), LED31.1 (VSS), LED32.1 (VSS), LED33.1 (VSS), LED34.1 (VSS), LED35.1 (VSS), LED36.1 (VSS), LED37.1 (VSS); also elsewhere on the board
LEDIN: LED1.2 (DIN); also elsewhere on the board
LEDOUT: LED37.4 (DOUT)
unnamed: LED1.4 (DOUT), LED2.2 (DIN)
unnamed: LED2.4 (DOUT), LED3.2 (DIN)
unnamed: LED3.4 (DOUT), LED4.2 (DIN)
unnamed: LED4.4 (DOUT), LED5.2 (DIN)
unnamed: LED5.4 (DOUT), LED6.2 (DIN)
unnamed: LED6.4 (DOUT), LED7.2 (DIN)
unnamed: LED8.2 (DIN), LED9.4 (DOUT)
unnamed: LED10.2 (DIN), LED11.4 (DOUT)
unnamed: LED9.2 (DIN), LED10.4 (DOUT)
unnamed: LED11.2 (DIN), LED12.4 (DOUT)
unnamed: LED12.2 (DIN), LED13.4 (DOUT)
unnamed: LED13.2 (DIN), LED14.4 (DOUT)
unnamed: LED14.2 (DIN), LED15.4 (DOUT)
unnamed: LED7.4 (DOUT), LED15.2 (DIN)
unnamed: LED8.4 (DOUT), LED16.2 (DIN)
unnamed: LED16.4 (DOUT), LED17.2 (DIN)
unnamed: LED17.4 (DOUT), LED18.2 (DIN)
unnamed: LED18.4 (DOUT), LED19.2 (DIN)
unnamed: LED19.4 (DOUT), LED20.2 (DIN)
unnamed: LED20.4 (DOUT), LED21.2 (DIN)
unnamed: LED21.4 (DOUT), LED22.2 (DIN)
unnamed: LED22.4 (DOUT), LED30.2 (DIN)
unnamed: LED23.2 (DIN), LED24.4 (DOUT)
unnamed: LED23.4 (DOUT), LED31.2 (DIN)
unnamed: LED24.2 (DIN), LED25.4 (DOUT)
unnamed: LED25.2 (DIN), LED26.4 (DOUT)
unnamed: LED26.2 (DIN), LED27.4 (DOUT)
unnamed: LED27.2 (DIN), LED28.4 (DOUT)
unnamed: LED28.2 (DIN), LED29.4 (DOUT)
unnamed: LED29.2 (DIN), LED30.4 (DOUT)
unnamed: LED31.4 (DOUT), LED32.2 (DIN)
unnamed: LED32.4 (DOUT), LED33.2 (DIN)
unnamed: LED33.4 (DOUT), LED34.2 (DIN)
unnamed: LED34.4 (DOUT), LED35.2 (DIN)
unnamed: LED35.4 (DOUT), LED36.2 (DIN)
unnamed: LED36.4 (DOUT), LED37.2 (DIN)
VCC: C1.1, C2.1, C3.1, C4.1, C5.1, C6.1, C7.1, C8.1, C9.1, C10.1, C11.1, C12.1, C13.1, C14.1, C15.1, C16.1, C17.1, C18.1, C19.1, C20.1, C21.1, C22.1, C23.1, C24.1, C25.1, C26.1, C27.1, C28.1, C29.1, C30.1, C31.1, C32.1, C33.1, C34.1, C35.1, C36.1, C37.1, LED1.3 (VDD), LED2.3 (VDD), LED3.3 (VDD), LED4.3 (VDD), LED5.3 (VDD), LED6.3 (VDD), LED7.3 (VDD), LED8.3 (VDD), LED9.3 (VDD), LED10.3 (VDD), LED11.3 (VDD), LED12.3 (VDD), LED13.3 (VDD), LED14.3 (VDD), LED15.3 (VDD), LED16.3 (VDD), LED17.3 (VDD), LED18.3 (VDD), LED19.3 (VDD), LED20.3 (VDD), LED21.3 (VDD), LED22.3 (VDD), LED23.3 (VDD), LED24.3 (VDD), LED25.3 (VDD), LED26.3 (VDD), LED27.3 (VDD), LED28.3 (VDD), LED29.3 (VDD), LED30.3 (VDD), LED31.3 (VDD), LED32.3 (VDD), LED33.3 (VDD), LED34.3 (VDD), LED35.3 (VDD), LED36.3 (VDD), LED37.3 (VDD); also elsewhere on the board

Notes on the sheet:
WARNING: Assumes a shared 5V VCC - adjust if your supply differs. Additional driving circuitry (e.g. a level shifter) may be needed depending on your setup and is not included.

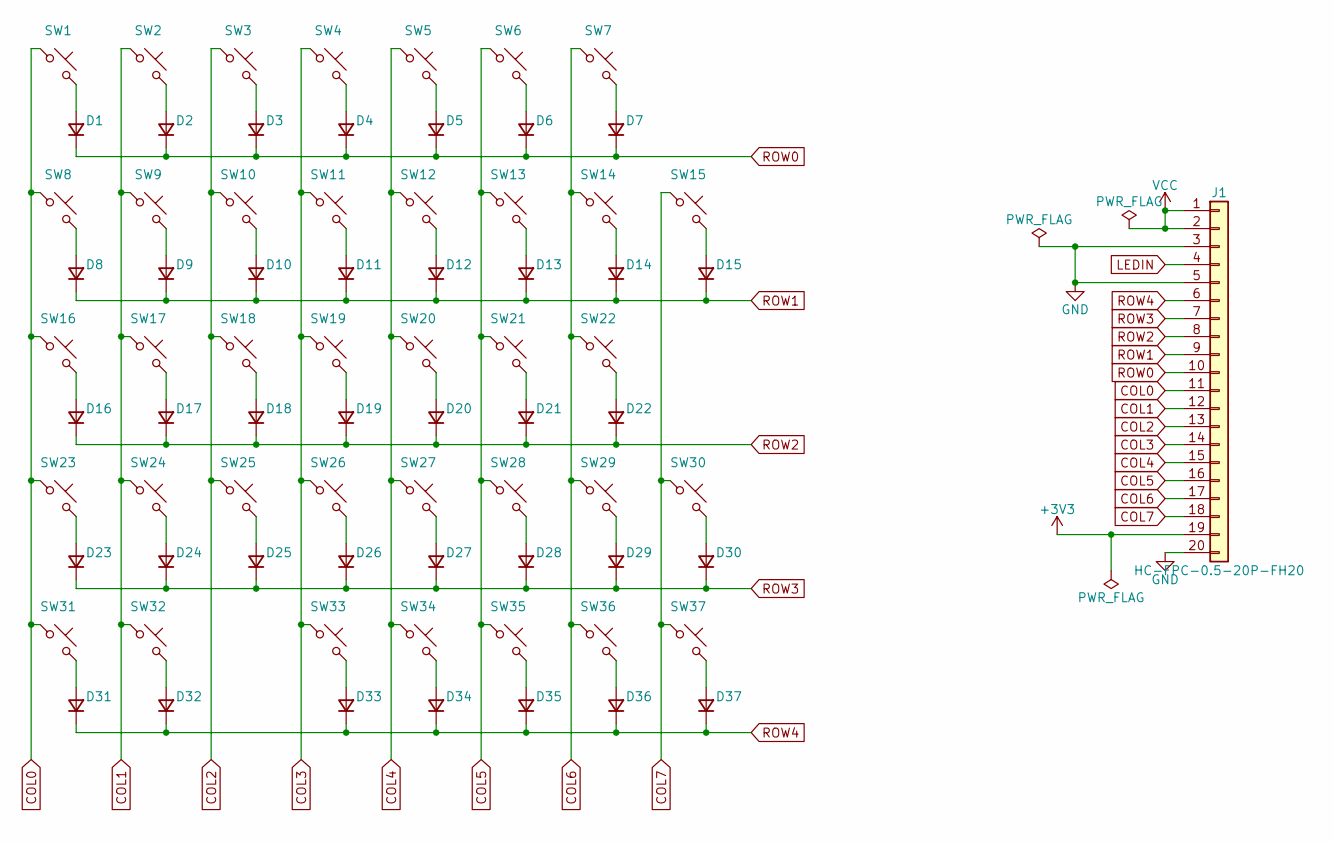
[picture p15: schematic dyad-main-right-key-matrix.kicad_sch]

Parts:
D1, D2, D3, D4, D5, D6, D7, D8, D9, D10, D11, D12, D13, D14, D15, D16, D17, D18, D19, D20, D21, D22, D23, D24, D25, D26, D27, D28, D29, D30, D31, D32, D33, D34, D35, D36, D37: D; D_SOD-123
J1: HC-FPC-0.5-20P-FH20; FPC-SMD_20P-P0.50_HC-FPC-0.5-20P-FH20; MPN HC-FPC-0.5-20P-FH20; LCSC C19273932
SW1, SW2, SW3, SW4, SW5, SW6, SW8, SW9, SW10, SW11, SW12, SW13, SW14, SW15, SW16, SW17, SW18, SW19, SW20, SW21, SW23, SW24, SW25, SW26, SW27, SW28, SW29, SW32, SW35, SW36, SW37: SW_Push; SW_MX_HS_CPG151101S11_1u
SW7, SW31: SW_Push; SW_MX_HS_CPG151101S11_1.5u
SW22: SW_Push; SW_MX_HS_CPG151101S11_1.75u
SW30, SW33, SW34: SW_Push; SW_MX_HS_CPG151101S11_1.25u

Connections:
+3V3: J1.19
COL0: J1.11, SW1.1, SW8.1, SW16.1, SW23.1, SW31.1
COL1: J1.12, SW2.1, SW9.1, SW17.1, SW24.1, SW32.1
COL2: J1.13, SW3.1, SW10.1, SW18.1, SW25.1
COL3: J1.14, SW4.1, SW11.1, SW19.1, SW26.1, SW33.1
COL4: J1.15, SW5.1, SW12.1, SW20.1, SW27.1, SW34.1
COL5: J1.16, SW6.1, SW13.1, SW21.1, SW28.1, SW35.1
COL6: J1.17, SW7.1, SW14.1, SW22.1, SW29.1, SW36.1
COL7: J1.18, SW15.1, SW30.1, SW37.1
GND: J1.3, J1.5, J1.20; also elsewhere on the board
LEDIN: J1.4; also elsewhere on the board
unnamed: D1.2 (A), SW1.2
unnamed: D2.2 (A), SW2.2
unnamed: D3.2 (A), SW3.2
unnamed: D4.2 (A), SW4.2
unnamed: D5.2 (A), SW5.2
unnamed: D6.2 (A), SW6.2
unnamed: D7.2 (A), SW7.2
unnamed: D8.2 (A), SW8.2
unnamed: D9.2 (A), SW9.2
unnamed: D10.2 (A), SW10.2
unnamed: D11.2 (A), SW11.2
unnamed: D12.2 (A), SW12.2
unnamed: D13.2 (A), SW13.2
unnamed: D14.2 (A), SW14.2
unnamed: D15.2 (A), SW15.2
unnamed: D16.2 (A), SW16.2
unnamed: D17.2 (A), SW17.2
unnamed: D18.2 (A), SW18.2
unnamed: D19.2 (A), SW19.2
unnamed: D20.2 (A), SW20.2
unnamed: D21.2 (A), SW21.2
unnamed: D22.2 (A), SW22.2
unnamed: D23.2 (A), SW23.2
unnamed: D24.2 (A), SW24.2
unnamed: D25.2 (A), SW25.2
unnamed: D26.2 (A), SW26.2
unnamed: D27.2 (A), SW27.2
unnamed: D28.2 (A), SW28.2
unnamed: D29.2 (A), SW29.2
unnamed: D30.2 (A), SW30.2
unnamed: D31.2 (A), SW31.2
unnamed: D32.2 (A), SW32.2
unnamed: D33.2 (A), SW33.2
unnamed: D34.2 (A), SW34.2
unnamed: D35.2 (A), SW35.2
unnamed: D36.2 (A), SW36.2
unnamed: D37.2 (A), SW37.2
ROW0: D1.1 (K), D2.1 (K), D3.1 (K), D4.1 (K), D5.1 (K), D6.1 (K), D7.1 (K), J1.10
ROW1: D8.1 (K), D9.1 (K), D10.1 (K), D11.1 (K), D12.1 (K), D13.1 (K), D14.1 (K), D15.1 (K), J1.9
ROW2: D16.1 (K), D17.1 (K), D18.1 (K), D19.1 (K), D20.1 (K), D21.1 (K), D22.1 (K), J1.8
ROW3: D23.1 (K), D24.1 (K), D25.1 (K), D26.1 (K), D27.1 (K), D28.1 (K), D29.1 (K), D30.1 (K), J1.7
ROW4: D31.1 (K), D32.1 (K), D33.1 (K), D34.1 (K), D35.1 (K), D36.1 (K), D37.1 (K), J1.6
VCC: J1.1, J1.2; also elsewhere on the board

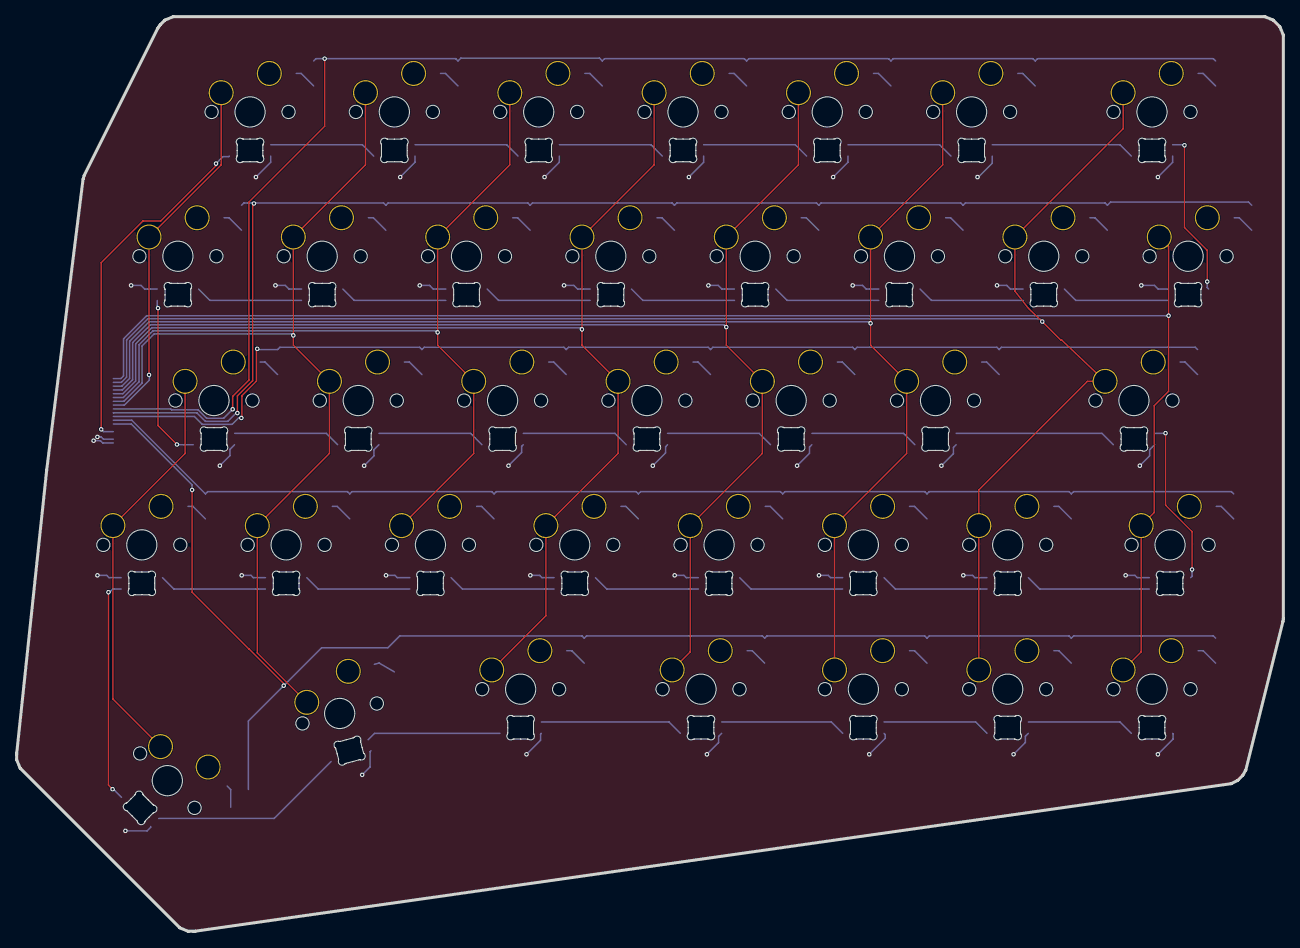
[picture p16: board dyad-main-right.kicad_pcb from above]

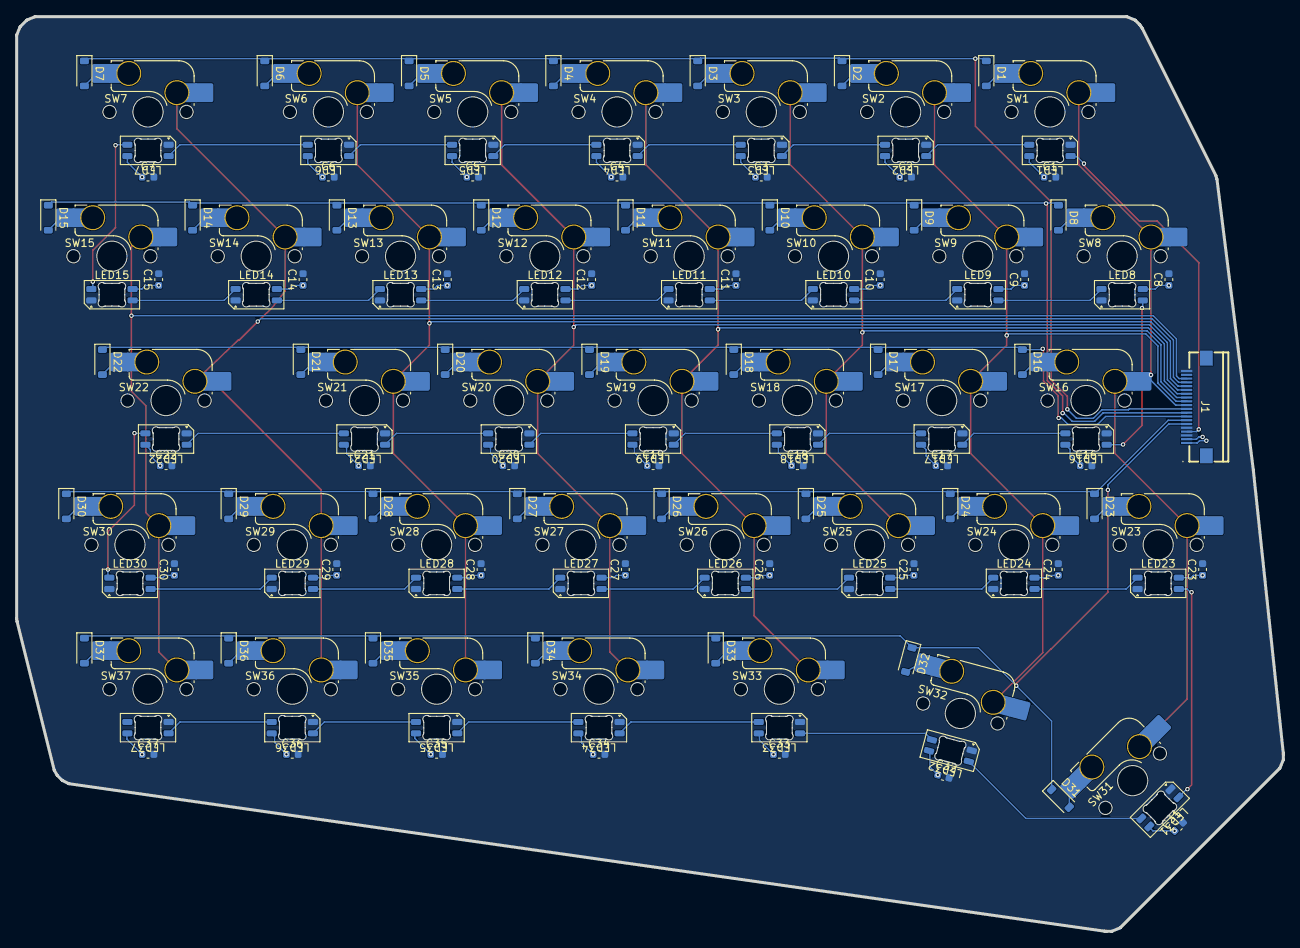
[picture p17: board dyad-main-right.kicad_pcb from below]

Board: 2 copper layers, 167.2 x 120.7 mm, 149 parts (149 on the bottom side), 89 nets.

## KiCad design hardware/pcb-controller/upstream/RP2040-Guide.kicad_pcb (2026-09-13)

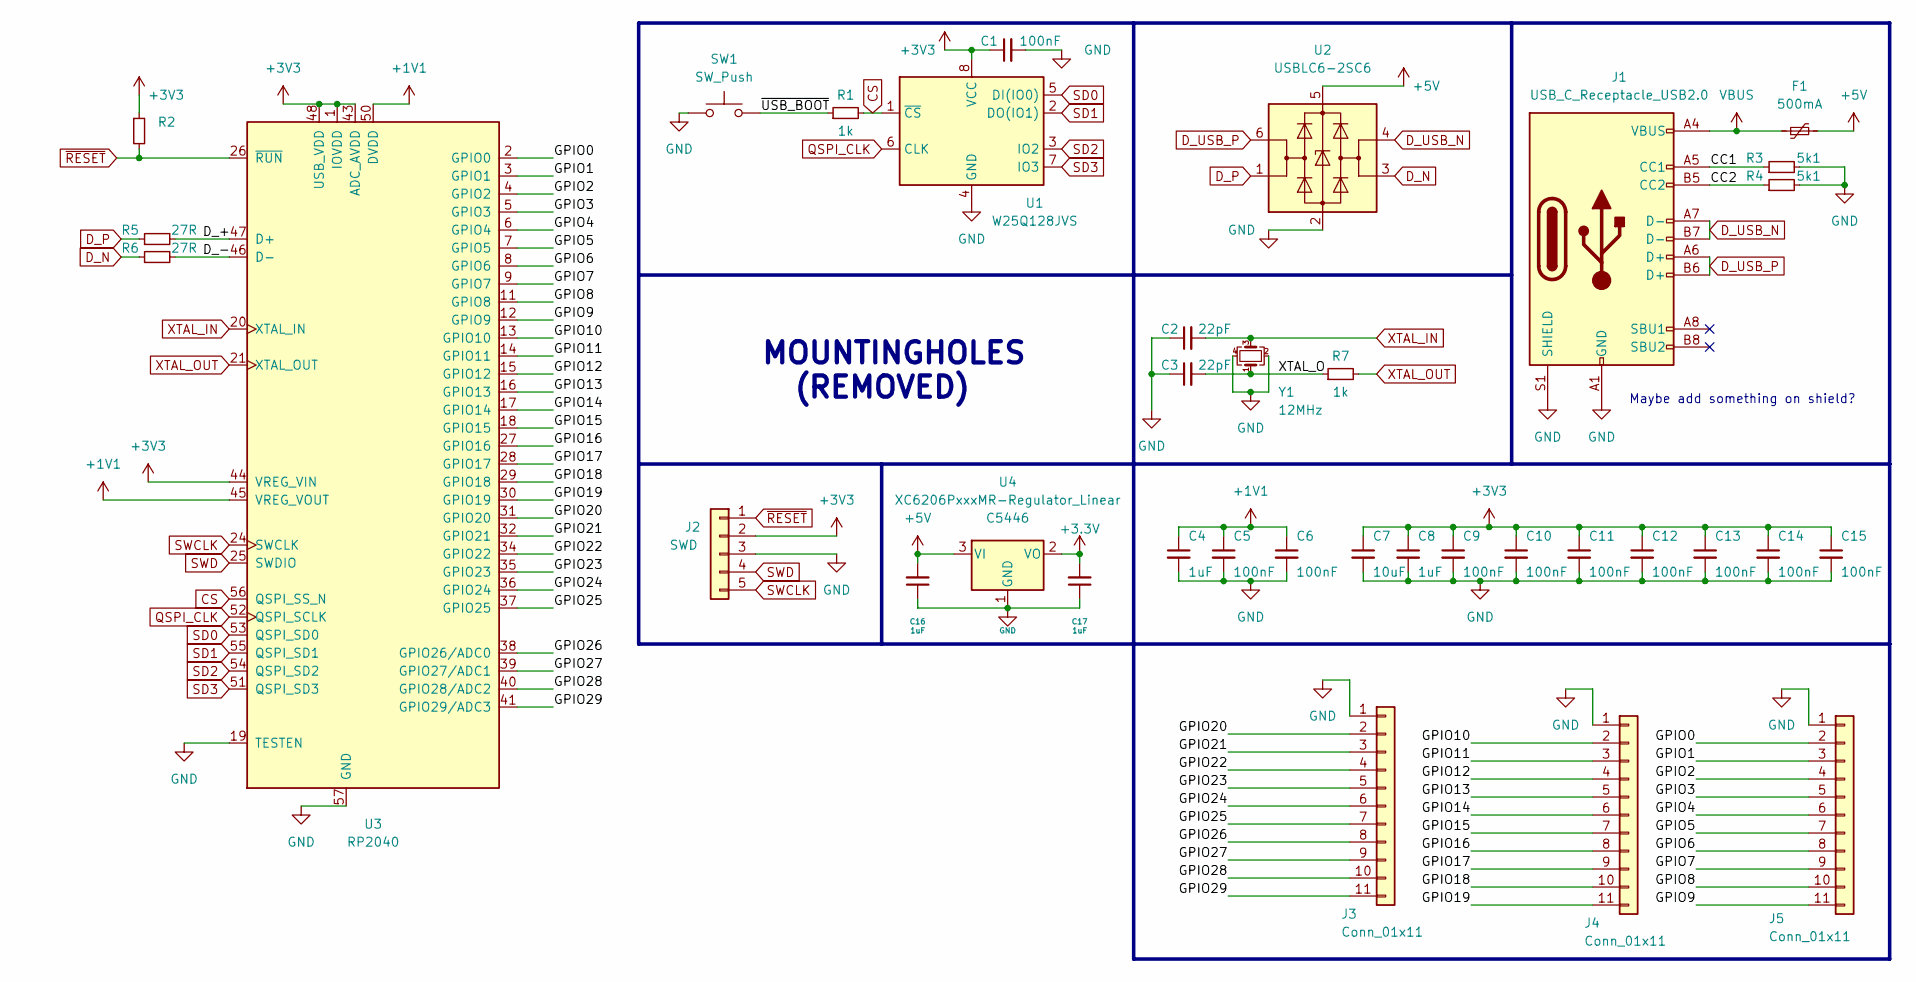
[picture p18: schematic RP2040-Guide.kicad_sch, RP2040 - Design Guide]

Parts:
C1, C5, C6, C9, C10, C11, C12, C13, C14, C15: 100nF; C_0402_1005Metric; LCSC C1525
C2, C3: 22pF; C_0402_1005Metric; LCSC C1555
C4, C8, C16, C17: 1uF; C_0402_1005Metric; LCSC C52923
C7: 10uF; C_0402_1005Metric; LCSC C15525
F1: 500mA; Fuse_1206_3216Metric; LCSC C70076
J1: USB_C_Receptacle_USB2.0; USB_C_Receptacle_HRO_TYPE-C-31-M-12; LCSC C165948
J2: SWD; PinSocket_1x05_P2.54mm_Vertical
J3, J4, J5: Conn_01x11; PinSocket_1x11_P2.54mm_Vertical
R1, R7: 1k; R_0402_1005Metric; LCSC C11702
R2: LCSC C11702
R3, R4: 5k1; R_0402_1005Metric; LCSC C25905
R5, R6: 27R; R_0603_1608Metric; LCSC C25190
SW1: SW_Push; PinSocket_1x02_P2.54mm_Vertical
U1: W25Q128JVS; SOIC-8_5.23x5.23mm_P1.27mm; LCSC C131025
U2: USBLC6-2SC6; SOT-23-6; LCSC C2827654
U3: RP2040; RP2040-QFN-56; LCSC C2040
U4: XC6206PxxxMR-Regulator_Linear; SOT-23; LCSC C5446
Y1: 12MHz; Crystal_SMD_3225-4Pin_3.2x2.5mm; LCSC C9002

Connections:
+1V1: C4.1, C5.1, C6.1, U3.23 (DVDD), U3.45 (VREG_VOUT), U3.50 (DVDD)
+5V: C16.2, F1.2, U2.5 (VBUS), U4.3 (VI)
/CC1: J1.A5 (CC1), R3.1
/CC2: J1.B5 (CC2), R4.1
/D_+: R5.2, U3.47 (D+)
/D_-: R6.2, U3.46 (D-)
/GPIO0: J5.2, U3.2 (GPIO0)
/GPIO1: J5.3, U3.3 (GPIO1)
/GPIO2: J5.4, U3.4 (GPIO2)
/GPIO3: J5.5, U3.5 (GPIO3)
/GPIO4: J5.6, U3.6 (GPIO4)
/GPIO5: J5.7, U3.7 (GPIO5)
/GPIO6: J5.8, U3.8 (GPIO6)
/GPIO7: J5.9, U3.9 (GPIO7)
/GPIO8: J5.10, U3.11 (GPIO8)
/GPIO9: J5.11, U3.12 (GPIO9)
/GPIO10: J4.2, U3.13 (GPIO10)
/GPIO11: J4.3, U3.14 (GPIO11)
/GPIO12: J4.4, U3.15 (GPIO12)
/GPIO13: J4.5, U3.16 (GPIO13)
/GPIO14: J4.6, U3.17 (GPIO14)
/GPIO15: J4.7, U3.18 (GPIO15)
/GPIO16: J4.8, U3.27 (GPIO16)
/GPIO17: J4.9, U3.28 (GPIO17)
/GPIO18: J4.10, U3.29 (GPIO18)
/GPIO19: J4.11, U3.30 (GPIO19)
/GPIO20: J3.2, U3.31 (GPIO20)
/GPIO21: J3.3, U3.32 (GPIO21)
/GPIO22: J3.4, U3.34 (GPIO22)
/GPIO23: J3.5, U3.35 (GPIO23)
/GPIO24: J3.6, U3.36 (GPIO24)
/GPIO25: J3.7, U3.37 (GPIO25)
/GPIO26: J3.8, U3.38 (GPIO26/ADC0)
/GPIO27: J3.9, U3.39 (GPIO27/ADC1)
/GPIO28: J3.10, U3.40 (GPIO28/ADC2)
/GPIO29: J3.11, U3.41 (GPIO29/ADC3)
/XTAL_O: C3.2, R7.1, Y1.1
/~USB_BOOT: R1.1, SW1.2
CS: R1.2, U1.1 (~CS), U3.56 (QSPI_SS_N)
D_N: R6.1, U2.3 (I/O2)
D_P: R5.1, U2.1 (I/O1)
D_USB_N: J1.A7 (D-), J1.B7 (D-), U2.4 (I/O2)
D_USB_P: J1.A6 (D+), J1.B6 (D+), U2.6 (I/O1)
GND: C1.2, C2.1, C3.1, C4.2, C5.2, C6.2, C7.2, C8.2, C9.2, C10.2, C11.2, C12.2, C13.2, C14.2, C15.2, C16.1, C17.1, J1.A1 (GND), J1.A12 (GND), J1.B1 (GND), J1.B12 (GND), J1.S1 (SHIELD), J2.3, J3.1, J4.1, J5.1, R3.2, R4.2, SW1.1, U1.4 (GND), U2.2 (GND), U3.19 (TESTEN), U3.57 (GND), U4.1 (GND), Y1.2, Y1.4
QSPI_CLK: U1.6 (CLK), U3.52 (QSPI_SCLK)
SD0: U1.5 (DI(IO0)), U3.53 (QSPI_SD0)
SD1: U1.2 (DO(IO1)), U3.55 (QSPI_SD1)
SD2: U1.3 (IO2), U3.54 (QSPI_SD2)
SD3: U1.7 (IO3), U3.51 (QSPI_SD3)
SWCLK: J2.5, U3.24 (SWCLK)
SWD: J2.4, U3.25 (SWDIO)
VBUS: F1.1, J1.A4 (VBUS), J1.A9 (VBUS), J1.B4 (VBUS), J1.B9 (VBUS)
XTAL_IN: C2.2, U3.20 (XTAL_IN), Y1.3
XTAL_OUT: R7.2, U3.21 (XTAL_OUT)
~RESET: J2.1, R2.2, U3.26 (~RUN)

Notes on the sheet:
MOUNTINGHOLES (REMOVED)
Maybe add something on shield?

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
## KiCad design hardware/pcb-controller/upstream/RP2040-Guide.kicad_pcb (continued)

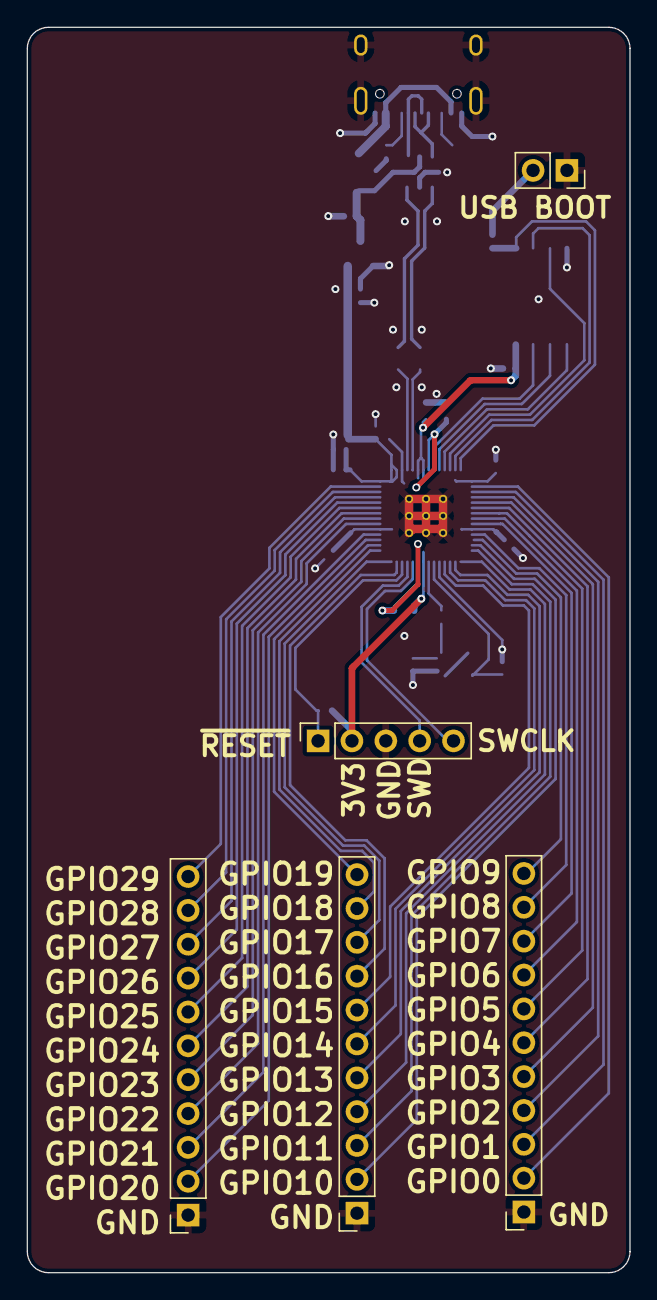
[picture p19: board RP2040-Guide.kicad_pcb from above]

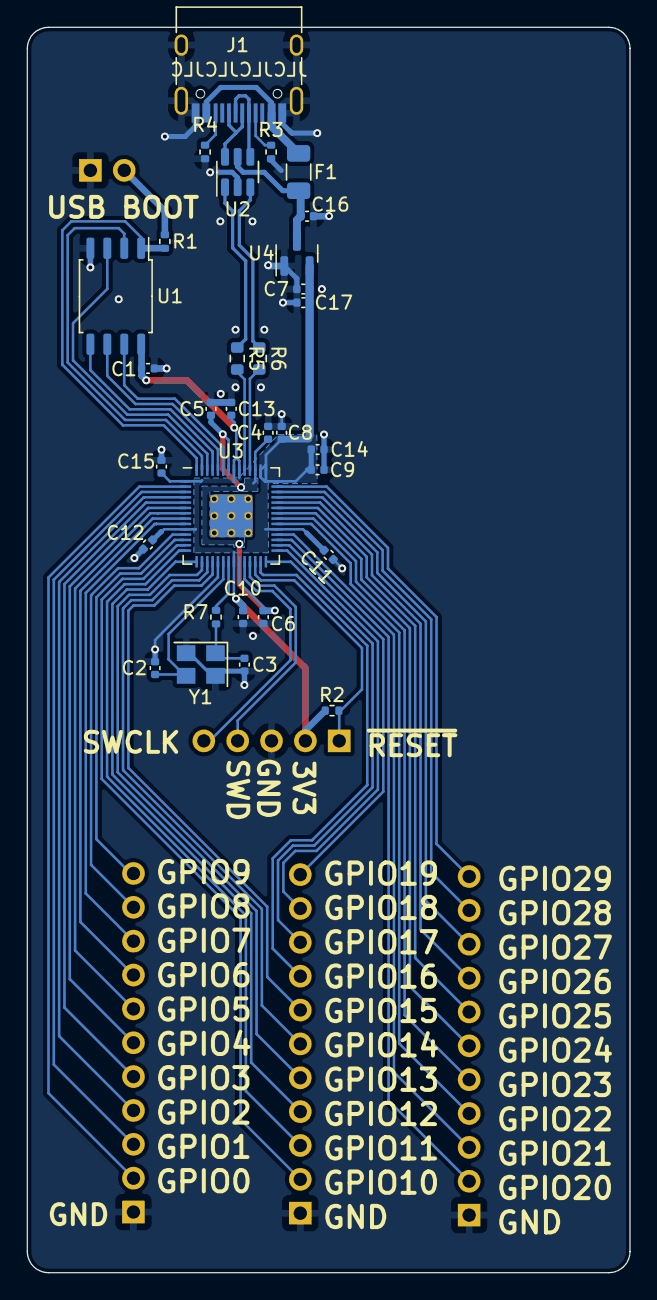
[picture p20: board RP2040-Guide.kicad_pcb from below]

Board: 2 copper layers, 45.2 x 93.4 mm, 36 parts (31 on the bottom side), 56 nets.

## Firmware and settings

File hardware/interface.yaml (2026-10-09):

# Interface contract between the PCB designs and the case CAD.
#
# Both sides READ this file. Neither side owns it. It carries only what
# crosses the boundary between electrical and mechanical -- nothing that
# lives wholly inside one of them.
#
# Changing anything here after gate G2 (see docs/WORKFLOW.md) means:
# bump `version`, add a `changelog` line, re-run the virtual fit, and
# re-print the affected coupon. That discipline is the whole point.

version: 13
units: mm
key_unit: 19.05

changelog:
  - "v1 - initial contract. Values marked TODO are unresolved and block G2."
  - "v2 - Cirque is TM040040 (40 mm), not TM035035. Both pods now share a
     50 mm outside ring diameter for visual symmetry. Left pod moved 2.9 mm
     outboard to hold 5 mm clearance with the larger ring. Right unchanged."
  - "v3 - corrected the pod stack. The sensor sits ABOVE the bearing on a
     static centre post; it is not encircled by it. The bore only has to
     pass the post and its cable, so stock bearings fit after all and the
     v2 claim that none did was wrong. 6806-2RS picked."
  - "v4 - display module resolved: Waveshare SKU 19192, 1.28in GC9A01.
     37.5 mm round PCB, 40.4 mm overall including the header tab, 32.4 mm
     active glass. Closes the module_od TODO. Both figures fit inside the
     50 mm ring, so the tab hides within the pod."
  - "v5 - main PCB outlines exported to hardware/outlines/ for the case.
     Left 148.97 x 120.74, right 167.21 x 120.74. Pod centres recorded in
     PCB coordinates; the pod ring overhangs the main board edge by 2.3 mm
     (left) and 1.5 mm (right), so the two boards overlap in plan view."
  - "v6 - switch-plate cutouts exported. 14.00 x 14.00 mm with 0.5 mm
     corner reliefs per marbastlib plate library; the 2.25u Shift also gets
     two 6.75 x 14.0 mm stabiliser cutouts. Replaces the LED light holes as
     the geometry the case consumes."
  - "v7 - controller pin assignment fixed: 27 of 30 GPIO used, 3 spare.
     GP0/GP1 are dual-function (SPI0 RX/CSn or I2C0 SDA/SCL), which defers
     the Cirque bus decision to firmware and knob-module wiring rather than
     baking it into the controller. See docs/CONTROLLER.md."
  - "v8 - split jack changed to PJ-320A. PJ325 (C26230) is 12.3 mm tall and
     exceeded max_height_above_pcb of 10.0; PJ-320A is 6 mm. Pole count on
     both parts is to be verified by pinout, not by pin count."
  - "v9 - FFC connectors fixed at 0.5 mm, right-angle, bottom contact:
     HC-FPC-0.5-14P-FH20 (C19273929) for the knob, 20P sibling for the main.
     Vertical variants rejected -- the ribbon would need bend headroom the
     10 mm envelope lacks."
  - "v10 - split link changed from a 3.5 mm jack to USB-C. The jack's 0.5 A
     rating, not the supply, was capping per-key RGB at ~17% of full white;
     USB-C carries 3 A and lifts that to ~45%. CC pins unconnected, serial on
     SBU1+SBU2 tied, split VBUS fused."
  - "v11 - controller carries the 20-pin main FFC footprint on TWO edges,
     one populated per half. Each half's J1 sits on its own inner board
     edge, so the two cable approaches are mirror images, and a mirror is
     not a rotation. Absorbing it in controller copper keeps one cable type,
     one pinout and one firmware. The case must admit the ribbon from the
     correct side per half; positions_controller and mounting_holes must
     record WHICH edge is populated on each. See CONTROLLER.md §2."
  - "v12 - controller turned 90 degrees: 35 wide x 50 deep, parts on the
     B.Cu side, so the 50 mm side edges carry the main FFC and split
     USB-C. Envelope extent unchanged. Four M2 mounting holes, one per
     corner -- M2 rather than the project's M3 because an M3 head at the
     front-left corner would land on the knob FFC. See CONTROLLER.md §1."
  - "v13 - controller lengthened from 50 to 57 mm (35 wide x 57 deep) to
     give the routing room. Front mounting holes move with the front edge,
     y 47 -> 54. Side-edge connectors swapped so the 20-pin main FFCs get
     the roomier lower half: from the outline's rear-left corner, split
     USB-C J10 (left) / J9 (right) centred at y 29, main FFC J6 (left) /
     J7 (right) at y 41.8; host USB-C J1 on the rear edge and knob FFC J8
     on the front edge, x 12.5. Per half, the left populates J6 + J9 and
     the right J7 + J10 (CONTROLLER.md §2). See CONTROLLER.md §6 results."

# ---------------------------------------------------------------------------
# Upstream truth. Derived, never hand-edited.
# ---------------------------------------------------------------------------
layout:
  source: hardware/layout/hasukey-both.kle.json
  resolved: hardware/layout/keys-resolved.json
  pods: hardware/layout/pods.json
  regenerate: "python3 hardware/layout/kle_parse.py && python3 hardware/layout/place.py"
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

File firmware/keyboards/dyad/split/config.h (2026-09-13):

// Dyad -- Phase 1 split bring-up (steps 7 and 8).
//
// Two WinWin Pico_Mini RP2040 boards over a 3-conductor TRS cable.
// See docs/PHASE1.md.

#pragma once

// ---- Split link ----------------------------------------------------------
// HALF-duplex: a TRS cable has three conductors (VCC, GND, DATA), so there is
// no second wire for a separate RX. PLAN.md specced full-duplex over TRRS;
// see docs/PHASE1.md section 7a for why the bench deviates.
#define SERIAL_USART_TX_PIN GP0
#define SERIAL_USART_SPEED  460800

// Handedness is hardwired, matching the shipping design's approach.
// Left board: GP12 -> 3V3.   Right board: GP12 -> GND.
// (pin declared in keyboard.json; high = left is QMK's default)

// ---- Pointing device lives on the RIGHT (slave) half ---------------------
// This is the arrangement PLAN.md section 5 chose: USB in the left, so the
// display renders from master-local state and the Cirque syncs across.
#define SPLIT_POINTING_ENABLE
#define POINTING_DEVICE_RIGHT

// ---- SPI0 for the Cirque, right half only --------------------------------
#define SPI_DRIVER   SPID0
#define SPI_SCK_PIN  GP2
#define SPI_MOSI_PIN GP3
#define SPI_MISO_PIN GP4

#define CIRQUE_PINNACLE_SPI_CS_PIN  GP5
#define CIRQUE_PINNACLE_SPI_DIVISOR 8
#define CIRQUE_PINNACLE_DIAMETER_MM 40

// ---- Bootloader ----------------------------------------------------------
#define RP2040_BOOTLOADER_DOUBLE_TAP_RESET
#define RP2040_BOOTLOADER_DOUBLE_TAP_RESET_TIMEOUT 200U

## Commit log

2026-09-13 Cirque TM040040 (40mm); both pods to a matched 50mm ring OD
    Actual hardware is a 40 mm Cirque, not the 35 mm assumed, and both pods
    should share one outside diameter so the halves look like a matched pair.
    Geometry consequences, re-solved rather than estimated:
    - Left pod grows 45 -> 50 mm OD. At its old centre that dropped clearance
    to 2.7 mm, under the 5 mm floor, so it moves 2.9 mm outboard to
    (8.85, 4.20) and recovers 5.2 mm. Right pod unchanged at (8.40, 4.20);
    it was already a 50 mm ring. Both halves now sit identically clear of
    their neighbours: 5.2 mm to the thumb key, 5.7 mm to the other.
    - Left board extent grows 188.24 -> 193.59 mm. Still fits A4 landscape.
    Mechanism is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
    [interface.yaml]
2026-09-13 Correct pod stack: sensor sits above the bearing, not inside it
    The previous commit claimed no standard bearing fits the right pod. That
    was wrong, and it was wrong because of a bad geometric assumption: it
    treated the bearing as coplanar with the sensor, encircling it, which
    forced a bore >= 42 mm to clear the 40 mm Cirque.
    The sensor actually sits ABOVE the mechanism. A static centre post rises
    through the bearing bore and cantilevers the display or trackpad over the
    moving parts, while the ring turns on the outer race below. So the bore
    only has to pass the post and its cable, ~12 mm, and never sees the
    sensor diameter at all.
    That reopens ordinary bearings. With a 50 mm ring and a ~2.2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
    [interface.yaml]
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2026-09-13 Add the EC11 encoder to dyad/proto
    Rotary on GP10/GP11, clear of SPI0 (GP2-GP5) and the dummy matrix
    (GP6-GP9). Mapped to volume down/up via encoder_map, which also exercises
    the extrakey consumer-control path. Compiles clean.
    Readme now carries the full bench wiring, including a way to knock off
    step 2 at the same time: the EC11's push switch is just a normally-open
    switch, so wiring it into matrix position [0][0] through a 1N4148 proves
    the matrix scan without needing separate switches.
    Also recorded the two symptoms that look like faults but are not: a
    detent/step mismatch is the encoder resolution setting, and a reversed
    direction is just pin_a and pin_b swapped.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
    [keymap.c]
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2026-09-13 Split the KLE per half; close module_od from the Waveshare datasheet
    hardware/layout/split_kle.py emits dyad-left.kle.json and
    dyad-right.kle.json from the combined "Hasukey both" source, normalised so
    each half starts near the origin. Needed because kicad-kbplacer consumes a
    single-board KLE.
    The generator emits one key per KLE row with explicit cursor deltas, then
    verifies itself: it re-parses its own output with an independently inlined
    deserialiser and compares every key centre against the original. Left 32
    keys and right 37 keys both round-trip with max error 1.3e-15 u, i.e.
    float noise.
    Display resolved as Waveshare SKU 19192: 37.5 mm round PCB, 40.4 mm
    overall including the header t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
    [interface.yaml]
2026-09-13 Generate the left and right main PCBs from the layout
    hardware/generate_main_pcbs.py builds both boards from the per-half KLE
    via kbplacer. Reproducible end to end: KLE -> matrix annotation ->
    schematic + PCB with switches, diodes, stabilizers, per-key LEDs and their
    decoupling caps, plus row/column and switch-diode routing.
    Result: left 32 switches / 32 diodes / 32 LEDs / 32 caps / 1 stabilizer,
    outline 149.4 x 121.1 mm. Right 37 of each, 167.6 x 121.1 mm. Matrix comes
    out 5x7 and 5x8, matching what PLAN.md section 0 predicted from key counts.
    Per-key RGB is SK6812MINI-E as chosen. Stock KiCad 10 turns out to ship
    both the symbol and a ReverseMount footprint, so nothing had to be drawn
    or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
    [dyad-main-left-led-chain.kicad_sch, dyad-main-left.kicad_pcb, dyad-main-left.kicad_sch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]
2026-09-13 Place switches on the back so hotswap sockets are on the underside
    Caught in review: the sockets were on the same side as the switches.
    marbastlib's hotswap footprint carries its socket pads on F.Cu and draws
    its pin holes mirrored -- it is drawn as seen from underneath and must be
    placed on the back. kbplacer defaults to front, so the sockets landed on
    the switch side. Fixed with -s "SW{} 0 BACK"; stabilizers follow (they are
    purely mechanical NPTH and X-symmetric, so flipping is a no-op for them).
    Now every component is on the underside and switches insert from the top,
    as a hotswap board should be. Verified: SW1's hotswap SMD pads are on
    B.Cu, and the pin1->pin2 vector is (-6.35, 2.54),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
    [dyad-main-left-led-chain.kicad_sch, dyad-main-left.kicad_pcb, dyad-main-left.kicad_sch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]
2026-09-13 Fix LED offset and the placement errors it exposed
    Working out the LED position turned up three further placement bugs.
    Left board: 1151 -> 581 DRC violations, 220 -> 188 unconnected.
    LED offset. ebastler's MX_SK6812MINI-E add-on -- a rear-mount SK6812MINI-E
    for regular MX footprints -- puts its pads at y 4.33/5.83, centroid
    (0, +5.08): 5.08 mm south of the switch centre, one fifth of an inch. Its
    pad geometry matches KiCad's stock ReverseMount footprint almost exactly
    (x +-2.6 vs +-2.73, same +-0.75 in y), so the maintained stock footprint
    drops in at that offset. At the switch centre it fouled the MX centre-post
    hole by 0.12 mm.
    Switch rotation. The switches were 180 deg from convention: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
    [dyad-main-left-led-chain.kicad_sch, dyad-main-left.kicad_pcb, dyad-main-left.kicad_sch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]
2026-09-13 Move the diode clear of the hotswap socket pads
    Caught in review: the diode sat on top of a hotswap socket pad.
    Confirmed in board coordinates -- the pad-2 socket SMD pads are at
    (4.34,-5.08) and (6.09,-5.08), and the diode was at (6.20,-5.08),
    directly on them.
    Moved to (+8.40,-5.08) rotated 90 deg, as suggested. Position was solved
    rather than estimated: the closest placement to the pad-2 socket it has to
    reach, with at least 0.4 mm clearance to every pad of the switch, LED, cap
    and the four neighbouring key cells. Achieves 0.43 mm clearance and a
    2.3 mm route. Verified the anode faces the switch and the cathode carries
    the ROW net.
    Left board 581 -> 225 DRC violations. Four categories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
    [dyad-main-left-led-chain.kicad_sch, dyad-main-left.kicad_pcb, dyad-main-left.kicad_sch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]
2026-09-13 Export main PCB outlines for the case
    hardware/export_outlines.py writes, per half, into hardware/outlines/:
    a perimeter-only DXF for CAD import, the vertices as JSON for scripted
    CAD, the interior cutouts separately, and a STEP of the populated board
    as the 3D fit reference WORKFLOW section 5 calls for.
    Left 148.97 x 120.74 mm, 23 vertices. Right 167.21 x 120.74 mm, 25
    vertices.
    The perimeter comes from the board's computed polygon outlines rather
    than the raw Edge.Cuts layer, because the reverse-mount LED footprint
    cuts its own light hole and Edge.Cuts therefore carries ~640 extra loops
    per board that are nothing to do with the case. Those are written out
    separately rather than silently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
    [dyad-main-left-outline.dxf, dyad-main-left.kicad_pcb, dyad-main-left.step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]
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2026-09-13 Export switch-plate cutouts instead of LED holes for the case
    The LED light holes belong to the PCB, not the case. What a plate needs is
    a cutout per switch, so hardware/export_plate.py now emits those.
    Geometry comes from marbastlib's own plate library rather than hardcoded
    numbers: 14.00 x 14.00 mm with 0.5 mm corner reliefs for 1u through 1.75u,
    plus two 6.75 x 14.0 mm stabiliser cutouts at x +-8.53..15.28, y -6.0..+8.0
    for 2u and wider. Only the 2.25u Shift is stabilised here. Left produces 34
    loops (31 plain plus 3 for the stabilised key), right 37.
    Key width cannot be taken from the switch footprint: marbastlib's hotswap
    series stops at 1.75u, so kbplacer falls back to 1u and the foo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
    [dyad-plate-left.dxf, dyad-plate-right.dxf]
2026-09-13 Start the controller module: pin assignment and board skeleton
    docs/CONTROLLER.md fixes the pin assignment, connector pinouts and BOM for
    the shared RP2040 module. hardware/generate_controller_outline.py creates
    the board at the agreed 50 x 35 mm envelope with 2 mm corners, verified
    closed. Schematic and layout are hand work from here.
    27 of 30 GPIO used, 3 spare. Only four pins are actually constrained by
    silicon -- SPI0 SCK and MOSI, plus the two below. Chip selects, DC/RST/BL,
    encoder, matrix, split link and RGB are all free choice, because RP2040
    drives software CS on any pin and PIO reaches any pin.
    The pending Cirque bus decision from docs/PHASE1.md section 5a turns out
    not to need m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
    [dyad-controller.kicad_pcb]
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2026-09-13 Switch the split jack to PJ-320A on height grounds
    PJ325 / LCSC C26230 is 18 x 8.1 x 12.3 mm. The controller envelope allows
    10 mm above the PCB, and interface.yaml even named the jack as the tallest
    part -- so the specified part did not fit the specified volume. Neither
    document noticed until the height was questioned.
    PJ-320A is 14.1 x 5 x 6 mm through-hole: less than half the height, 4 mm
    of headroom inside the envelope, and the de-facto split-keyboard jack, so
    cables and spares are commonplace. Through-hole matters here because the
    plan has the jack hand-soldered rather than assembled.
    It also makes 4-pole free again. The earlier preference for 3-pole was
    premised on 4-pole costing som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
    [interface.yaml]
2026-09-13 Fix the FFC connectors: 0.5 mm, right-angle, bottom contact
    Staying at 0.5 mm rather than moving to the 1.0 mm Amphenol F516 that was
    proposed. 1.0 mm buys hand-solderability and current headroom, neither of
    which applies: JLCPCB places these parts, and the doubled 5V/GND
    conductors already give ~1 A against ~0.4 A per half for RGB at capped
    brightness. It would cost board edge -- a 20-position part is ~23 mm wide
    against ~13 mm, on a 50 mm board whose other long edge already carries
    USB-C and the jack.
    Parts: HC-FPC-0.5-14P-FH20 (LCSC C19273929) for the knob connector, and
    the 20-position sibling of the same family for the main. Flip-top lock,
    SMD, JLCPCB-stocked.
    Right-angle specifically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
    [interface.yaml]
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2026-09-13 Correct the LDO rationale and flag that it is not a drop-in
    Two fixes to the LDO delta.
    The earlier text gave higher dropout as a reason to leave the XC6206.
    That is wrong: dropout only matters when the input approaches the output,
    and from 5 V to 3.3 V there is 1.7 V of headroom, so both parts are
    comfortable. Current margin is the only real argument -- load is ~70-130
    mA against a 200 mA rating, with the GC9A01 backlight the unmeasured and
    largest term.
    More importantly, the swap is not a drop-in and the text implied it was.
    XC6206 is SOT-23 3-pin; AP2112K-3.3 is SOT-23-5 with an enable pin. EN
    left floating means the regulator never turns on and the board has no 3V3
    at all, which looks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
    [dyad-controller.kicad_pcb, dyad-controller.kicad_sch]
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2026-09-13 Switch the split link from a 3.5 mm jack to USB-C
    The jack, not the supply, was capping per-key RGB. A 3.5 mm jack is rated
    0.5 A and the slave half's current crosses it, pinning brightness at ~17%
    of full white however generous the source. USB-C carries 3 A on a standard
    cable and lifts that to ~45%, at which point the FFC power conductors
    become the limit instead.
    Still half-duplex. No QMK feature needs the second wire and the split
    transport is request/response regardless -- the connector changed for
    current, not for data.
    This reverses the rejection in section 3, which predated knowing where the
    bottleneck actually was. The stated hazard is real but handled by three
    rules:
    - CC1/CC2 u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
    [interface.yaml]
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2026-09-14 Fix controller DRC/ERC and upgrade the schematic to the KiCad 10 format
    Most of this diff is mechanical. KiCad rewrote the schematic from format
    20211123 (KiCad 6, inherited from the vendored RP2040-designguide) to
    20260306, and the board's zone fill was recomputed and its segment list
    reordered. The substantive changes are small and listed below.
    Schematic:
    - #PWR024 was a "+3.3V" power symbol while the rest of the board uses
    "+3V3". KiCad treats those as two separate rails, so U4's regulator
    output and its 1uF cap C17 were isolated from everything they power.
    Renamed to +3V3; the LDO output now actually reaches the RP2040's
    IOVDD/USB_VDD/VREG_VIN pins and the flash.
    - Added PWR_FL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
    [dyad-controller.kicad_pcb, dyad-controller.kicad_sch]
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2026-09-14 Mirror the JLC order-number text and move it clear of J1
    The JLCJLCJLCJLC placeholder was the only text on B.SilkS without a
    mirror justify, so it would have printed reversed -- every other back-layer
    label on this board already carries mirror=True. Added (justify mirror) to
    match.
    It also sat at (200.787, 33.576), overlapping J1's silkscreen on both
    sides. Moved it to (180, 60), in the empty left-hand region: no footprint
    is west of x=193 in that band, the nearest board edge is 3 mm away, and
    J2's SWD socket pads stop at y=94.
    DRC silkscreen violations 8 -> 5: nonmirrored_text_on_back_layer is gone
    and silk_overlap drops 4 -> 2. The two that remain (J2 vs the SWD label,
    R5 vs R6) and the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
    [dyad-controller.kicad_pcb]
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2026-09-14 Route COL6 clear of LED14's reverse-mount cutout
    COL6's 16.84 mm diagonal ran 0.036 mm from LED14's own Edge.Cuts arc
    against a 0.2 mm rule -- close enough that the routing slot for the
    reverse-mount SK6812MINI-E could have severed the trace. This is the
    footprint-internal Edge.Cuts geometry TOOLS.md already warns about.
    Split the segment at a waypoint offset 0.35 mm perpendicular, away from
    the LED:
    before (170.021,73.660) -----------------------> (158.115,61.754)
    after (170.021,73.660) -> (160.011,64.144) ----> (158.115,61.754)
    Both endpoints are unchanged, so the joins to the adjacent COL6 segments
    are preserved. Closest approach on the two new legs is 2.688 mm and
    2.705 mm from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
    [dyad-main-right.kicad_pcb]
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2026-09-14 Bend auto-routed copper clear of the LED light cutouts
    LED_SK6812MINI-E_..._ReverseMount cuts its own light hole, so the footprint
    carries Edge.Cuts geometry of its own. kbplacer routes rows and columns
    without seeing those holes, and on the right half COL6 lands 0.036 mm from
    LED14's cutout against the 0.2 mm rule -- close enough that the routing slot
    could sever the trace. It reproduces byte-identically on every run, so the
    hand fix in e7043c7 was erased by the very next regeneration.
    _nudge_traces_off_led_cutouts() now runs as a post-processing pass, in the
    same spirit as _propagate_pad_nets. For every copper track that collides
    with a footprint-internal Edge.Cuts shape it splits the tra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
    [dyad-main-left-key-matrix.kicad_sch, dyad-main-left-led-chain.kicad_sch, dyad-main-left.kicad_pcb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]
2026-09-14 Type RP2040 QSPI_SCLK as an output, not an input
    Closes the last ERC error on the controller: "Input pin not driven by any
    Output pins: Symbol U1 Pin 6 [CLK, Input, Line]".
    The fix is on the RP2040, not the flash. W25Q128 pin 6 being an input is
    correct -- a flash chip's clock pin is an input. The defect was that
    Sleep-lib's RP2040 symbol also declared pin 52 QSPI_SCLK as an input, so
    the net had two inputs and nothing driving it. The RP2040 drives that clock
    from its XIP/SSI interface; it is an output. Its siblings were already
    right: QSPI_SD0-SD3 and QSPI_SS_N are all bidirectional, leaving pin 52 the
    odd one out.
    Retyping the W25Q128 end instead would have silenced ERC by declaring the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
    [dyad-controller.kicad_sch]
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2026-09-15 Pour GND and VCC from the generator, and write down what stays manual
    _add_power_pours() fills one rail per layer over the real board outline,
    taken from KiCad's own outline extraction rather than reassembling the 25
    Edge.Cuts segments. Pads connect solid rather than through thermal reliefs:
    everything here is reflow SMD, so thermal relief buys nothing and costs the
    LED rail current capacity. It also sidesteps the starved_thermal class of
    error entirely.
    GND goes on B.Cu, the component side. Every GND pad on these boards is
    B.Cu-only, so the pour reaches all of them with no vias, and each LED's
    decoupling loop to its own capacitor stays local copper rather than going
    pad -> via -> plane ->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
    [dyad-main-left-key-matrix.kicad_sch, dyad-main-left-led-chain.kicad_sch, dyad-main-left.kicad_pcb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]
2026-09-15 Link footprints to their schematic symbols so the PCB can be updated
    kbplacer writes the board and the schematic independently and never
    associates them, so every footprint landed with an empty (path). KiCad
    matches symbols to footprints by that path, so with it blank "Update PCB
    from Schematic" saw all 148 symbols as new and re-added the entire board --
    which made any schematic-side edit impossible to push through. That is what
    blocked reworking the LED chain in the schematic.
    _link_footprints_to_symbols() now writes KiCad's own format,
    <sheet path without the root uuid>/<symbol uuid>, confirmed against the
    controller board that KiCad itself produced, where a root-level symbol
    carries /<sy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
    [dyad-main-left-key-matrix.kicad_sch, dyad-main-left-led-chain.kicad_sch, dyad-main-left.kicad_pcb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]
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2026-09-15 Repair the right half's root sheet uuid
    Schematic parity reported 199 "No corresponding pin found in schematic"
    net_conflict warnings covering every diode, every switch and LED1-LED26.
    None of them were real: the root .kicad_sch carried a uuid that disagreed
    with everything else in the project.
    root .kicad_sch own uuid : ef8e27db...
    child instance paths use : 3624da76...
    .kicad_pro "sheets" Root : 3624da76...
    kicad-cli resolves a footprint's (path) through the root sheet uuid, so with
    the root file disagreeing it could not match a single footprint to its
    symbol and reported every unlabelled-net pad as having no corresponding pin.
    KiCad's GUI resolves through the project structure ins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
    [dyad-main-right.kicad_sch]
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2026-09-16 Right half fully routed: zero unconnected
    413 segments and 37 vias close every connection on main-right. The VCC vias
    bridge the F.Cu pour to the B.Cu-only pads, one per LED/capacitor pair, which
    is what the pour needed to stop being decorative.
    unconnected 145 -> 0
    parity 0 -> 0
    errors 37 -> 37 (all courtyards_overlap)
    shorts 0
    Everything that remains is cosmetic or deliberate:
    132 silk_over_copper reference designators over pad mask openings
    63 silk_overlap designators colliding with each other
    37 courtyards_overlap the diode-under-switch placement, by design
    21 silk_edge_clearance designators past the board edge
    N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
    [dyad-main-right.kicad_pcb]
2026-09-16 Left half fully routed, and repair a dragged board-outline corner
    330 segments and 32 vias close every connection on main-left. Unconnected
    125 -> 0, schematic parity 98 -> 0, no shorts.
    Routing also caught a board-outline break that DRC reported as three
    invalid_outline errors -- "Board has malformed outline (not a closed shape)".
    Nothing was deleted: a three-segment rounded corner had been dragged by
    exactly (-6.137, -4.900) mm, leaving a 2.85 mm gap where it belonged and a
    dangling spur where it landed. Segment count stayed at 23 either way, which
    is why it was not obvious; the tell was four Edge.Cuts endpoints used once
    instead of zero.
    Restored the three segments to their committed co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
    [dyad-main-left-key-matrix.kicad_sch, dyad-main-left-led-chain.kicad_sch, dyad-main-left.kicad_pcb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]
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2026-09-18 Route the FFC connector on the right main PCB
    J1 placed on B.Cu at the left edge and hand-routed, 413 -> 544 segments and
    37 -> 65 vias. Unconnected stays 0 and schematic parity holds. Track widths
    and vias match the rest of the board throughout: 0.2 mm, 0.6/0.3.
    Two things were reworked during routing:
    The row order was reversed at the connector, ascending -> descending, to
    stop the five row traces crossing on their run to J1. Schematic and board
    were both updated, so this is the pinout of record now.
    The LED serpentine was re-laid so horizontal links sit on one layer and
    vertical links on the other. Routing the connector had pinched the B.Cu
    GND pour into three pieces -- two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
    [dyad-main-right.kicad_pcb]
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2026-09-18 Delete the dangling ROW4 stub left by the reroute
    Two F.Cu segments, not one: the 0.063 mm fragment DRC reported at
    (61.28, 114.16) and the diagonal feeding it back to the via at
    (61.60, 113.84). Both hung off that via with nothing at the far end; the
    via's real connection northward is untouched, and unconnected stays 0.
    DRC violations 254 -> 253, which is the pre-connector baseline exactly. The
    remaining 253 are the documented ones: 37 courtyards_overlap from the
    deliberate diode-under-switch placement, and 216 silkscreen findings.
    The one schematic_parity issue is unrelated and still expected -- J1's
    Pinout field text, schematic ahead of board, clearing on the next Update PCB
    from Schema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
    [dyad-main-right.kicad_pcb]
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2026-09-18 Put the main FFC on two controller edges, one populated
    Each half's J1 sits on its own inner board edge, so the two cable
    approaches are mirror images of each other -- and a mirror is not a
    rotation. Turning the controller 180 degrees swaps left/right *and*
    top/bottom, which would put the main FFC on the right edge but USB-C on the
    wrong one. Only flipping the board over truly mirrors it, and that faces
    every component at the case floor and inverts the USB-C port.
    So the controller carries the 20-pin footprint on two edges, wired to the
    same nets, with only the one facing that half's main PCB fitted. Each
    footprint's orientation is chosen independently, so the mirror is absorbed
    in controll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
    [dyad-main-left-key-matrix.kicad_sch]
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2026-09-18 Add the knob FFC to the controller schematic
    J8, Connector_Generic:Conn_01x14 against a newly pulled C19273929
    footprint, all 14 pins wired per CONTROLLER.md §2:
    1=+3V3 2,14=GND 3=SCK(GPIO2) 4=MOSI(GPIO3) 5=D0(GPIO0) 6=D1(GPIO1)
    7=CS(GPIO4) 8=DC(GPIO5) 9=RST(GPIO6) 10=BL(GPIO7) 11=DR(GPIO8)
    12=ENC_A(GPIO9) 13=ENC_B(GPIO10)
    **This clears 11 of the 15 ERC errors that deleting J3/J4/J5 exposed.**
    Errors 15 -> 4. The remaining four are exactly the ones predicted when the
    headers went: GPIO11, which clears with the second USB-C, and GPIO27-29,
    the three genuine spares that want no-connect flags once confirmed final.
    Nothing else moved -- endpoint_off_grid 94, lib_symbol_mismatc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
    [dyad-controller.kicad_sch]
2026-09-18 Add the split-link USB-C, duplicated on both side edges
    J9 and J10, same receptacle and footprint as the host J1 per PLAN.md §5,
    one populated per half -- whichever faces the other half.
    The host port stays a single footprint on the rear edge. The single
    controller orientation the two-FFC decision buys means a rear-edge port
    lands identically in both halves, so the host needs no duplicating. The
    split port is duplicated for **usability, not geometry**: PLAN.md §5 warns
    that "two identical USB-C ports per half invite the wrong cable.
    Distinguish them by case position and labelling." Two ports side by side on
    the rear are not distinguishable by position, and on the slave half there is
    no ho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
    [dyad-controller.kicad_sch]
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
